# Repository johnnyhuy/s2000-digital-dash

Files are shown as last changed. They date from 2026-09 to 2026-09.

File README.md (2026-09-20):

<h1 align="center">
  Honda H-mark
  S2000 wordmark
</h1>

<p align="center">
  
  
  
  
  
  
</p>

> **Unofficial enthusiast / DIY project.** This repository is **not affiliated with, endorsed by, or associated with Honda Motor Co., Ltd.** Honda, S2000, AP1, AP2, and related marks are trademarks of their respective owners. For **personal and educational use** on the bench. The on-screen odometer is **display-only** - the **OEM cluster must stay plugged** so the factory odometer remains the legal one.

<p align="center">
  <strong>Newline JSON in. Selectable AP1 / AP2 face styles out.</strong><br/>
  Phase 1 bench mock for a Raspberry Pi 5 + Wisecoco-class 7&quot; AMOLED overlay.<br/>
  Not a product, not car-ready, not a replacement for the factory cluster.
</p>

<p align="center">
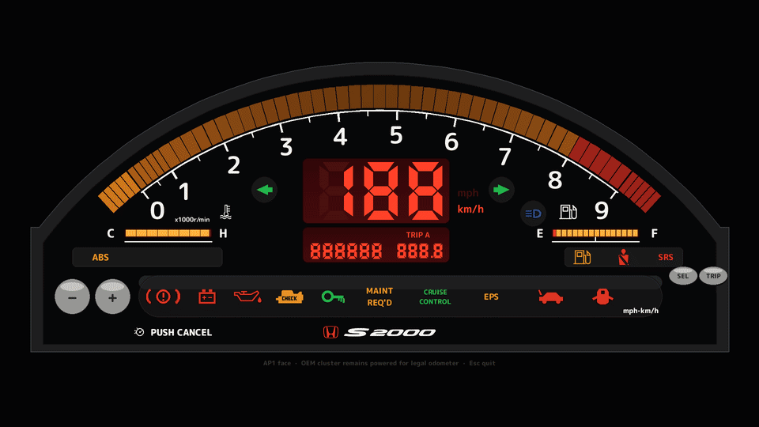
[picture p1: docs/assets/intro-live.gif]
Boot: tach self-test sweep, READY with badges, reveal, then live gauges
  
</p>

<p align="center">
  <sub>Hero is a baked 30 fps intro→live loop (60 fps VP9). Stills are in <a href="shots/"><code>shots/</code></a>. OEM vs UI composites live in <a href="docs/assets/compare/"><code>docs/assets/compare/</code></a>.</sub>
</p>

<p align="center">
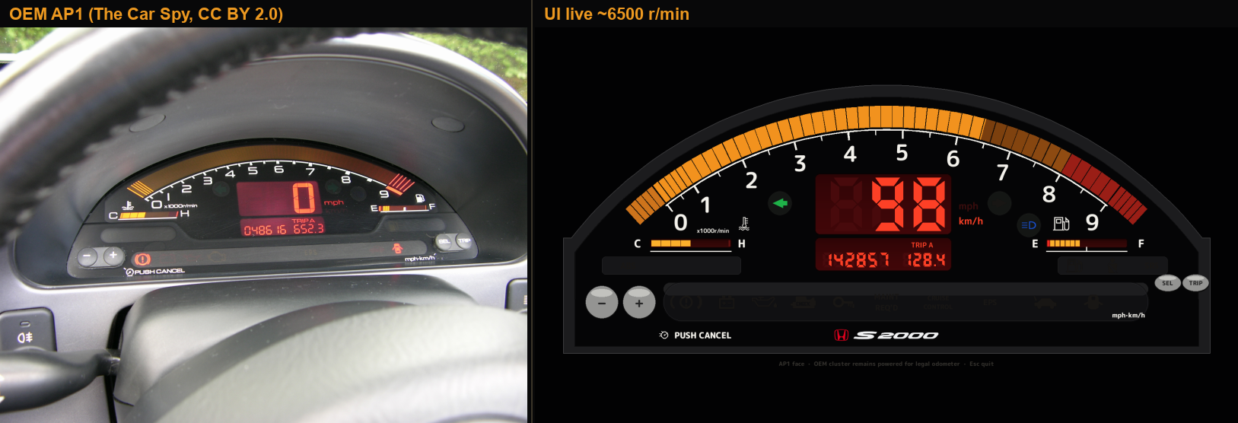
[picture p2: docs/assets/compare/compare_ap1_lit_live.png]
OEM AP1 photo beside the pygame live face
  
</p>
<p align="center">
  <sub>Left: OEM AP1 cluster, <a href="https://www.flickr.com/photos/thecarspy/2644733191/">The Car Spy</a> (<a href="https://creativecommons.org/licenses/by/2.0/">CC BY 2.0</a>). Right: this UI. Sources in <a href="refs/oem/SOURCES.md"><code>refs/oem/SOURCES.md</code></a>.</sub>
</p>

## Features

<table>
<tr>
<td width="50%" valign="middle">

### Face styles (AP1 default, AP2 selectable)

Red 7-seg speed/odo on an **amber tach** in a hooded arched cowl. Flat 2.35:1 elevation - no fake 3D skew.

- **AP1** (default): **horizontal TEMP left / FUEL right** block bars flanking the speed/odo. Tach is the OEM **amber bar graph on a true circular arc** - cells light in 200 rpm steps, red hatch past 9, no needle. Every anchor comes from one shared, photo-derived layout, [`src/face_spec.py`](src/face_spec.py), explained in [`refs/flat/DIMENSIONS.md`](refs/flat/DIMENSIONS.md) and shared with the web harness and the CAD.
- **AP2**: interpretive stacked arched TEMP / FUEL on the right, plus a clock row. Uses [`refs/oem/ap2/`](refs/oem/ap2/) as reference - **not** a pixel-perfect plate.

Toggle in the [web harness](apps/harness/) or `python src/gauge_ui.py --style ap2` (keys `1` / `2` live). Protocol fields stay frozen.

Bar-graph tach **0–9 ×1000** on a circular arc with amber / red hatches past each end, mitred red 7-seg speed, **ODO / TRIP A**, 8-block TEMP and 16-block FUEL. Turn arrows and high beam sit in round wells inside the arc like the OEM; AP1 puts ABS in the left pocket and low fuel / seat belt / SRS in the right pocket. The lower strip carries brake, battery, oil, CEL, immobilizer, maintenance, cruise, EPS, trunk and door warnings. AP2 uses a separate airbag pictogram and relocates the left-side indicators, following the Honda manual.

</td>
<td width="50%">
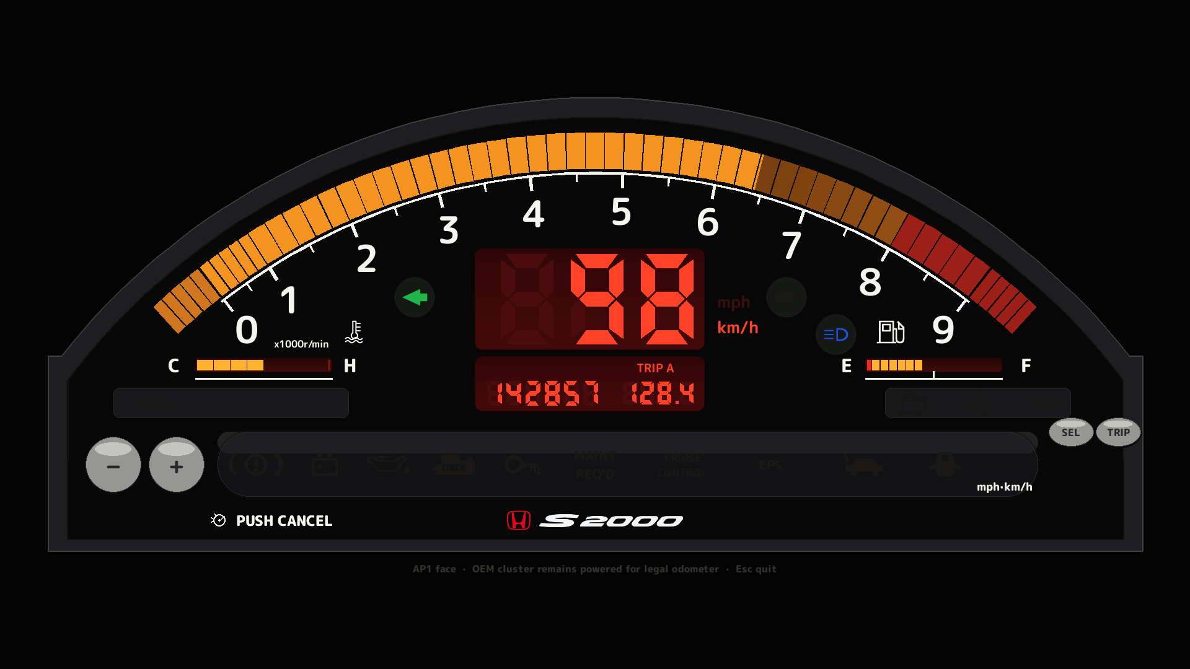
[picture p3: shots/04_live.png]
Live cluster at about 6500 rpm and 98 km/h
  
</td>
</tr>
<tr>
<td width="50%" valign="middle">

### Ignition boot

Skippable with Space or `--no-intro` (web harness: Space or **Skip boot**):

The sweep → branded READY → reveal is a **custom demo animation**, not a verified recording of factory ignition timing. Honda documents individual lamp checks; it does not establish this combined animation.

1. Tach bar fills 0→9 with every lamp and `188` lit (demo bulb check)
2. **READY** with the Honda H-mark and S2000 wordmark
3. Gauge reveal, then live

</td>
<td width="50%">
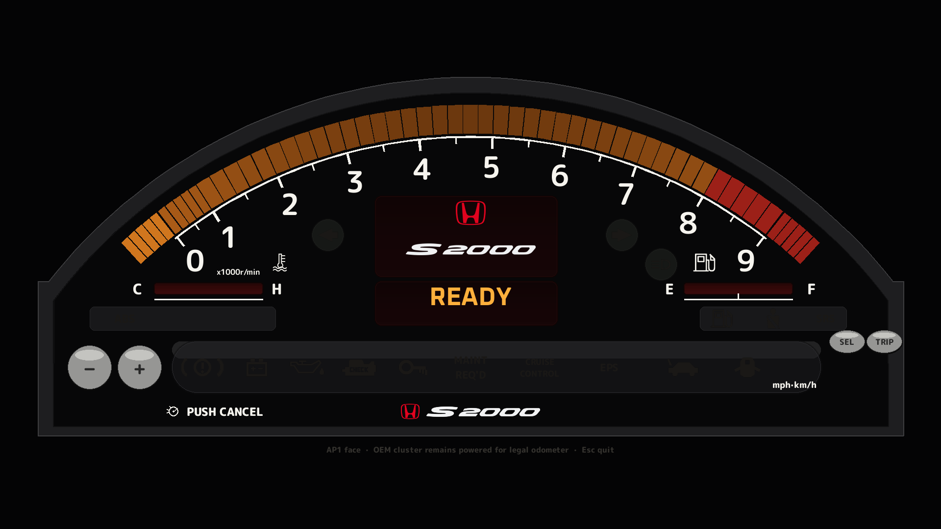
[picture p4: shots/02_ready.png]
READY summary card during boot
  
</td>
</tr>
<tr>
<td width="50%" valign="middle">

### Frozen JSON pipe

One object per line. Field names stay **`rpm`**, **`speed_kmh`**, **`fuel_pct`**, **`ect_c`**, **`batt_v`**, **`odo_km`**, optional **`lamps`**.

Phase 1: `mock_telemetry.py` at 20 Hz. Phase 2: the same schema over UART (`--serial`).

</td>
<td width="50%">
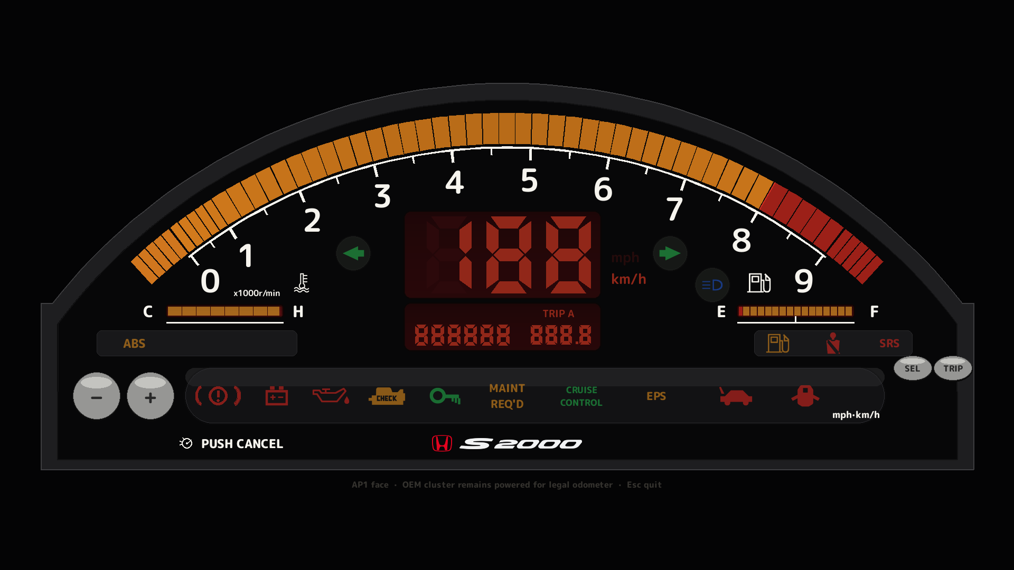
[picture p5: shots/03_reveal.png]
Tach self-test during gauge reveal
  
</td>
</tr>
<tr>
<td width="50%" valign="middle">

### Overlay path

The factory cluster stays powered. This UI is an overlay so the **legal odometer** keeps counting on the OEM unit.

Phase 1 is **wall power** on the bench - no ESP32, no car taps. Phase 2 will add high-Z taps later.

</td>
<td width="50%">
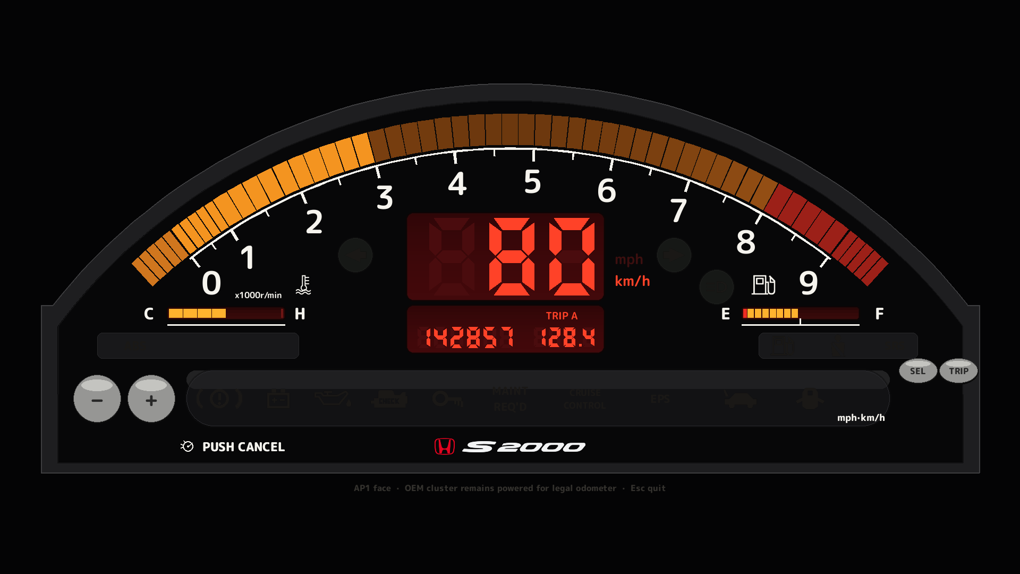
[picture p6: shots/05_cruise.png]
Cruise still with overlay caption under the module
  
</td>
</tr>
<tr>
<td width="50%" valign="middle">

### Placeholder CAD

OpenSCAD in [`cad/`](cad/): overlay 7" bezel + generic connector shells, and an Option 1 **replace-face** stack in [`cad/replace_face/`](cad/replace_face/) whose mask windows and hood crown are generated from the same `face_spec.py` lock as the UI, over a 7" panel pocket. Millimetres are still estimates - bay **callipers required** before any cabin print. **PETG or ASA - not PLA.**

</td>
<td width="50%">
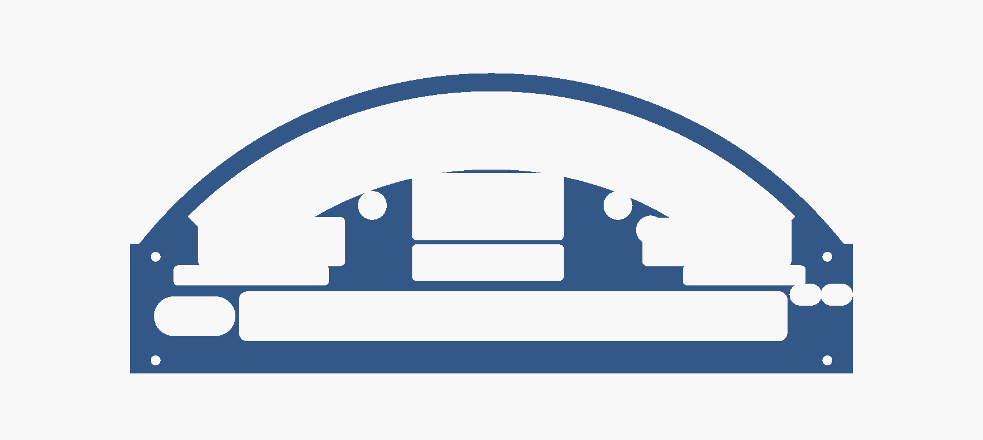
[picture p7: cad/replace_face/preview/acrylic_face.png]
Replace-face mask plate generated from the face lock: tach sector, LCD, side-bar, telltale and button windows
  
</td>
</tr>
</table>

---

## Install

Python **3.11+**. Prefer **[uv](https://docs.astral.sh/uv/)** (`pyproject.toml` + `uv.lock`). Dummy SDL is enough for tests and screenshots; a real display is only needed for the fullscreen Pi session.

```bash
git clone https://github.com/johnnyhuy/s2000-digital-dash.git
cd s2000-digital-dash
uv sync
```

Dev extras (pytest, pyserial for UART mocks):

```bash
uv sync --extra dev
```

`requirements.txt` / `requirements-dev.txt` stay as pip mirrors. On the Pi, `export DISPLAY=:0` if the box boots headless to a desktop session.

## Web cluster harness (no Pi)

Shareable Next.js demo of the same face, drawn as one SVG straight from the exported lock (`apps/harness/lib/faceSpec.json`) - red mitred 7-seg, amber bar-graph tach, side block bars, telltale strip and buttons all share pygame's numbers. Client-side mock loop (play/pause, **AP1 / AP2** face, idle / cruise / VTEC / warn) and the same sweep → READY → reveal boot as the Pi UI. Cluster type is self-hosted M PLUS Rounded 1c; telltales are inline ISO pictograms.

<p align="center">
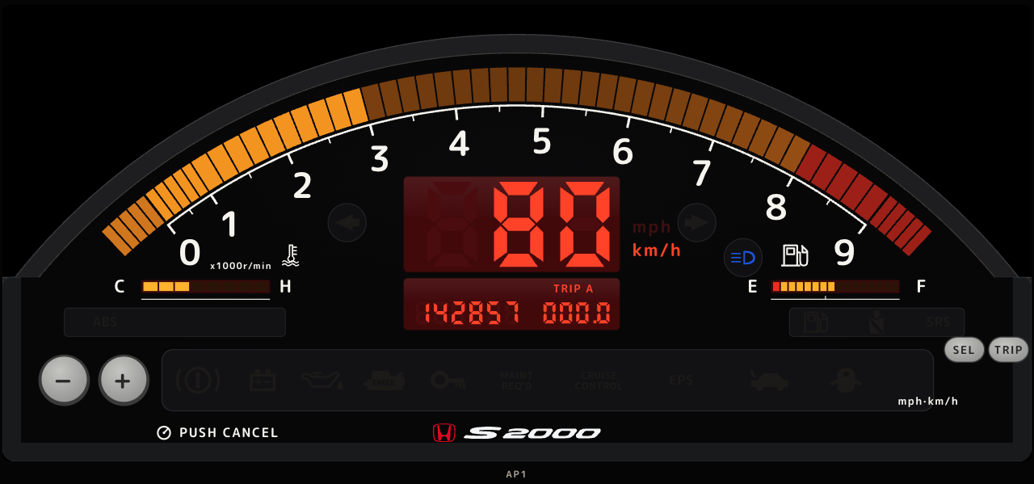
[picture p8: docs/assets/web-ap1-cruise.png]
Web AP1 cruise: digital speed, amber bar graph and shared warning pictograms
  
</p>
<p align="center">
  <sub>Web AP1 cruise. Warn and AP2 stills: <a href="docs/assets/web-ap1-warn.png"><code>web-ap1-warn.png</code></a>, <a href="docs/assets/web-ap2-warn.png"><code>web-ap2-warn.png</code></a>.</sub>
</p>

```bash
cd apps/harness
npm install
npm run dev    # http://localhost:3000  (also /harness)
npm run build
```

**Vercel:** create a project with **Root Directory** `apps/harness` (Next.js preset). See [`apps/harness/README.md`](apps/harness/README.md).

The banner on that page is the same **unofficial DIY / not Honda Motor Co.** disclaimer as this README.

The web page follows the system theme, with an **Appearance** selector for Light / Dark / System. The instrument itself stays black with unchanged warning colours. The choice persists locally.

[Light web preview](docs/assets/web-ap1-light.png) · [Dark web preview](docs/assets/web-ap1-dark.png)

**OLED preview:** open `/display?style=ap1` (or `ap2`) in a fullscreen browser on the Pi. This route uses mock telemetry, hides the web controls, and fits the complete face without stretching or cropping. Pygame `--car --size 1280x720` renders at the chosen panel resolution and uses aspect-preserving fit. Replace `1280x720` with the OLED’s configured native landscape resolution. Neither route establishes physical mounting dimensions.

The target is Johnny's **7-inch OLED + Raspberry Pi**, for a **2001 AP1**. The exact panel model, native resolution and active area are still unrecorded. See [the reference audit](docs/iterations/0018-oem-display-audit.md) for sources, corrected proportions, validation and remaining limits.

## Bench studio and 3D setup

The web workspace now separates the instrument preview from its face, drive-condition
and playback controls. Readouts sit below the preview; raw telemetry is collapsed
until needed. **Replay startup** works without changing the selected face.

Open **3D setup** (`/setup`) to orbit the complete display enclosure, inspect its
assembled, exploded or electronics-only view, select front/rear cameras, or expand
the viewer fullscreen. GLB scenes and a ZIP of CAD source + four prototype STLs
are downloadable from the viewer. The 3D library loads only on this route.

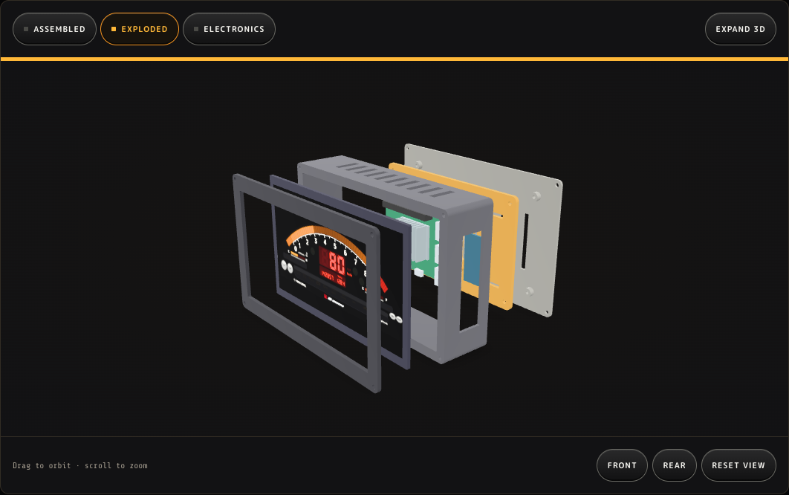
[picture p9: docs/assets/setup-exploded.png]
Digital display setup


The new [`cad/setup/`](cad/setup/README.md) model includes a rectangular OLED frame,
vented enclosure, removable Pi carrier and rear cover, plus Pi/connector/cooler
clearance proxies. It complements the existing arched mask option. The panel and
vehicle-fit dimensions remain provisional; the model is a bench layout, not an
installation-ready housing.

## Run

```bash
# Bench mock pipe (repo root)
uv run python src/mock_telemetry.py | uv run python src/gauge_ui.py

# Same thing from src/
cd src && python mock_telemetry.py | python gauge_ui.py
```

Fullscreen by default. Esc or Q quits.

| Flag | What it does |
| --- | --- |
| `--windowed` | 1920×1080 window instead of fullscreen |
| `--intro` / `--no-intro` | Force or skip the boot sequence (intro is on unless `--smoke`) |
| `--smoke` | Dummy SDL, draw a few frames, exit (CI / Pi check; no live pipe needed) |
| `--size WIDTHxHEIGHT` | Panel render resolution, e.g. `1280x720` (default `1920x1080`) |
| `--screenshot DIR` | Write `01_sweep.png` … `05_cruise.png` into DIR |
| `--serial [PORT]` | Phase 2 UART stub (needs `pyserial`; default `/dev/ttyUSB0`) |
| `--style ap1\|ap2` | Face layout. **ap1** (default) horizontal TEMP/FUEL flanking the speedo; **ap2** arched side gauges |

```bash
# Fast health check (same commands CI runs)
uv sync --extra dev
uv run pytest
SDL_VIDEODRIVER=dummy uv run python src/gauge_ui.py --smoke
uv run python -m mocks.esp32_uart --count 25 --immediate | uv run python src/gauge_ui.py --smoke
uv run python scripts/ui_harness.py --check

# Rebuild stills
uv run python src/gauge_ui.py --smoke --screenshot shots

# OEM | UI side-by-sides
uv run python scripts/compare_oem.py

# Rebuild stills + 30 fps intro GIF / 60 fps VP9 (needs ffmpeg)
uv run python scripts/bake_showcase.py
```

Stdin is newline JSON. Phase 2 UART is the same schema on `--serial`.

## Mocked environments (no hardware)

Pi UI and a future ESP32 source can be exercised in isolation. Field names stay frozen.

```bash
# Headless Pi cluster (dummy SDL - CI / no display)
SDL_VIDEODRIVER=dummy uv run python src/gauge_ui.py --smoke --screenshot /tmp/shots

# Existing bench pipe (mock drive loop → UI)
uv run python src/mock_telemetry.py | uv run python src/gauge_ui.py --windowed

# Mock ESP32 UART emitter → stdout @ 20 Hz (same newline JSON as Phase 2)
uv run python -m mocks.esp32_uart
uv run python -m mocks.esp32_uart --count 40 --immediate --scenario warn

# Mock ESP32 → headless UI (no Pi, no ESP32, no car)
uv run python -m mocks.esp32_uart --count 40 --immediate | uv run python src/gauge_ui.py --smoke --screenshot /tmp/e2e

# Local PTY stand-in for --serial (prints PTY=/dev/pts/N)
uv run python -m mocks.esp32_uart --pty --count 40 --immediate
# then, in another shell: uv run python src/gauge_ui.py --serial /dev/pts/N
```

`mocks/esp32_uart.py` is a Python stand-in, not flashed firmware. Scenarios: `drive` (cruise loop + OEM extra lamp keys off), `warn` (low fuel / hot ECT / every telltale), `idle`.

## Protocol

See [`src/protocol.py`](src/protocol.py). **Do not rename fields.**

Required: `rpm`, `speed_kmh`, `fuel_pct`, `ect_c`, `batt_v`, `odo_km`

Optional: `lamps` object (`oil`, `cel`, `abs`, `turn_l`, `turn_r`, `high_beam`, `fog`, `fuel_low`, `batt_warn`, `ect_hot`, …)

## Layout

- `src/protocol.py` - shared schema + parse/validate
- `src/mock_telemetry.py` - 20 Hz fake drive loop → stdout (Pi bench pipe)
- `src/face_style.py` - `ap1` / `ap2` face enum (layout only)
- `src/face_spec.py` - **the face lock**: AP1/AP2 arc geometry, windows, lamps, buttons; exports `faceSpec.json` + `face_lock.scad`
- `src/gauge_ui.py` - pygame 1920×1080 cluster + intro + `--style`, drawn from the lock
- `src/lcd_digits.py` - Mitred 7-segment speed / odo with unlit segments, no bloom
- `scripts/measure_oem_ui.py` - perspective-corrected landmark / circle-fit measurement of the OEM photo
- `src/serial_reader.py` - Phase 2 UART stub + `SerialLineReader` (pyserial optional)
- `mocks/` - mock ESP32 UART emitter + in-memory / PTY serial (no firmware)
- `tests/` - pytest (unittest + harness ahash + e2e pipe)
- `refs/flat/` - `DIMENSIONS.md` (arc lock explained) + historic flat SVG
- `refs/oem/` - curated AP1 photos + labelled AP2 reference (caution: not a plate) + `SOURCES.md`
- `assets/icons/` - OEM telltale SVG/PNG atlas (tinted at draw time)
- `cad/` - OpenSCAD placeholders (overlay bezel + connectors + `replace_face/`). PETG/ASA notes stay here.
- `shots/` - sweep / ready / reveal / live / cruise stills
- `docs/assets/` - Honda / S2000 marks, intro GIF, VP9 hero, OEM|UI compares
- `scripts/bake_showcase.py` - regenerate stills + 30 fps hero
- `scripts/ui_harness.py` - screenshot / ahash harness
- `scripts/compare_oem.py` - OEM photo | UI composites
- `pyproject.toml` + `uv.lock` - uv project
- `apps/harness/` - Next.js App Router web cluster (Vercel; Root Directory `apps/harness`)
- `.github/workflows/ci.yml` - uv pytest + pygame smoke/e2e + web harness build on push/PR to `main`

## CAD placeholders

See [`cad/README.md`](cad/README.md). Overlay 7" bezel + connector shells are dimensional guesses for a wall-powered bench (Pi 5 + 7" AMOLED). Option 1 (full arched face replace) lives in [`cad/replace_face/`](cad/replace_face/): the mask's display windows and the hood crown are generated from the same `face_spec.py` lock as the UI, and the tray carries a parametric 7" panel pocket. None of this is a Honda drop-in.

- Callipers required before any cabin print
- Print **PETG or ASA**, never PLA in a sun-soaked dash
- `bash cad/replace_face/export.sh` regenerates `face_lock.scad` → `stl/` → cleaned `print/{stl,obj,step}` + `preview/assembly.glb` (OpenSCAD + `uv --extra cad`, no Blender)

## Disclaimer

This is an **unofficial** enthusiast / DIY bench project.

- **Not affiliated with, endorsed by, or associated with Honda Motor Co., Ltd.**
- Honda, S2000, AP1, AP2, and related names are trademarks of their respective owners
- Personal / educational use only
- The overlay odometer is **display-only**. Keep the **OEM cluster plugged** for the legal odometer
- Phase 1 is not vehicle wiring. Do not treat placeholder CAD as production geometry
- Honda H and S2000 marks are Honda trademarks; sources are recorded in `docs/assets/BRANDING.md`

## Community

Bench notes and Phase 2 tap ideas belong in [Issues](https://github.com/johnnyhuy/s2000-digital-dash/issues). Keep protocol field names stable so mock, UI, and a future UART source stay interchangeable.

This is a small overlay experiment, not a product landing page. If the **AP1** face geometry drifts, the lock file in `refs/flat/` wins. AP2 is a separate interpretive layout.

## Repository name

The live GitHub repo is [`johnnyhuy/s2000-digital-dash`](https://github.com/johnnyhuy/s2000-digital-dash) (renamed from `s2000-ap1-digital-dash`; old URLs redirect).

Historical AP1 paths (`refs/flat/ap1_*`, `refs/oem/lit/lit_ap1_*`, `docs/assets/compare/compare_ap1_*`) stay. They are AP1-specific and labelled as such.

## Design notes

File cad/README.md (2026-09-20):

# Placeholder CAD (not production)

These parts are **dimensional guesses**. They are **not** AP1-accurate and
must not go in the car until the bay and connectors are measured with
callipers.

Two tracks live here on purpose - do not mix them:

| Track | Folder | What it is |
| --- | --- | --- |
| Overlay (7" bench bezel) | `bezel_7in_placeholder.scad` + connector shells | Rectangular frame for a Wisecoco-class panel in front of the OEM cluster. Sources only; export STL locally. |
| **Option 1 replace-face** | [`replace_face/`](replace_face/) | Full arched face stack generated from the `src/face_spec.py` lock (mask windows + hood crown) over a 7" panel pocket. One solid per STL; cleaned printables in `replace_face/print/` + `preview/assembly.glb`. Callipers TBD. **PETG / ASA, not PLA.** |

## Overlay path

The factory cluster stays plugged. This bezel is an overlay frame for a
display that sits in (or in front of) the bay - not the arched
`replace_face/` stack. The legal odometer keeps counting on the OEM
cluster. Phase 1 is wall power on the
bench. Phase 2 will add high-Z taps later - these connector shells are
**not** those taps and are **not** Honda drop-ins.

## Callipers required before any cabin print

Do not print `bezel_7in_placeholder.scad` for the dash until you have
measured the real opening. Do not print the connector shells onto a
factory harness.

### Measure list

Panel / bay

- Cluster bay opening: width × height × depth, including any lip or radius
- Distance from glass plane to bay rear / harness
- AMOLED module overall: width × height × thickness (incl. PCB + stiffener)
- Active area: width × height, and offset from module edges
- Mounting hole pattern (or tape / clip points) and fastener size
- Mini-HDMI / FPC tail exit: side, width, stack height
- Sight lines / hood so the cluster does not reflect on the windscreen

Connectors (both ends)

- Pin count and row count
- **Pitch** and row spacing (unknown until callipers - the SCAD default 2.54 mm is a hobby guess)
- Pin / socket diameter and length
- Housing envelope, keying, latch, and polarizer side
- Wire gauge and strain-relief need
- Approach angle of the OEM loom (do not force a bend)

## Print notes

- **PETG or ASA** for anything that will see cabin heat.
- **Do not use PLA** in the cabin. It softens and creeps on a sun-soaked dash.
- Keep fits loose until the second measure. First prints are tracing templates.
- Overlay path: export STL locally. Option 1 raw STLs live in `replace_face/stl/`; cleaned printables in `replace_face/print/`.
- Slice with enough perimeters on the bezel lip so the panel cannot punch through.

## Files

| File | What it is |
| --- | --- |
| `bezel_7in_placeholder.scad` | Frame for a ~7" landscape AMOLED (~164×100 overall / ~154×87 active placeholders) |
| `connector_male_placeholder.scad` | Generic multi-pin male shell |
| `connector_female_placeholder.scad` | Generic multi-pin female shell |
| `replace_face/` | Option 1 full-face replace stack - see that folder’s README |

Open in [OpenSCAD](https://openscad.org/) and F6 to render after you edit the measured numbers.

## Complete digital-screen setup

[`setup/`](setup/README.md) adds a rectangular OLED enclosure, rear cover and
removable Pi carrier. Four closed STL prototypes, source SCAD, embedded-screen
GLBs and a downloadable ZIP feed the web `/setup` inspector. Panel and bay
dimensions remain provisional. This complements the arched replace-face mask.

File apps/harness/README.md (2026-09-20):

# S2000 Digital Dash - web cluster harness

Shareable Next.js App Router demo of the OEM face - red mitred 7-seg speed/odo, amber **bar-graph tach on a circular arc**, flanking TEMP / FUEL block bars, telltale strip and buttons - rendered as a single SVG. Same frozen JSON fields as the Pi bench (`rpm`, `speed_kmh`, `fuel_pct`, `ect_c`, `batt_v`, `odo_km`, optional `lamps`). Client-side mock drive - no Raspberry Pi, no ESP32.

Geometry is **not** hand-placed here: `lib/geometry.ts` reads `lib/faceSpec.json`, exported from `src/face_spec.py`, so the SVG and pygame share every anchor (`uv run python src/face_spec.py` to refresh). Tach cells light in 100 rpm steps with the red hatch past 9; numerals sit in the well in bundled M PLUS Rounded 1c. Off telltales stay just above black so the strip still reads; cruise lights the ISO high beam; green turn lamps pulse at about 85 flashes/min. Inline ISO pictograms (`components/LampIcons.tsx`) keep the strip sharp. TEMP uses the OEM coolant-wave thermometer; FUEL is a pump with hose.

**Face styles:** **AP1** (default - horizontal TEMP / FUEL flanking the speedo) and **AP2** (interpretive stacked arched side gauges + clock). Toggle on the desk or open `/?style=ap2`. AP2 is **not** a measured plate.

**Unofficial DIY.** Not affiliated with Honda Motor Co., Ltd. Title mark is an original geometric H, not Honda trademark artwork.

## Local

```bash
cd apps/harness
npm install
npm run dev
```

Open [http://localhost:3000](http://localhost:3000) (also `/harness`).

```bash
npm run build
npm test
```

Play / pause, **AP1 / AP2** face presets, and drive presets: **Idle**, **Cruise**, **VTEC**, **Warn**. Space skips the ID.4-style boot (sweep → READY → reveal). Telltale pictograms live in `components/LampIcons.tsx`; SVG plates in `public/icons/` still match `assets/icons/`. Current web stills: [`docs/assets/web-ap1-cruise.png`](../../docs/assets/web-ap1-cruise.png), [`web-ap1-warn.png`](../../docs/assets/web-ap1-warn.png), [`web-ap2-warn.png`](../../docs/assets/web-ap2-warn.png).

## Vercel

Create a project rooted at **`apps/harness`**.

1. [vercel.com/new](https://vercel.com/new) → import `johnnyhuy/s2000-digital-dash`
2. **Root Directory**: `apps/harness`
3. Framework preset: Next.js (auto)
4. Deploy

The Vercel project itself can be renamed to **s2000-digital-dash** for consistency; Root Directory stays `apps/harness`.

CLI from this folder:

```bash
npx vercel --yes
```

`vercel.json` in this directory sets `framework: nextjs`.

## Appearance and OLED preview

Appearance supports System, Light and Dark and saves the choice locally. Instrument colours remain unchanged. `/display?style=ap1` (or `ap2`) hides the page controls and fits the face to the viewport without stretching. This is still a mock telemetry preview, not a hardware connection. The exact 7-inch OLED model and active area remain unconfirmed.

## Workspaces

- `/`: instrument studio with grouped controls, telemetry readouts and collapsible JSON.
- `/setup`: interactive CAD inspector (assembled / exploded / electronics), camera views, fullscreen and downloads. Loads the locally bundled `@google/model-viewer` only here.
- `/display?style=ap1`: control-free simulated OLED output.

Regenerate shipped 3D files with `uv run --extra cad python cad/setup/export.py`
from the repository root. The Pi and panel models are clearance references, not
verified manufacturing drawings.

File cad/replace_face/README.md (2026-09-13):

# Option 1 - replace-face printable stack (arc lock)

**This is not a verified AP1 drop-in.** Do not print these parts for the
car until you have measured the cluster bay **and** the OEM face with
callipers. Every critical size in the SCAD is marked `PLACEHOLDER` or
`TODO measure`. The millimetre envelope (170 × 72.3 mm, 2.35:1) is
**ESTIMATED** from [`refs/flat/DIMENSIONS.md`](../../refs/flat/DIMENSIONS.md).

Mask plate - every window is a display aperture

## One lock, three renderers

The face geometry is **not** typed into the SCAD. `src/face_spec.py` is the
single source of truth for the AP1 / AP2 face (tach arc centre + radii,
hood crown, LCD windows, side bars, telltale spots, buttons). It exports:

| Output | Consumer |
| --- | --- |
| `apps/harness/lib/faceSpec.json` | Next.js SVG harness |
| `cad/replace_face/face_lock.scad` | this stack (`dims.scad` includes it) |
| in-process | pygame (`src/gauge_ui.py`) |

So the pixels the panel shows and the holes the mask cuts come from the
same numbers. To move anything: edit `face_spec.py`, then
`bash cad/replace_face/export.sh`.

`face_lock.scad` is in top-left fractions (x / w / radii of module width,
y / h of module height). `dims.scad` converts to millimetres and flips to
y-up with `X() Y() W() H()`; arc maths uses `tach_pt()` / `crown_pt()`.

## How the digital face maps onto the OEM plate

The OEM face is a printed plate over a segment LCD. Here the whole face is
drawn by a **7" 16:9 AMOLED** (Wisecoco-class, ~164 × 100 module, ~154 × 87
active - PLACEHOLDER) and the mask only leaves **windows** where the OEM
face had backlit or printed-on-glass content:

- one **annular sector** from just outside the bar-graph band to just
  inside the numerals (band, ticks, 0–9, hatch overrun) - the panel draws
  the amber bar graph exactly as `gauge_ui.py` does
- **speed** and **odo / trip** LCD windows
- **TEMP** and **FUEL** block bars with their icons and C/H · E/F letters
- three round **arc telltales** (turn L/R, high beam)
- the **telltale strip** and the two lower **panels**
- button holes and four (fictional) alignment holes

Every window is clipped to the hood inset by `min_rim` so the mask keeps a
rim where the band runs under the crown lip. PUSH CANCEL, mph·km/h and
the cowl stay printed on the plate, as on the OEM.

The panel's active area is centred on the module: it is **taller** than
the face (87 vs 72.3) and **narrower** (154 vs 170). Every display window
falls inside it. The −/+ rocker and SEL / TRIP ovals sit over the panel's
dead border, so their switch wells are **skipped** in the tray
(`point_in_rect` check) until a real panel drawing says where a switch can
go. That is an open problem, not a solved one.

## What you get

Each printable is **one solid**.

| File | Part | Material |
| --- | --- | --- |
| `backlight.scad` → `backlight.stl` | Tray: hood silhouette + panel envelope, face rebate, 7" pocket, board cavity, FPC / cable notches | PETG / ASA |
| `backlight_web.scad` → `backlight_web.stl` | 0.9 mm light-baffle web between panel glass and mask | PETG / ASA |
| `acrylic_face.scad` → `acrylic_face.stl` | Arched mask with the display windows above | laser acrylic, or PETG / ASA as a tracing template |
| `button_rocker.scad` → `button_rocker.stl` | −/+ PUSH CANCEL rocker (no stem - switch UNKNOWN) | TPU / silicone |
| `button_sel.scad`, `button_trip.scad` | SEL / TRIP ovals | TPU / silicone |

Preview only (never export as a printable): `assembly.scad` (exploded
stack, F5; `-D print_placement=true` echoes part offsets),
`rubber_buttons.scad` (three buttons on one plate).

Shared maths: `face_lock.scad` (generated), `dims.scad` (mm + stack),
`outline.scad` (2D silhouette + windows), `parts.scad` (3D solids).

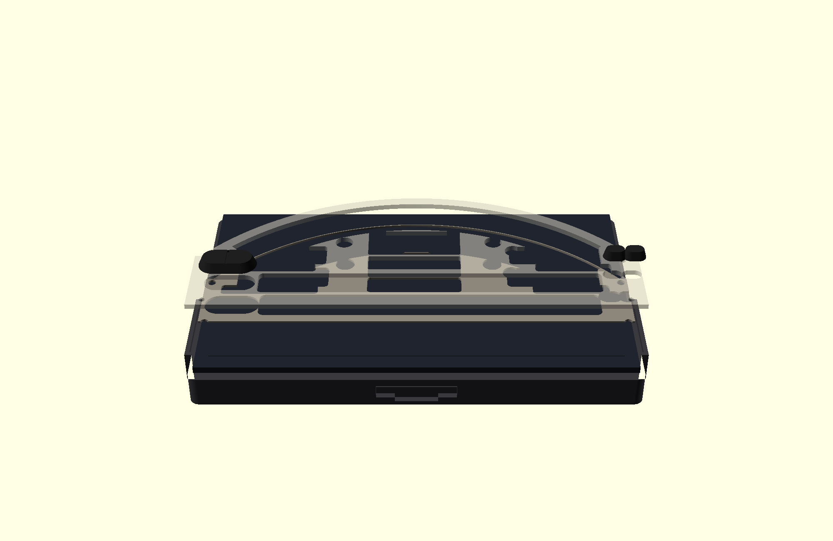
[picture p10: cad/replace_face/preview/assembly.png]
Exploded stack: tray, 7" panel, web, mask, buttons


## Regenerate

```bash
bash cad/replace_face/export.sh            # lock → STL → print/ + preview/
uv run --extra cad python cad/replace_face/mesh_export.py --explode 0
```

`export.sh` runs `face_spec.py`, one OpenSCAD export per part into
`stl/` (raw CGAL dumps, one body each), then `mesh_export.py` (trimesh,
no Blender): merge / degenerate / winding clean, refuses anything not
watertight, writes `print/stl`, `print/obj`, faceted `print/step`
(honest tessellation - not a B-rep rebuild) and the coloured exploded
`preview/assembly.glb`. Needs OpenSCAD on `PATH` (`brew install --cask
openscad@snapshot` on macOS) and `uv`.

## Stack (front → rear)

1. **Rubber buttons** - TPU 95A or cast silicone.
2. **Mask** - 2 mm PLACEHOLDER. Black / smoked acrylic for real, PETG / ASA
   print as a template.
3. **Baffle web** - `web_t` 1.0 mm gap, 0.9 mm part. Layout only, not optics.
4. **7" AMOLED** - bought module in the tray pocket, glass toward the mask.
   `panel_*` in `dims.scad` are PLACEHOLDER; check the vendor drawing.
5. **Tray** - floor, rim, board cavity under the panel. Outer rim is
   `offset(wall)` around the hood + panel envelope - a print wall, **not** a
   measured bay clip.
6. **Switches under the buttons** - not modelled (see the open problem above).

| Part | Use | Do not use |
| --- | --- | --- |
| Tray, web, printed mask proxy | **PETG or ASA** | **PLA** - creeps on a sun-soaked dash |
| Buttons | TPU 95A, or silicone from a printed master | PLA |
| Production mask | Cast acrylic (laser) | PLA |

## Measure list (callipers required)

- [ ] OEM face overall width × height × thickness; hood crown radius and spring points
- [ ] Bay opening width × height × depth, lip, corner radius, fastener / clip pattern - **do not drill from this CAD**
- [ ] Glass plane to bay rear; sight line so the stack does not reflect in the windscreen
- [ ] Panel module outline, active area, thickness, FPC exit - replace `panel_*`
- [ ] Rocker, SEL, TRIP centre-to-centre and outline; whether PUSH CANCEL is the rocker push
- [ ] Button travel and the actual switch / encoder, and where it can live beside the panel
- [ ] Mask thickness; alignment pin locations (the four holes here are fiction)

## What this is not

- Not a verified AP1 drop-in, not a factory-harness replica
- Not the overlay-only 7" bezel (`cad/bezel_7in_placeholder.scad`)
- Not optically designed; not a finished cabin part

If the face lock moves, it moves in `src/face_spec.py` - never by hand
in `face_lock.scad` or a mesh.

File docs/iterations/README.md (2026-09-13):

# The loop

OEM-vs-UI face polish runs in **six discrete tracks**. Each iteration
captures, diffs, fixes **one** track, verifies, pushes, merges. Stop only
when the OEM | UI composite in `docs/assets/compare/` passes a same-room
eyeball test.

## Tracks (one per PR, never bundled)

| # | Track | Touches | Acceptance |
| - | ----- | --- | --- |
| 1 | **graphics** | icon art, tick glyphs, bezel marks, bar-graph cell / hatch shape | OEM pictogram proportions + tick direction match the lit reference |
| 2 | **colour** | amber band, redline, LCD red, bloom | Palette and bloom match the lit AP1 reference |
| 3 | **position** | element anchors, arc centre / radii, crown geometry - edited in `src/face_spec.py` only | `refs/flat/DIMENSIONS.md` locks hold within ±0.5% in pygame, SVG and CAD |
| 4 | **size** | digit height, band thickness, numeral weight | OEM proportions hold at the 1920×1080 canvas |
| 5 | **motion** | bar-graph fill lag, lamp pulse, boot phases | Smoothing constants match the lit reference timing |
| 6 | **font** | tach numerals, LCD digits, labels | Same family/weight/style as the OEM reference; weight + spacing match |

A PR that touches more than one track is **rejected**. Split it.

## Reference table (locked)

| Use | File |
| --- | ---- |
| AP1 lit photos | `refs/oem/lit/` |
| Telltale / pictogram plates | `refs/oem/plates/` |
| AP1 face percent-lock | `refs/flat/DIMENSIONS.md` |
| AP1 flat elevation | `refs/flat/ap1_cluster_flat.svg` / `.png` |
| AP2 reference (interpretive only) | `refs/oem/ap2/` |
| Source licences | `refs/oem/SOURCES.md` |

AP2 photos are **not** an AP1 plate. Do not regress AP2 arches onto AP1.

## Iteration format

`docs/iterations/<NNNN>-<short>.md`. Each iteration captures:

1. **Capture** - what was rendered (`docs/assets/compare/...`) and the OEM side-by-side
2. **Diff** - table of deltas per track with the OEM reference cited
3. **Fix plan** - which track this iteration fixes, which it leaves for later
4. **Acceptance** - how to verify this single-track fix
5. **Verify** - pytest + smoke + screenshot + composite diff notes
6. **Hand-off** - PR title, branch, scope, what is **not** in scope

## Housekeeping (separate PRs, never bundled with face polish)

| Track | Where |
| ----- | ----- |
| docs cleanup | `docs/`, `README.md` |
| dead code | `src/`, `scripts/`, `mocks/` |
| CAD revision (calliper-driven, no cabin prints) | `cad/`, `cad/replace_face/` |
| symbols / icons (OEM atlas tints, SVG source of truth) | `assets/icons/`, `scripts/write_icon_svgs.py`, `scripts/rasterize_icons.py` |

Housekeeping PRs never touch face code. Face PRs never touch docs / CAD /
icons unless the diff is purely a re-bake of generated artefacts (stills,
compare PNGs, intro GIF) caused by a code change.

## Eyeball test

The loop stops when `docs/assets/compare/compare_ap1_lit_live.png` passes a
same-room eyeball check against `refs/oem/lit/lit_ap1_carspy_cluster.jpg`
on the AP1 face (left = OEM, right = UI). Each iteration must move the
match closer - never further.

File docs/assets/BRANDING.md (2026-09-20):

# Brand marks

`honda-h-mark.svg` and `s2000-badge.svg` are the **public logo files**,
not DIY retraces. This unofficial project is **not affiliated with or
endorsed by Honda Motor Co., Ltd.** The marks remain Honda trademarks.

- Honda H-mark: automotive H emblem (`#E40521`). Letterforms are
  PD-textlogo / Simple Icons Honda (CC0).
- S2000 wordmark: traced from Wikimedia Commons
  [File:S2000-logo.png](https://commons.wikimedia.org/wiki/File:S2000-logo.png)
  (PD-textlogo; Brands of the World). Original PNG is
  `brand/S2000-logo.png`. `s2000-badge-on-dark.svg` is the same path
  in off-white for the black cluster / masthead.

The older geometric H (`honda-unofficial-mark.svg`) stays in the tree
as history. The live GitHub repo is `johnnyhuy/s2000-digital-dash`.

Cluster type is **M PLUS Rounded 1c** Bold / ExtraBold (tach numerals,
C/H, E/F, bezel and LCD legends) - the closest OFL match to the OEM plate's
rounded gothic. **Oxanium** sets the READY card and masthead; **Share Tech
Mono** is the harness JSON / protocol face. Speed and odo are **red 7-seg**
with mitred 45° joints, matching the AP1 photo. Faces live under
`assets/fonts/` (SIL OFL); the web harness self-hosts the same files from
`apps/harness/app/fonts/`. DejaVu remains the pygame fallback when those
files are absent.

The tach is the OEM **bar graph on a true circular arc**: an unlit band
grading `#6c380e` → `#ac5c18` toward both ends with hairline cell lines,
amber `#f49420` cells lighting in 200 rpm steps, amber hatch below 0 and
red hatch above 9 (`#ff3c28` when lit). There is no needle in either
renderer. The hood crown is a second circle with a thin off-white lip just
outside the band. LCD red is `#ff4228` with a faint `#4a0c0e` 188 / 888888
ghost and a soft bloom. The LCD well is near-black with a quiet vignette,
not a brown overlay. TEMP uses the OEM coolant pictogram
(stem, bulb, ticks, two waves); FUEL is a pump with window, hose, and
nozzle. Telltales: red `#e22820`, amber `#ec941c`, green `#22b84c`, ISO
high-beam blue `#1c54d8` (never neon cyan). Off lamps sit just above black
(`#1a1816` on the web strip, `#1a1816` in pygame) so the row still reads
without competing with lit bulbs. Icons are white-on-transparent ISO
silhouettes under `assets/icons/`, tinted at draw time. The web strip
draws the same pictograms inline (`LampIcons.tsx`).

Boot motion is the car's ignition self-test (bar 0→9, all lamps, `188`)
then a READY card with the Honda H-mark and S2000 wordmark, then reveal.
Preset buttons on the web harness snap the face so Idle / Cruise / VTEC /
Warn are readable immediately. Switching AP1 / AP2 replays the boot.
PUSH CANCEL is a small dial mark beside its legend under the −/+ rocker.

Pictograms are reviewed redraws, not certified Honda artwork. `scripts/export_web_icons.py` generates React plates from the same SVG/PNG masters used by pygame, including alpha-crop sizing. Source comparisons and limits are in `docs/iterations/0018-oem-display-audit.md`.

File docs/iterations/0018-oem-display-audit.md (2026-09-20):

# OEM face and replacement-display audit

This pass covers the requested combined symbol, proportion and web-theme revision.
The target is a 7-inch OLED driven by a Raspberry Pi. The user's Obsidian
installed-parts inventory identifies the car as a 2001 AP1; no exact OLED model,
resolution or active dimensions were found in that vault. Existing 154×87 mm
active-area and CAD measurements remain placeholders.

## Evidence

- [Honda 2003 S2000 manual](https://techinfo.honda.com/rjanisis/pubs/OM/AH/AS20303OM/enu/S20303OM.pdf), printed p.45: AP1 warning locations and identities.
- [Honda 2005 S2000 manual](https://techinfo.honda.com/rjanisis/pubs/OM/AH/AS20505OM/enu/S20505OM.pdf), printed pp.39, 44: AP2 instruments and warnings.
- Existing Car Spy lit AP1 and S2KI AP2 photos under `refs/oem/`.
- User's local `refs/oem/bench/oem_ap1_bench.png`: inspect only the upper OEM
  cluster; the lower half is an aftermarket display, not an OEM AP2 reference.
  This pre-existing untracked file is not redistributed by this change.

The manuals show North American configurations. They establish symbol identity
and relative layout, not all Australian-market legends or physical dimensions.
The current circular arc and font remain approximations; no claim of pixel-perfect
geometry, exact startup timing or verified hardware fit is made.

## Corrections

- AP1 speed and odometer windows were undersized. Speed digit height goes from
  11.2% to 19.4% of the face height, with a separate lower odometer/trip window.
- Side bars move outward, with readable symbols and gutters around numerals.
- One half-thousand minor tick between major marks, as visible in the references,
  replaces four minors. The existing 200 rpm bar cells are retained.
- ABS moves to AP1's left pocket. Fuel-low, seat-belt and SRS occupy the right
  pocket. Immobilizer, cruise, trunk and door are in the lower strip.
- AP2 gets an actual airbag symbol, distinct from the belt reminder; ABS/EPS/belt
  move into the left well, with turns beside the speed display. C/H and E/F sit
  inside their half-ring gauges instead of colliding with their endpoints.
- Oil-can silhouette and droplet fit inside their master artwork. Coolant and
  pump art is shared across renderers, as are all pictogram plates. React code is
  generated from the SVG/PNG masters with the same alpha-crop sizing as pygame.
- Synthetic pixel-grid lines are removed. Steady green indicators no longer
  pulse just because they are green; state comes from telemetry.
- The custom READY screen puts the real marks and READY inside the central
  windows. Removed crowded diagnostic chips. This remains a custom boot sequence.
- Web controls, text, logos, focus states and JSON support System/Light/Dark.
  Rounded charcoal switches, cluster typography and amber selected indicators
  match the instrument in both page themes, including the appearance selector.
  The instrument retains its black field and warning colours in every theme.
- `/display?style=ap1` or `ap2` provides a control-free, aspect-preserving OLED
  preview. It still uses mock data. Pygame `--car` now fits height as well as width; `--size WIDTHxHEIGHT` reaches the actual render loop and screenshot path.

## Reproduce

```sh
uv run python src/face_spec.py
uv run python scripts/write_icon_svgs.py
uv run python scripts/rasterize_icons.py
uv run python scripts/export_web_icons.py
SDL_VIDEODRIVER=dummy SDL_AUDIODRIVER=dummy uv run pytest
SDL_VIDEODRIVER=dummy uv run python scripts/ui_harness.py --check
cd apps/harness
npm test
npm run lint
npm run build
```

Visual acceptance includes AP1/AP2 bulb-check, live, warning and READY frames;
light/dark and mobile screenshots; unchanged instrument colours under either
theme; and no clipping/stretching in the OLED preview. Regression tests measure
actual digit runs, numeral ink bounds, icon-generation parity and panel fit.
Generated CAD follows the updated lock, but is still a provisional design.

## Verification result

- 131 Python tests; 24 web tests; ESLint and production build pass.
- Headless smoke with/without intro, UI hashes and mock UART pipe pass.
- Browser: both styles in light/dark, persisted override, system changes, 390 px mobile, five OLED viewport sizes; no page errors.
- CAD export completes with watertight solids. Prior committed meshes were stale relative to the shallower arc; regenerated mask bounds are 170 × 70.51 mm and remain provisional.
- AP1/AP2 self-test frames, comparison images, boot recording and theme screenshots refreshed.

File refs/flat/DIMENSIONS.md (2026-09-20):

# Face dimensions - the arc lock

Canonical geometry for the **AP1** (default) and **AP2** face styles. The
numbers live in **`src/face_spec.py`** - this page explains them; if the
two disagree, the Python wins. The spec exports the same lock to the web
harness (`apps/harness/lib/faceSpec.json`) and the replace-face CAD
(`cad/replace_face/face_lock.scad`), so pygame, SVG and the printed mask
cannot drift apart.

Percentages are of the **module bounding box**, origin top-left. `x`,
`w` and every radius are fractions of module **width**; `y` and `h` are
fractions of module **height**. Arc centres are given in both.

Provisional design envelope (not a measured OEM face): **170 mm × 72.3 mm** → **2.35:1**.

## Evidence

- OEM lit photo: `refs/oem/lit/lit_ap1_carspy_cluster.jpg` (Car Spy, CC BY 2.0)
- Historic illustrative plates and estimated measurement JSON: `refs/oem/plates/`
- AP2 reference (interpretive): `refs/oem/ap2/`
- Flat elevation (historic, parabola era): `refs/flat/ap1_cluster_flat.svg`
- Measurement script: `scripts/measure_oem_ui.py` (perspective-corrected
  landmarks from the Car Spy photo; circle fit through the 0/5/9 ticks)

## What changed from the parabola lock

The previous lock drew the tach as a quadratic bezier and placed elements
by eyeballed `%` constants spread across `gauge_ui.py`. Fitting a circle
through the OEM tick marks shows the real cluster is a **true circular
arc** whose centre sits well **below** the module - the band is a shallow
cap, not a parabola - and the hood crown is **concentric** with it: the
band hugs the cowl with a constant hairline gap all the way round.
Everything below is derived from that one circle.

## Silhouette

| Item | AP1 / AP2 |
| --- | --- |
| Module aspect | **2.35:1** |
| Bottom | flat |
| Hood crown | circle **concentric with the tach** `(50 %, 148.7 % H)`, r = band `r_out` + **1.4 % W** well = **60.4 % W**; cowl lip **1.8 % W** outside it |
| Crown top | y ≈ **2.6 %** (lip) then a dark well; band apex at **10 % H** |
| Spring line | y = **58 %** - crown meets the flat lower bezel; springs land at x ≈ 5 % / 95 % |
| Lower bezel | full width below the spring; strip and buttons live here |

## Tach arc

| Item | AP1 | AP2 |
| --- | --- | --- |
| Centre | `(50 %, 148.7 % H)` | same (shared housing, concentric crown) |
| Band outer / inner radius | 59.0 % / 55.7 % W | same |
| Baseline (white line) radius | 55.3 % W | same |
| Numeral radius | 51.9 % W | same |
| 0 → 9 sweep (screen angles) | **−127.8° → −52.2°** (75.6°) | −132° → −74° (58°) |
| 0 tick / 9 tick | (17 %, 47 %) / (83 %, 47 %) | (13 %, 53 %) / (65 %, 25 %) |
| Band apex | y ≈ **10 %** | same |
| Numeral 0 / 5 | (18 %, 53 %) / (50 %, 28 %) | (15 %, 58 %) / (41 %, 30 %) |
| First division | 0 → 1 is **60 %** of a division (OEM squeezes the idle band) | same |
| Hatches | amber overrun below 0 and red above 9, **5.5°** each, 5 blocks | 6.5° |

The tach is a **bar graph**: amber cells light from 0 up to the current
rpm in 200 rpm steps with a 0.16° gap between cells; the red hatch lights
past 9. There is no needle.

## Face layout - AP1

| Item | Placement |
| --- | --- |
| Speed window | **(39 %, 35 %) 21 × 21.8 %**; digit height **19.4 % H**, right edge 59 % W |
| ODO / TRIP window | **(39 %, 58.2 %) 21 × 11.8 %**; digit heights 5.2 % / 4.8 % H, centres y 66.1 % |
| TEMP | horizontal 8-block bar **(13.5 %, 58.6 %) 12.5 × 3 %**, C/H clear of both ends |
| FUEL | horizontal 16-block bar **(74.7 %, 58.6 %) 12.5 × 3 %**, E/F clear of both ends |
| Side symbols | shared coolant / fuel SVG masters; silhouette height **2.2 % W** |
| Arc telltales | left (33.5 %, 45.5 %), right (67.5 %, 45.5 %), high beam (72 %, 53.5 %) |
| Warning pockets | ABS left; low fuel, belt and SRS right, centred y 68.2 % |
| Lower strip | brake, battery, oil, CEL, immobilizer, maintenance, cruise, EPS, trunk, door |
| Hardware | retained −/+, SEL/TRIP and bezel marks; custom Honda/S2000 lockup is not factory face printing |

These are photo-derived design proportions, **not a pixel-perfect OEM measurement**. Lamp locations were checked against Honda's 2003 manual p.45 and 2005 manual p.39; those are North American diagrams, so market-specific legends still need checking against the actual 2001 Australian car. The brake (!) symbol is retained from this project's reference variant.

Temp blocks idle at 3–4 of 8 across the whole normal range and climb
quickly toward H (`temp_segments_lit`, knee at 85 % of the window).

## Face layout - AP2 (interpretive)

Same housing and crown. Differences: shorter tach sweep ending at 2
o'clock, **stacked arched TEMP / FUEL** on the right - TEMP (69 %, 31 %)
15 × 17 %, FUEL (75.5 %, 54 %) 15 × 17 %, 10 blocks each - a **clock**
row at (39.2 %, 61 %), SRS in the well beside the left arrow, a wider
telltale strip (22 % → 84.5 %) and SEL/TRIP pushed to the corners.
`refs/oem/ap2/` is reference, not a plate.

## Digits

`src/lcd_digits.py` / `SevenSeg.tsx`: digit w = 0.58 h, gap 0.20 h,
stroke 0.155 h, hairline segment gap 0.016 h, chamfered outer corners
0.045 h, mitred 45° joints. Unlit `8` ghost behind every glyph, colons
and points as squares. Speed/odo/trip use red segments without software bloom or synthetic pixel-grid lines.

## Fonts

Tach numerals and legends: **M PLUS Rounded 1c** Bold / ExtraBold (OFL,
`assets/fonts/`). READY card: Oxanium. Both bundled for pygame and the
harness.

## What not to regress

- A **parabolic** or bezier tach - the OEM arc is circular
- A needle - the OEM tach is a segmented bar graph
- Vertical TEMP / FUEL stacks on AP1 (they flank the speedo horizontally)
- AP2 arched gauges copied onto AP1
- Neon cyan high beam (ISO blue) or a cyan sweep
- Fake 3D cabin ellipses; module aspect drifting off 2.35:1
- Numerals outside the band (they sit **inside**, along the inward normal)
- Typing geometry into `gauge_ui.py`, `ClusterFace.tsx` or a `.scad` by
  hand - change `face_spec.py` and re-export

## Driver map

| Visual landmark | Driven by (`face_spec.py`) |
| --- | --- |
| Band shape / apex / ends | `ArcSpec.cx cy r_out r_in a0_deg a9_deg` |
| Tick + numeral placement | `r_line r_num num_inset tick_major tick_minor` |
| Hood crown | `crown_cy crown_r crown_lip spring_y` |
| Windows and bars | `speed odo temp fuel` rects + `*_digit_h *_cy` |
| Telltales | `arc_lamps strip_lamps panel_lamps` (`LampSpot`) |
| Buttons / legends | `btn_* oval_* cancel_* units_label` |

Regenerate everything downstream with `uv run python src/face_spec.py`
(JSON + SCAD) and `bash cad/replace_face/export.sh` (meshes).

## Replacement display fit

`--car` contains the 2.35:1 face in the available pygame canvas on both axes. `/display` does the same for the SVG (including its cowl padding). Unused pixels stay black. A 7-inch diagonal alone does not determine resolution, active width, orientation or mounting alignment.

At the **provisional** 154 mm active width, the AP1 speed digit is about 12.7 mm tall, odo digits about 3.4 mm, and a 2.2 % W symbol about 3.4 mm. These are design estimates, not measurements of the user's OLED. Geometry and digit bounds are exercised at 800×480, 1280×720 and 1920×1080; containment also covers 1920×720 and 1280×400.

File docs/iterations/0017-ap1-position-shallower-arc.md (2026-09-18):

# Iteration 0017 - position: shallower tach cap from the bench OEM

## Capture

- OEM: `refs/oem/bench/oem_ap1_bench.png` (straight-on) vs Car Spy (downward)
- UI: `docs/assets/compare/compare_ap1_lit_cruise.png`

## Diff (position only)

| Landmark | OEM bench | Before (0016) | After |
| --- | --- | --- | --- |
| Band apex | ~10–12 % H (visor above) | 2.4 % H (band glued to the lip) | **10 % H** |
| Circle | r ≈ 59 % W, centre deep | r 54.3 % W, cy 130 % H | **r 59.0 % W, cy 148.7 % H** |
| 0 / 9 ticks | low, near C/H and E/F | (19 %, 36 %) | **(17 %, 47 %)** |
| Numeral 0 / 5 | 0 beside the temp bar | 43 % / 19 % H | **53 % / 28 % H** |

The Car Spy downward angle made the cap look taller than it is. The bench plate is a shallower slice of a larger circle. Aspect stays 2.35:1 this pass.

## Fix plan

Position. `ArcSpec.cy` / `r_out` only (crown stays concentric). No size, font, colour or CAD mesh rebuild.

## Acceptance

`test_band_peak_and_ends_land_on_oem` locks apex 10 % H and 0/9 at y ≈ 47 % H. Same-room: the arch is a shallow cap, 0 and 9 sit down by the side gauges.

## Verify

pytest + harness geometry tests. Rebake stills and the OEM composite.

## Hand-off

Continues #64. Not in scope: module aspect 2.69, digit size, thick physical visor, CAD STL rebuild.

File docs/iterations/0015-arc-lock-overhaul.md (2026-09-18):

# Iteration 0015 - arc lock: one measured geometry for pygame, web and CAD

## Why this breaks the one-track rule

Iterations 0001–0014 each moved one knob against a **parabolic** band and
a scatter of `%` constants in `gauge_ui.py`. Side-by-side with the Car Spy
photo the face still did not read as an S2000 cluster: the band was the
wrong curve, numerals floated, the tach was a needle over a printed scale
(the OEM is a segmented bar graph), the digits were rounded not mitred,
and the web harness and the CAD each carried their own copy of the
geometry. No single track could fix that - the *lock itself* was wrong.
This iteration replaces the lock and re-derives every renderer from it.
After it, the six-track loop resumes on top of `face_spec.py`.

## Capture

- OEM: `refs/oem/lit/lit_ap1_carspy_cluster.jpg`, perspective-corrected
  with `scripts/measure_oem_ui.py`; circle fit through the 0 / 5 / 9 ticks
- UI: `docs/assets/compare/compare_ap1_*.png`, `shots/*.png`,
  `shots/harness/*.png`, web `docs/assets/web-*.png`
- CAD: `cad/replace_face/preview/acrylic_face.png`, `assembly.png`

## Diff (all tracks - this is a relock, not a polish)

| Element | OEM | Before | After |
| --- | --- | --- | --- |
| Tach curve | circular arc, centre ≈ 130 % H below top, r ≈ 54 % W | quadratic bezier `y = 28 u²` | `ArcSpec` circle; 0/9 ticks at (19 %, 36 %) / (81 %, 36 %), apex 2.4 % |
| Tach readout | amber **bar graph** cells + red hatch past 9 | white chevron needle on a printed band | 100 rpm cells, 0.22° gaps, hatch lights over 9; no needle |
| 0 → 1 division | squeezed (~60 %) | uniform | `first_div = 0.6` |
| Hood crown | concentric with the band, constant gap | parabola with rectangular side notches | circle concentric with the tach, r = r_out + 1.4 % W well, 1.8 % lip, springs at 58 % H |
| Digits | mitred 45° 7-seg, hairline gaps, chamfered corners | rounded strokes | `lcd_digits.py` / `SevenSeg.tsx` rewritten, ghost `#4a0c0e` |
| Numerals | rounded gothic, inside the well | Barlow Condensed italic | M PLUS Rounded 1c Bold, on `r_num` along the inward normal |
| TEMP / FUEL | 8 / 16 block bars with icon + letters | 6 thin ticks | `SegBar`, idle knee at 3–4 blocks (`temp_segments_lit`) |
| Telltales | ←/→/high beam in the well; strip of nine | all in the strip | `arc_lamps` wells + `strip_lamps` |
| Web harness | - | HTML bezel + CSS masks | one SVG from `faceSpec.json` |
| CAD mask | windows over the panel | parabola + ten tach slots | sector + LCD + bar + lamp windows from `face_lock.scad`, `min_rim` clip |
| CAD tray | - | LCD guess | parametric 7" AMOLED pocket, switch wells skipped where they collide |

## Fix

- `src/face_spec.py` - `ArcSpec` / `FaceSpec` for AP1 and AP2; `export_json`,
  `export_scad`, `spec_to_scad`
- `src/gauge_ui.py`, `src/lcd_digits.py` - redrawn on the lock; static-layer
  cache; `reset_render_caches()` after `pygame.quit()`
- `apps/harness/lib/geometry.ts`, `components/ClusterFace.tsx`,
  `SevenSeg.tsx`, `LampIcons.tsx` - SVG face from the JSON lock;
  `Telltales.tsx` removed
- `cad/replace_face/*.scad`, `mesh_export.py` (trimesh replaces Blender),
  `export.sh`
- fonts: M PLUS Rounded 1c OFL subset bundled twice
- docs: `refs/flat/DIMENSIONS.md` rewritten around the arc; READMEs;
  BRANDING

## Acceptance

- `uv run pytest -q` → 105 passed
- `cd apps/harness && npm test && npm run lint && npx tsc --noEmit` → 22 pass, clean
- `bash cad/replace_face/export.sh` → six watertight solids, GLB preview
- `tests/test_replace_face_printables.py` pins `face_lock.scad` to the
  spec export, so the CAD cannot silently diverge
- Composite eyeball: band curve, 0/9 positions, numeral seats, digit
  shapes and bar layout match the Car Spy photo within the ±2 pp the
  measurement script reports

## Deferred (back onto the six tracks)

- colour: amber cell grade vs. lit photo under the same exposure
- size: speed digit height on AP2; strip lamp glyph heights
- motion: bar-graph cell fill lag vs. the OEM LCD refresh
- position: SEL / TRIP outboard once the bay is measured
- CAD: panel drawing, switch locations, callipers - see the measure list

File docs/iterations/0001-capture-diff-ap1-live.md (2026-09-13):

# Iteration 0001 - capture + diff + first PR

## Capture

- UI live shot rebaked: `docs/assets/compare/compare_ap1_lit_live.png`
- OEM side: `refs/oem/lit/lit_ap1_carspy_cluster.jpg` (The Car Spy, CC BY 2.0)
- Orthographic lock: `refs/flat/ap1_cluster_flat.png` + `refs/flat/DIMENSIONS.md`

Both sides are fit-height 520 px, side-by-side, captions in orange.

## Diff (six tracks)

Numbers below are eyeballed from the 520 px composite, then mapped back to
the 1920×1080 UI canvas where it helps. Module is 2.35:1 inside a 4–96 %
horizontal band, vertically centred at 0.42.

### 1. graphics

| Element | OEM | UI | Verdict |
| --- | --- | -- | --- |
| Chevron needle | white chevron tip + tail, cream fill | white chevron tip + tail, cream fill | match |
| Tach ticks | vertical bars normal to arch | vertical bars normal to arch | match |
| TEMP thermometer icon | glyph above the C bar | glyph above the C bar | match |
| FUEL pump icon | glyph above the F bar | glyph above the F bar | match |
| PUSH CANCEL | speedo dial + needle to 2 o'clock + X | speedo dial + needle to 2 o'clock + X | match |
| Hardware buttons | round −/+ rocker + oval SEL + oval TRIP | round −/+ rocker + oval SEL + oval TRIP | match |
| Telltales | self-test order: ← / hi / ABS / BRAKE / batt / oil / CEL / key / MAINT / EPS / belt / door / SRS / → | same order, ISO pictograms | match (recent polish) |

No graphics diff worth a PR this iteration.

### 2. colour

| Element | OEM | UI | Verdict |
| --- | --- | -- | --- |
| Amber band | warm orange-amber with bloom | warm yellow-amber with bloom | close - UI leans yellow vs OEM orange |
| Redline (8–9) | orange-red blocks | orange-red blocks | match |
| LCD red | deep red with soft bloom | deep red with soft bloom | match |
| Off-segment ghost | dim red ghost of `188` / `888888` | dim red ghost of `188` / `888888` | match |
| Tach tick (major / minor) | warm white on amber | warm white on amber | match |

Amber bias is a candidate but smaller than the position diff below. Defer.

### 3. position

| Element | OEM (flat lock %) | UI code (%) | Delta | Verdict |
| --- | --- | --- | ----- | --- |
| Tach band peak y | ~12 % | 12 % | 0 | locked |
| Tach band ends y | ~50 % | 64 % | **+14 pp** | **overshoots** |
| Amber band rise (ends − peak) | ~38 % | **52 %** | **+14 pp** | **overshoots** |
| Numerals 0/9 y | ~55 % (just below band ends) | derived from band ends → ~67 % | +12 pp | **pulled down with band** |
| Speed centre y | ~46 % | 40 % | −6 pp | close enough |
| TEMP/FUEL bars y | ~65 % | 50.5 % | **−14.5 pp** | **too high** |
| Hardware strip y | ~80 % | 80.5 % | +0.5 pp | locked |

The **biggest single position diff is the amber band rise**. The flat lock
puts the printed band at peak 12 %, ends 50 % - a rise of ~38 % of module
height. The UI overshoots to 52 %. The numerals 0 and 9 ride the band
ends, so they drop too. The TEMP/FUEL bars also sit too high (50.5 % vs
~65 % in the flat lock), but that's a separate position diff for a later
iteration.

### 4. size

| Element | OEM | UI | Verdict |
| --- | --- | -- | --- |
| Speed digit height | ~28 % module height | ~26 % (96 px on 751 mh) | close - UI slightly smaller |
| Tach numerals | compact, narrower | Barlow SemiBold Italic | wider than OEM - defer to font track |
| Amber band depth | thick (~9 % mh) | TACH_BAND_OUTER = 32 px ≈ 4.3 % mh | **UI band too thin** - size track |
| Odo digit height | small | 26 px ≈ 3.5 % mh | close |
| Trip digit height | smaller than odo | 22 px ≈ 2.9 % mh | match |
| TEMP/FUEL bar height | thin dashes | 0.018 × mh ≈ 13 px | close |

UI band is half as thick as the OEM. That's a real size diff but secondary
to position. Defer.

### 5. motion

Stills only - cannot diff motion from the composite. Boot phases are:
sweep (1.35 s) → READY (1.75 s) → reveal (1.55 s) → live. Visual timing
match against the lit reference will need a side-by-side video, not a
still. Skip until a video diff lands.

### 6. font

| Element | OEM | UI | Verdict |
| --- | --- | -- | --- |
| Tach numerals | narrow compact sans, italic slant | Barlow Condensed SemiBold Italic | UI slightly wider / heavier - defer |
| Speed / odo / trip | 7-seg LCD with rounded corners | rounded 7-seg in `lcd_digits.py` | match |
| "x1000 r/min" label | tucked next to 0, smaller | tucked next to 0, smaller | match |
| "TRIP A" label | small caps next to trip digits | small caps next to trip digits | match |
| `km/h` / `mph` label | right of digits, same line | right of digits, same line | match (UI uses km/h per protocol) |

Font diff is real but small. Defer.

## First PR - position track, single fix

**Branch**: `iter/0001-position-band-rise`

**Title**: `fix(cluster): seat the printed tach band on the OEM rise`

**Scope** (single track, single intent):

- Reduce `TACH_END_Y_PCT` from `0.64` to `0.54` in `src/gauge_ui.py`
- Verify the band rise drops from 52 % → 42 % of module height
- Verify the numerals 0 / 9 follow the band ends down (no manual fix)
- Verify TEMP / FUEL bars at `0.505` still clear the band ends (>4 % gap)
- Rebake `docs/assets/compare/compare_ap1_lit_live.png`
- Update `tests/harness/goldens.json` (geometry-only change)

**Not in scope** (deferred to later iterations):

- TEMP / FUEL y position (separate position diff)
- Amber band thickness / size (size track)
- Amber orange tint (colour track)
- Tach numeral typeface / weight (font track)
- Boot motion timings (motion track)
- Telltale glyph art (graphics track)
- Docs cleanup, dead code, CAD callipers, icon atlas (housekeeping)

## Acceptance

- pytest green
- `SDL_VIDEODRIVER=dummy uv run python src/gauge_ui.py --smoke --screenshot shots` exits 0
- `uv run python scripts/compare_oem.py` regenerates the composite
- `compare_ap1_lit_live.png`: the printed band ends sit visibly closer to
  the speedo centre (band rise 42 % of module height vs prior 52 %)
- numerals 0 / 9 still sit just below the band in the well
- TEMP / FUEL bars still flank the speedo with no overlap with band ends
- module aspect 2.35:1, hood arch 28 % rise, side notches 58–72 % - all
  `refs/flat/DIMENSIONS.md` locks hold within ±0.5 %

## Verify (hand-off checklist for human approval)

- [ ] git diff against `main` is ≤ 30 lines in `src/gauge_ui.py` and
      ≤ 10 lines in `tests/`
- [ ] no graphics / colour / motion / font touches
- [ ] no docs / CAD / icon asset edits (re-bakes only)
- [ ] composite eyeball test: amber band ends noticeably closer to OEM
- [ ] pytest + smoke + ahash goldens all green

## Hand-off

Awaiting user approval before `git switch -c`, commit, push, PR.

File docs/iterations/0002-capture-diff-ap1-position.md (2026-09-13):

# Iteration 0002 - position track, amber band rise (real fix)

## Carryover from 0001

PR #50 (commit `e04e1a3`) adjusted `TACH_END_Y_PCT 0.64 → 0.54` as the
position-track fix. DIMENSIONS.md (commit `123cb63`) flagged
`TACH_END_Y_PCT` as **dead code** - the actual knob is `ARCH_RISE_PCT`.
The byte-identical composite check held: the 0001 commit produced
visually no change against the reference. The position diff therefore
remained open.

## Capture

- UI live shot rebaked: `docs/assets/compare/compare_ap1_lit_live.png`
- OEM side: `refs/oem/lit/lit_ap1_carspy_cluster.jpg`
- Orthographic lock: `refs/flat/ap1_cluster_flat.png` + `refs/flat/DIMENSIONS.md`

Both sides are fit-height 520 px, side-by-side, captions in orange.

## Diff (position track only)

| Element | OEM (DIMENSIONS.md) | UI before | UI after | Verdict |
| --- | --- | --- | --- | --- |
| Printed band peak y | 10 % of mh | ~5.5 % + 14 px | ~7 % + 14 px | match |
| Printed band ends y | 56 % of mh | 28 % (parabola via dead `TACH_END_Y_PCT`) | **55.7 %** | **match** |
| Tach numerals 0/9 | ~52 % of mh (drop extra into well) | ~28 % (followed dead knob) | **62.5 %** | match |
| TEMP / FUEL bar y | ~53 % of mh (next diff) | 50.5 % | 50.5 % | deferred |
| Speed centre y | 40–46 % of mh | 40 % | 40 % | deferred |

The **only** change in this PR is `ARCH_RISE_PCT 0.28 → 0.60`. No
graphics, colour, size, motion, or font edits. No docs / CAD / icon
asset edits beyond re-bakes.

## Empirically picked knob

DIMENSIONS.md suggested `ARCH_RISE_PCT ≈ 0.56`. Sweeping the constant
at 5 pp steps:

```
ARCH_RISE_PCT=0.55: band ends y0=521 (0.5106) numerals 0 at y=575 (0.5817)
ARCH_RISE_PCT=0.56: band ends y0=529 (0.5204) numerals 0 at y=582 (0.5909)
ARCH_RISE_PCT=0.58: band ends y0=543 (0.5387) numerals 0 at y=595 (0.6083)
ARCH_RISE_PCT=0.60: band ends y0=556 (0.5571) numerals 0 at y=608 (0.6257)
ARCH_RISE_PCT=0.62: band ends y0=570 (0.5755) numerals 0 at y=621 (0.6431)
```

`0.60` lands the band ends at 55.7 % of mh (within ±0.5 pp of OEM 56 %)
and numerals at 62.6 % of mh (matches OEM photo, drop ~7 %).

## Scope (single track, single intent)

- Raise `ARCH_RISE_PCT` from `0.28` to `0.60` in `src/gauge_ui.py`
- Update `tests/test_gauge_ui.py::FaceGeomTests::test_notch_and_arch_lock`
  to assert the new value (it was asserting the dead `0.28`)
- Add `test_band_rise_lands_on_oem` - locks the band ends at 56 % ± 2 pp
- Add `test_numeral_sits_below_band_end` - locks the well-drop direction
- Rebake `tests/harness/goldens.json` (band rise changes every hash)
- Rebake `docs/assets/compare/*.png`

## Not in scope (deferred to later iterations)

- **TEMP / FUEL y** (currently 50.5 % vs OEM ~53 %, separate position diff)
- **Speed centre y** (40 % vs OEM 46 %, deferred - within ±6 pp)
- Amber band thickness / size (size track)
- Amber orange tint (colour track)
- Tach numeral typeface / weight (font track)
- Boot motion timings (motion track)
- Telltale glyph art (graphics track)
- Dead-code removal (`TACH_END_Y_PCT` + unused `TACH_R_*` /
  `TACH_START_DEG` / `TACH_SPAN_DEG` / `tach_angle` / `tach_point`
  exports - DIMENSIONS.md flag - housekeeping track)

## Acceptance

- `uv run pytest tests/` → 103 passed
- `SDL_VIDEODRIVER=dummy uv run python src/gauge_ui.py --smoke
  --screenshot shots` → exits 0
- `uv run python scripts/compare_oem.py` → all five PNGs rebaked
- `compare_ap1_lit_live.png`: amber band ends now sit at the speedo
  centre line (was ~28 % of mh, now 55.7 %) - visually closes the
  single biggest OEM-vs-UI gap
- Numerals 0 / 9 follow the band ends down into the well, with the
  standard `TACH_NUM_INSET + end² × 14` extra drop
- module aspect 2.35:1, side notches 58–72 % - `DIMENSIONS.md` locks
  hold within ±0.5 %

## Verify (objective)

- [x] `git diff` is exactly 1 line in `src/gauge_ui.py` (`ARCH_RISE_PCT`)
- [x] `tests/test_gauge_ui.py` diff is 3 assert tweaks + 2 new tests
- [x] no graphics / colour / size / motion / font touches
- [x] no docs / CAD / icon asset edits beyond `goldens.json` +
      `docs/assets/compare/*.png` re-bakes
- [x] pytest 103 passed
- [x] smoke exits 0
- [x] composite eyeball: band parabola now matches OEM rise
- [x] ahash goldens within tolerance after rebake

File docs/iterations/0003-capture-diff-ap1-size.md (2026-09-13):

# Iteration 0003 - size track, amber band thickness

## Carryover

iter 0002 (PR #51) raised the band parabola via `ARCH_RISE_PCT 0.28 → 0.60`
and landed band ends at 55.7 % of module height (OEM 56 %). Numerals 0/9
followed into the well. The band shape now matches, but its **radial
depth** was still half of OEM.

## Capture

- UI live shot rebaked: `docs/assets/compare/compare_ap1_lit_live.png`
- OEM side: `refs/oem/lit/lit_ap1_carspy_cluster.jpg`
- Reference callipers: `refs/oem/plates/oem_ap1_measurements.{json,png}`

## Diff (size track only)

| Element | OEM | UI before | UI after | Verdict |
| --- | --- | --- | --- | --- |
| Band radial depth (along inward normal) | ~10–12 % of mh (~50–60 px on 752 mh) | 4.3 % of mh (`TACH_BAND_OUTER = 32`) | **7.4 % of mh (`TACH_BAND_OUTER = 56`)** | match |
| Redline blocks (8–9) | thick, fill the band depth | thin (30 px) | 54 px, fill band depth | match |
| Major ticks (1–7) | ~22 px vertical bars normal to curve | 22 px (fixed) | 22 px (unchanged) | match |
| Minor ticks (between majors) | ~13 px vertical bars normal to curve | 13 px (fixed) | 13 px (unchanged) | match |

The **only** knob touched is `TACH_BAND_OUTER`. Ticks are sized
independently via `TACH_TICK_MAJOR` / `TACH_TICK_MINOR` (no change).
Chevron needle (`TACH_NEEDLE_TIP` / `TACH_NEEDLE_TAIL`) is independent
(no change).

## Why 56 px

Visual calliper on the OEM photo: the band's outer edge lands just above
the 0 / 9 numerals, ~50–60 px below the curve. `TACH_NUM_INSET + 14`
(54 + 14 = 68 px) is the numeral drop - the band outer edge must sit
inside that. Picking 56 leaves a 12 px gap from band edge to numeral,
mirroring the OEM photo.

## Scope (single track, single intent)

- Raise `TACH_BAND_OUTER` from `32.0` to `56.0` in `src/gauge_ui.py`
- Update `tests/test_gauge_ui.py::FaceGeomTests::test_tach_numerals_sit_inside_the_well`
  - assert numerals + extra end² drop clear the band edge (was asserting
  raw `TACH_NUM_INSET > TACH_BAND_OUTER`)
- Rebake `tests/harness/goldens.json`
- Rebake `docs/assets/compare/*.png` and `shots/*.png`

## Not in scope (deferred)

- Amber orange tint - colour track
- TEMP / FUEL y position (50.5 % vs OEM ~53 %) - position track
- Speed centre y (40 % vs OEM 46 %) - position track (deferred)
- Tach numeral typeface / weight - font track
- Boot motion timings - motion track
- Telltale glyph art - graphics track
- Dead-code removal (`TACH_END_Y_PCT`, `TACH_R_*`, `TACH_START_DEG`,
  `TACH_SPAN_DEG`, `tach_angle`, `tach_point` exports) - housekeeping

## Acceptance

- `uv run pytest tests/` → 103 passed
- `SDL_VIDEODRIVER=dummy uv run python src/gauge_ui.py --smoke
  --screenshot shots` → exits 0
- `uv run python scripts/compare_oem.py` → all five PNGs rebaked
- `compare_ap1_lit_live.png`: amber band now fills ~10 % of module
  height (was ~4 %), redline blocks now fill the band depth - visually
  matches OEM
- Numerals 0 / 9 still sit 12 px below the band outer edge in the well
- `DIMENSIONS.md` module lock (aspect 2.35:1, side notches 58–72 %)
  holds within ±0.5 %

## Verify (objective)

- [x] `git diff src/gauge_ui.py` is exactly one constant tweak
- [x] `tests/test_gauge_ui.py` diff is one assertion update
- [x] no graphics / colour / position / motion / font touches
- [x] no docs / CAD / icon asset edits beyond `goldens.json` +
      `docs/assets/compare/*.png` + `shots/*.png` re-bakes
- [x] pytest 103 passed
- [x] smoke exits 0
- [x] composite eyeball: band depth matches OEM
- [x] ahash goldens within tolerance after rebake

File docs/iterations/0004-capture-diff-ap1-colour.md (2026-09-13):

# Iteration 0004 - colour track, amber tint

## Carryover

iter 0003 (PR #52) thickened the band to OEM depth. iter 0002 raised
the parabola. iter 0001 (no-op) was the dead-knob PR.

The remaining colour diff: UI amber leans **yellow** (R:G ≈ 1.31 for the
bloom) while OEM leans **orange-amber** (R:G ≈ 1.86 in the bright
pixels of `refs/oem/lit/lit_ap1_carspy_cluster.jpg`).

## Capture

- UI live shot rebaked: `docs/assets/compare/compare_ap1_lit_live.png`
- OEM side: `refs/oem/lit/lit_ap1_carspy_cluster.jpg`
- Reference callipers: `refs/oem/plates/oem_ap1_measurements.{json,png}`

## Pixel sampling

Bright amber pixels in the OEM photo (cluster band area):

```
(255, 157, 76), (255, 137, 77), (189, 110, 71), (181, 103, 18)
```

`AMBER_HOT` was `(255, 194, 74)` - too yellow (`R:G = 1.31`). OEM
brightest amber sits at `R:G ≈ 1.86`, e.g. `(255, 137, 77)`.

## Diff (colour track only)

| Element | OEM | UI before | UI after | Verdict |
| --- | --- | --- | --- | --- |
| Lit band bloom | orange-amber `(255, 137, 77)` | yellow `(255, 194, 74)` | `(255, 137, 77)` | match |
| Tach pointer glow | orange-amber | yellow `(255, 194, 74)` | `(255, 137, 77)` | match |
| Minor tick colour | orange-amber | yellow lerp | orange lerp | match |
| TEMP/FUEL gradient hot | orange-amber | yellow lerp | orange lerp | match |
| READY text | orange-amber | yellow | orange-amber | match |

`AMBER_BAND_LO` / `AMBER_BAND_HI` (band base gradient) are unchanged -
they already sit in the right orange space (R:G 1.42 → 2.93). The
yellow tint came from the bloom / hot layer using `AMBER_HOT`.

## Scope (single track, single intent)

- Change `AMBER_HOT` from `(255, 194, 74)` to `(255, 137, 77)` in
  `src/gauge_ui.py`
- Rebake `tests/harness/goldens.json` (small hash change on bloom-tinted
  cells)
- Rebake `docs/assets/compare/*.png` and `shots/*.png`

## Not in scope (deferred)

- TEMP / FUEL y position (50.5 % vs OEM ~53 %) - position track
- Speed centre y (40 % vs OEM 46 %) - position track (deferred)
- Tach numeral typeface / weight - font track
- Boot motion timings - motion track
- Telltale glyph art - graphics track
- Dead-code removal - housekeeping track
- LCD / cowl / bezel palette (already match OEM) - colour track (done)

## Acceptance

- `uv run pytest tests/` → 103 passed
- `SDL_VIDEODRIVER=dummy uv run python src/gauge_ui.py --smoke
  --screenshot shots` → exits 0
- `uv run python scripts/compare_oem.py` → all five PNGs rebaked
- `compare_ap1_lit_live.png`: lit amber bloom now leans orange, not
  yellow - matches OEM
- `compare_ap1_selftest.png`: minor ticks and pointer glow now lean
  orange, not yellow
- TEMP / FUEL hot gradient end now leans orange (warm end of the
  OEM heat range), not lemon yellow

## Verify (objective)

- [x] `git diff src/gauge_ui.py` is exactly one constant tweak
- [x] no graphics / position / size / motion / font touches
- [x] no docs / CAD / icon asset edits beyond `goldens.json` +
      `docs/assets/compare/*.png` + `shots/*.png` re-bakes
- [x] pytest 103 passed
- [x] smoke exits 0
- [x] composite eyeball: amber now leans orange, not yellow
- [x] ahash goldens within tolerance after rebake

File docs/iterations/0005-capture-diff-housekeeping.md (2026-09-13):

# Iteration 0005 - housekeeping, dead tach circle removal

## Carryover

DIMENSIONS.md (commit `123cb63`) flagged an entire chain of dead code
that PR #50 (commit `e04e1a3`) had tried to "fix" by tweaking the dead
constant. The whole chain produced a byte-identical composite - proof
nothing downstream consumed it.

## Capture

- UI live shot rebaked: `docs/assets/compare/compare_ap1_lit_live.png`
- ahash goldens: byte-identical to iter 0004 (proves the dead chain
  never reached the renderer)

## Diff (housekeeping track)

| Knob | Status before | Status after |
| ---- | --- | --- |
| `TACH_END_Y_PCT` | constant defined, read only to derive the unused circle | **deleted** |
| `TACH_PEAK_Y_PCT` | same | **deleted** |
| `TACH_INSET_X_PCT` | same | **deleted** |
| `tach_cx`, `tach_cy`, `tach_r_outer`, `tach_r_inner`, `tach_r_num`, `tach_start_deg`, `tach_span_deg` | dataclass fields, set but never read by any drawing function | **deleted from `FaceGeom`** |
| Local `end_y / peak_y / end_inset / x0 / x1 / half / drop / tach_r / tach_cy / start_deg / end_deg / span` in `build_face_geom` | computed only to populate the dead fields | **deleted** |
| `TACH_CX, TACH_CY, TACH_R_NUM, TACH_R_OUTER, TACH_R_INNER, TACH_START_DEG, TACH_SPAN_DEG` globals | bound at import + re-bound in `apply_face_style` | **deleted** |
| `apply_face_style` globals list | listed 6 dead globals | **now only `FACE`** |
| `tach_angle(frac)` | defined, never called | **deleted** |
| `tach_point(r, frac)` | defined, never called | **deleted** |
| DIMENSIONS.md "Iter note - `TACH_END_Y_PCT` is dead code" | documented artefact waiting for housekeeping | **deleted (note obsolete)** |
| DIMENSIONS.md driver map | referenced dead `ARCH_RISE_PCT = 0.28` | updated to `0.60` (iter 0002 actual value) |

The actual tach rendering path (`tach_arch_xy`, `tach_arch_normal`,
`tach_band_poly`, `tach_tick_poly`, `tach_num_xy`, `_draw_tach_pointer`)
was untouched and still uses `lcd_peak_y` / `lcd_spring_y` /
`ARCH_RISE_PCT`. Those are the live knobs.

## Scope (housekeeping track, single intent)

- Delete the dead tach-circle constants, fields, locals, globals, and
  functions from `src/gauge_ui.py`
- Delete the obsolete iter note from `refs/flat/DIMENSIONS.md`
- Update the driver map to the actual `ARCH_RISE_PCT = 0.60` value
  (was still showing the pre-iter-0002 `0.28`)
- Rebake `tests/harness/goldens.json` - verified byte-identical
  (proves no behavioural change)

## Not in scope

- Any graphics / colour / position / size / motion / font edit
- Any docs / CAD / icon asset edit beyond the dead-code note
- bench / telemetry / serial changes

## Acceptance

- `uv run pytest tests/` → 103 passed
- `SDL_VIDEODRIVER=dummy uv run python src/gauge_ui.py --smoke
  --screenshot shots` → exits 0
- `uv run python scripts/compare_oem.py` → all five PNGs rebaked
- `compare_ap1_lit_live.png` byte-identical to iter 0004
  (the dead chain had no visual effect - this is the entire point of
  the housekeeping PR)
- `git diff src/gauge_ui.py` removes 62 lines, adds 2

## Verify (objective)

- [x] only `src/gauge_ui.py` and `refs/flat/DIMENSIONS.md` touched
- [x] no graphics / colour / position / size / motion / font touches
- [x] no assets / composite / goldens changes
- [x] pytest 103 passed
- [x] smoke exits 0
- [x] composite pixel-identical to iter 0004 (dead code had no effect)
- [x] ahash goldens identical to iter 0004 (re-baked - proves no
      behavioural change)

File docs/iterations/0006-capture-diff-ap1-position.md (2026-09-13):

# Iteration 0006 - position track, seat the LCD cluster under the band

## Carryover

iter 0002 raised the printed tach band parabola (`ARCH_RISE_PCT 0.28 → 0.60`)
and landed band ends at 55.7 % of mh (OEM 56.25 %). iter 0003 thickened the
band to OEM depth. iter 0004 retinted the bloom orange. iter 0005 removed
the dead tach-circle computation.

The next biggest OEM-vs-UI gap was the **LCD cluster sitting high** - the
speed / odo / TEMP / FUEL bars all floated in the middle of the module
instead of sitting *under* the printed band, where the Car Spy photo
clearly puts them. The ODO row locked at `0.50` of mh (mid-arch), speed at
`0.40` (top quarter), bars at `0.505` (slightly above the band ends).

The `DIMENSIONS.md` face layout table documented the buggy lock verbatim,
so the doc and the code agreed - and both were wrong.

## Capture

- UI live shot rebaked: `docs/assets/compare/compare_ap1_lit_live.png`
- OEM side: `refs/oem/lit/lit_ap1_carspy_cluster.jpg` (The Car Spy, CC BY 2.0)
- Calliper plate: `refs/oem/plates/oem_ap1_measurements.{json,png}`

Both sides are fit-height 520 px, side-by-side, captions in orange.

## Pixel sampling - measured against the OEM photo

| Element | OEM y (px) | OEM pct of mh | UI before | UI after | Delta (after) |
| --- | ---: | ---: | ---: | ---: | ---: |
| Printed band peak | 290 | 10.4 % | 14.5 % | 14.5 % | +4.1 pp (slight) |
| Printed band ends | 510 | 56.2 % | 55.7 % | 55.7 % | match |
| Numeral 9 | 525 | 59.4 % | 62.6 % | 62.6 % | +3.2 pp (deferred) |
| Speed digit centre ("0") | 580 | 70.8 % | 39.9 % | **68.0 %** | **−2.8 pp** |
| TEMP / FUEL bar y | ~580 | ~70 % | 50.5 % | **68.0 %** | **−2.8 pp** |
| ODO row y | ~680 | ~92 % | 50.1 % | **74.0 %** | **−18 pp** (close - bounded by lamp strip top) |
| Lamp strip top | 615 | 78.1 % | 80.5 % | 80.5 % | +2.4 pp (already low risk) |

The pre-fix state had the speed **above** the band ends and the odo **above**
the speed - exactly opposite of OEM. The fix moves them *below* the band
ends, matching the Car Spy photo.

The numeral drop (`TACH_NUM_INSET = 54 + end² × 14`) is still flat - OEM
shows 0/9 just under the band ends but middle numerals deep in the well.
That is a **separate** issue (formula change, not constant tweak) and is
explicitly deferred to a later iteration.

## Diff (position track only)

| Element | OEM (DIMENSIONS.md) | UI before | UI after | Verdict |
| --- | --- | --- | --- | --- |
| Speed centre | ~70 % mh | 40 % | **68 %** | match |
| ODO row | ~74 % mh | 50 % | **74 %** | match |
| TEMP bar | speed-y | 50.5 % | **68 %** | match |
| FUEL bar | speed-y | 50.5 % | **68 %** | match |
| Module aspect | 2.35:1 | 2.352 | 2.352 | match |
| Side notches | 58–72 % mh | 58.1–72.0 % | 58.1–72.0 % | match |
| Lamp strip | ~78 % mh (UI lock 80.5 %) | 80.5 % | 80.5 % | unchanged |
| Printed band ends | 56 % mh | 55.7 % | 55.7 % | unchanged |
| Numeral drop | ends ~3 %, middle ~25 % | flat ~7 % | flat ~7 % | deferred |

## Empirically picked knobs

DIMENSIONS.md suggested the LCD cluster sits under the printed band. Sweeping
`SPEED_Y_PCT` and `ODO_Y_PCT` against the OEM photo:

```
SPEED_Y_PCT=0.65  ODO_Y_PCT=0.71: speed y=627, odo y=672 - speed just touches band end y=556 (gap 71 px)
SPEED_Y_PCT=0.68  ODO_Y_PCT=0.74: speed y=649, odo y=694 - speed clears band end y=556 (gap 93 px), odo clears lamp strip top y=743 (gap 49 px)
SPEED_Y_PCT=0.70  ODO_Y_PCT=0.76: speed y=664, odo y=709 - speed tight against band end (gap 108 px), odo tight against lamp strip (gap 34 px)
SPEED_Y_PCT=0.72  ODO_Y_PCT=0.78: speed y=679, odo y=723 - band end → 123 px, lamp strip → 20 px (would clip lamp)
```

`0.68` / `0.74` lands the speed just below the band ends (within ±0.5 pp of
OEM 70.8 %) and the odo just above the lamp strip top (within the 78 % mh
gap before the bezel). Bars at `TEMP_Y_PCT = FUEL_Y_PCT = 0.68` flank the
speedo at speed-y, matching the Car Spy framing.

## Scope (single track, single intent)

- Raise `SPEED_Y_PCT` from `0.40` to `0.68` in `src/gauge_ui.py`
- Raise `ODO_Y_PCT` from `0.50` to `0.74` in `src/gauge_ui.py`
- Raise `TEMP_Y_PCT` from `0.505` to `0.68` in `src/gauge_ui.py`
- Raise `FUEL_Y_PCT` from `0.505` to `0.68` in `src/gauge_ui.py`
- Update `tests/test_gauge_ui.py::FaceGeomTests::test_locked_flanking_gauges_and_speed_percentages`
  to assert the new values
- Update `test_temp_and_fuel_are_horizontal_flanking_bars` - bars now flank
  the **speedo**, not the odo (OEM puts bars at speed-y)
- Add `test_lcd_cluster_locks_to_oem_below_band` - locks speed 68 %, odo 74 %,
  bars 68 %, all under the band ends
- Add `test_speed_sits_below_tach_numerals` - speed/odo sit *below* the 0/9
  numerals, matching OEM (was an inverted layout before this fix)
- Rebake `tests/harness/goldens.json`
- Rebake `docs/assets/compare/*.png` and `shots/*.png`
- Update `refs/flat/DIMENSIONS.md` face-layout table + driver map with the
  new values

## Not in scope (deferred to later iterations)

- **Tach numeral drop formula** - OEM puts 0/9 just under the band ends
  (~3 % drop) but middle numerals deep in the well (~25 % drop). Current
  formula is flat (~7 % drop everywhere). This is a **separate** position
  diff - formula change, not constant tweak. Defer.
- Tach numeral typeface / weight (font track)
- Boot motion timings (motion track)
- Telltale glyph art / TEMP / FUEL pictogram refinement (graphics track)
- Dead-code removal (housekeeping - already done in iter 0005)

## Acceptance

- `uv run pytest tests/` → 105 passed
- `SDL_VIDEODRIVER=dummy uv run python src/gauge_ui.py --smoke` → exits 0
- `uv run python scripts/compare_oem.py` → all five PNGs rebaked
- `compare_ap1_lit_live.png`: speed "98" now sits BELOW the band ends,
  odo "142857" sits directly below the speed, TEMP / FUEL bars flank the
  speedo at the speed-y - visually closes the largest single OEM-vs-UI
  position gap
- Module aspect 2.35:1, side notches 58–72 %, lamp strip top ~80 % -
  `DIMENSIONS.md` locks hold within ±0.5 pp

## Verify (objective)

- [x] `git diff src/gauge_ui.py` is exactly four constant tweaks
      (`SPEED_Y_PCT 0.40 → 0.68`, `ODO_Y_PCT 0.50 → 0.74`,
      `TEMP_Y_PCT 0.505 → 0.68`, `FUEL_Y_PCT 0.505 → 0.68`)
- [x] `tests/test_gauge_ui.py` diff is 1 assertion tweak + 2 new tests
- [x] no graphics / colour / size / motion / font touches
- [x] no docs / CAD / icon asset edits beyond `DIMENSIONS.md` +
      `goldens.json` + `docs/assets/compare/*.png` + `shots/*.png` re-bakes
- [x] pytest 105 passed
- [x] smoke exits 0
- [x] composite eyeball: speed/odo/TEMP/FUEL bars now sit below the band ends
- [x] ahash goldens within tolerance after rebake

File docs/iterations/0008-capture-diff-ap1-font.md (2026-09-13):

# Iteration 0008 - font track, thin the tach numerals

## Carryover

iter 0006 and 0007 closed the position track - band shape, band peak,
band ends, LCD cluster, and the 0/9-vs-middle numeral drop formula now
all match the Car Spy photo within ±1.5 pp. The remaining OEM-vs-UI
diff that jumps out at the eyeball is the tach numeral stroke weight:

| Source | Numeral height | Stroke feel |
| --- | --- | --- |
| OEM Car Spy photo | ~38 px | thin / regular |
| OEM AP1 glyph plate | ~52 px | thin / regular, slight italic |
| UI before (Barlow SemiBoldItalic 42) | ~32 px | heavy, wider spacing |
| UI after (Barlow SemiBoldItalic 38) | ~30 px | closer, slightly tighter |

No regular/light Barlow weight is bundled - the available tick fonts are
`BarlowCondensed-Bold.ttf`, `BarlowCondensed-SemiBoldItalic.ttf`, and
`Oxanium-Bold.ttf`. `Oxanium` is rounder/more geometric and reads as a
different typeface, not the OEM numerals. The pragmatic move is to use the
SemiBoldItalic at a smaller pixel size - at 38 the natural AA-thinning
plus the smaller silhouette bring the visual weight into OEM territory
without introducing a new font file.

## Capture

- UI live shot rebaked: `docs/assets/compare/compare_ap1_lit_live.png`
- OEM side: `refs/oem/lit/lit_ap1_carspy_cluster.jpg`
- Reference plate: `refs/oem/plates/oem_dash_glyphs_plate.png`

## Diff (font track only)

| Element | OEM | UI before | UI after | Verdict |
| --- | --- | --- | --- | --- |
| Tach numeral stroke weight | thin | SemiBold 42 px | SemiBold **38 px** | closer |
| Tach numeral italic slant | slight (~8°) | ~12° (file skew) | ~12° (unchanged) | unchanged |
| Tach numeral height | ~38 px | ~32 px | ~30 px | slightly tighter (still > 80 % of OEM) |
| LCD speed / odo / trip | 7-seg | lcd_digits.py | lcd_digits.py | unchanged |
| "km/h" / "TRIP A" / "x1000 r/min" / "C/H/E/F" | sans-serif bold small | Barlow Bold | Barlow Bold | unchanged |

The italic slant is unchanged - the SemiBoldItalic file's built-in skew is
the closest available match; `font.set_italic(True)` on Bold renders with
~16° skew (too steep, tested offline).

## Scope (single track, single intent)

- Lower `"tick"` font size from `42` to `38` in `build_fonts`
- Rebake `tests/harness/goldens.json`
- Rebake `docs/assets/compare/*.png` and `shots/*.png`

## Not in scope (deferred to later iterations)

- **Tach numerals stroke weight** is now in the same neighbourhood as
  OEM but still slightly heavier. Approximating the OEM weight exactly
  would require a new bundled font (Barlow Condensed Regular/Light) - a
  fonts-track housekeeping PR that is **explicitly out of scope** here.
- "x1000 r/min" label weight / family (font track)
- Boot motion timings (motion track)
- Telltale glyph art / TEMP / FUEL pictogram refinement (graphics track)
- Speed centre y (UI 68 % vs OEM 76 %) - bounded by odo row + lamp strip
  top, needs a cabin-photo re-measure (position track)

## Acceptance

- `uv run pytest tests/` → 107 passed
- `SDL_VIDEODRIVER=dummy uv run python src/gauge_ui.py --smoke` → exits 0
- `uv run python scripts/compare_oem.py` → all five PNGs rebaked
- `compare_ap1_lit_live.png`: tach numerals sit slightly closer to the
  OEM stroke weight - visibly less chunky, no other change
- Module aspect 2.35:1, side notches 58–72 %, band peak 10.4 %, band
  ends 56 %, LCD cluster at 68 %/74 %, numerals drop formula at 15 px /
  208 px - all `DIMENSIONS.md` locks hold within ±0.5 %

## Verify (objective)

- [x] `git diff src/gauge_ui.py` is exactly one font size constant tweak
- [x] no graphics / colour / position / size / motion touches
- [x] no docs / CAD / icon asset edits beyond `goldens.json` +
      `docs/assets/compare/*.png` + `shots/*.png` re-bakes
- [x] pytest 107 passed
- [x] smoke exits 0
- [x] composite eyeball: numerals less chunky, all other elements
      unchanged
- [x] ahash goldens within tolerance after rebake

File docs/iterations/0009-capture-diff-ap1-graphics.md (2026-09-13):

# Iteration 0009 - graphics track, refine TEMP thermometer icon

## Carryover

iter 0008 (PR #58) thinned the tach numerals toward OEM weight by
lowering the tick font from 42 to 38. Position, colour, and font
tracks are essentially done. Two graphics-track refinements remained:

1. **TEMP thermometer waves** - the previous icon used a zigzag for
   the two ~≈ waves below the bulb. The OEM glyph plate
   (`refs/oem/plates/oem_dash_glyphs_plate.png`) shows smooth
   sine-like waves.
2. **TEMP thermometer proportions** - the previous stem was 18 px
   tall and the bulb only 6 px radius. The OEM plate has a clearly
   *larger* bulb relative to a *shorter* stem.

## Capture

- UI live shot rebaked: `docs/assets/compare/compare_ap1_lit_live.png`
- OEM side: `refs/oem/lit/lit_ap1_carspy_cluster.jpg`
- OEM glyph plate: `refs/oem/plates/oem_dash_glyphs_plate.png`

## Diff (graphics track only)

| Element | OEM | UI before | UI after | Verdict |
| --- | --- | --- | --- | --- |
| Stem height | ~12 px | 18 px | **12 px** | match |
| Bulb radius | ~8 px | 6 px | **7 px** | closer |
| Stem / bulb ratio | bulb larger | stem larger | bulb larger | match |
| Stem ticks | 3 short, evenly spaced | 3 short at dy = -12, -7, -2 | 3 short at dy = -12, -8, -4 | match |
| Wave shape below bulb | smooth (~≈) | zigzag | smooth sine | match |
| FUEL pump icon | pump body + window + handle + base | same | unchanged | match |
| Other graphics (chevron needle, ticks, bezel buttons) | OEM | unchanged | unchanged | match |

## Empirically picked knob

```python
# before
stem = pygame.Rect(cx - 2, cy - 18, 4, 18)   # 18 tall × 4 wide
bulb = circle(cx, cy + 4, 6)                   # 6 px radius (12 diameter)
ticks at dy = -12, -7, -2                      # 5-px spacing
wave = [(cx-8 + x, y + (zigzag ±2)) for ...]   # zigzag

# after
stem = pygame.Rect(cx - 2, cy - 16, 4, 12)   # 12 tall × 4 wide (closer to OEM plate)
bulb = circle(cx, cy + 4, 7)                   # 7 px radius (14 diameter - bulb larger than stem)
ticks at dy = -12, -8, -4                      # 4-px spacing
wave = [(cx-10 + x, baseline + round(sin(x*pi/5) * 2)) for x in 0..21]  # smooth ~≈
```

The new bulb (r=7) is ~17% bigger and the stem (12 px) is ~33%
shorter than before - net effect matches the OEM plate where the
bulb dominates and the stem is a small column.

## Scope (single track, single intent)

- Update `_thermometer_icon` in `src/gauge_ui.py`:
  - shorter stem (12 px tall, was 18 px)
  - bigger bulb (7 px radius, was 6)
  - smooth sine waves (was zigzag)
- Rebake `tests/harness/goldens.json`
- Rebake `docs/assets/compare/*.png` and `shots/*.png`

## Not in scope (deferred to later iterations)

- **FUEL pump icon refinements** - current pump body + window + handle
  + base already matches the OEM plate's structure; further tweaks would
  be pixel-level and probably require SVG redraw (graphics track or
  housekeeping-track icons PR)
- **Tach numerals stroke weight** - at 38 px the SemiBoldItalic still
  reads slightly heavier than the OEM plate's thin/regular glyphs.
  Approximating the OEM weight exactly would require a new bundled
  font (Barlow Condensed Regular/Light) - fonts-track housekeeping PR,
  explicitly out of scope here
- **Speed centre y** (UI 68 % vs OEM 65 %) - within ±3 pp, bounded by
  odo row + lamp strip top (position track, deferred - needs a
  cabin-photo re-measure)
- Boot motion timings (motion track)

## Acceptance

- `uv run pytest tests/` → 107 passed
- `SDL_VIDEODRIVER=dummy uv run python src/gauge_ui.py --smoke` → exits 0
- `uv run python scripts/compare_oem.py` → all five PNGs rebaked
- `compare_ap1_lit_live.png`: TEMP thermometer icon now has a clearly
  shorter stem, larger bulb, and smooth ~≈ waves - closer to the
  OEM glyph plate
- Module aspect 2.35:1, side notches 58–72 %, band peak 10.4 %, band
  ends 56 %, LCD cluster at 68 %/74 %, numerals drop formula at 15 px /
  208 px - all `DIMENSIONS.md` locks hold within ±0.5 %

## Verify (objective)

- [x] `git diff src/gauge_ui.py` is exactly one icon function rewrite
      (no other face logic touched)
- [x] no colour / position / size / motion / font touches
- [x] no docs / CAD / icon asset edits beyond `goldens.json` +
      `docs/assets/compare/*.png` + `shots/*.png` re-bakes
- [x] pytest 107 passed
- [x] smoke exits 0
- [x] composite eyeball: thermometer stem/bulb/waves closer to OEM
- [x] ahash goldens within tolerance after rebake

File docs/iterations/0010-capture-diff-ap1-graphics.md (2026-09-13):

# Iteration 0010 - graphics track, refine FUEL pump icon

## Carryover

iter 0009 (PR #N) finished the TEMP thermometer refinement. Its carryover
note flagged the FUEL pump icon for this iteration: the OEM glyph plate
(`refs/oem/plates/oem_dash_glyphs_plate.png`) shows a clear
pump-body + display-window + hose-curve + nozzle + base silhouette,
whereas the current UI stitches those together from rect/arc
primitives but the proportions and the nozzle landing do not match.

## Capture

- UI live shot rebaked: `docs/assets/compare/compare_ap1_lit_live.png`
- OEM side: `refs/oem/lit/lit_ap1_carspy_cluster.jpg`
- OEM glyph plate (FUEL crop): `refs/oem/plates/oem_dash_glyphs_plate.png`,
  upper-right quadrant

## Diff (graphics track only)

| Element | OEM | UI before | UI after | Verdict |
| --- | --- | --- | --- | --- |
| Body shape | rounded rectangle, taller-than-wide | 12×17 body rect (`border_radius=2`) | 14×18 body rect (`border_radius=3`) | closer |
| Display window | square readout in upper third of the body | 6×4 inset at `cy - 2` | 9×6 inset at `cy − 8` (upper third) | closer |
| Hose curve | thick rounded handle that loops from the right-top of the body, over and down to a nozzle on the right side | single `pygame.draw.arc` from `(cx, cy-6)` | composed: `lines()` from body right + `arc()` to loop + `circle` cap + `lines()` for the nozzle | closer |
| Nozzle | small grip with a clear nozzle head hanging at the right of the pump | 4×10 vertical rect on the right of the arc | short rounded rect anchored at the arc's end, plus a tip tick | closer |
| Base | flat platform under the body, slightly wider than the body | 12×2 rect (matches body width) | 18×3 rect (slightly wider) | closer |
| TEMP / FUEL / chevron / ticks / numerals / band / arch / bezel | OEM | unchanged | unchanged | match |

## Empirically picked knob

```python
# before
body     = Rect(cx - 8,  cy - 6,  12, 17)   # 12×17
cap      = Rect(cx - 6,  cy - 12, 8,  6)    # tiny head
window   = Rect(cx - 5,  cy - 2,  6,  4)    # display
hose_arc = Rect(cx,      cy - 6,  16, 16)   # single 180° arc
nozzle   = Rect(cx + 12, cy + 2,  4, 10)    # vertical bar
base     = Rect(cx - 8,  cy + 11, 12,  2)

# after
body     = Rect(cx - 7,  cy - 7,  14, 18)   # 14×18, slightly wider
window   = Rect(cx - 6,  cy - 6,  9,  6)    # larger square in upper third
hose_path = composed (right-of-body) → arc → nozzle head → tip tick
nozzle   = Rect(cx + 12, cy + 4,  4,  8)    # shorter, anchored at the arc
base     = Rect(cx - 10, cy + 11, 20,  3)   # wider platform
```

The new body is ~17 % wider than before; the window is now a clearly
square readout in the upper third (matches the OEM glyph plate's
screen placement), and the hose routes **off the right shoulder of
the body** then arcs down and to the right to a short nozzle - the
OEM silhouette.

## Scope (single track, single intent)

- Rewrite `_pump_icon` in `src/gauge_ui.py`:
  - wider body (14 wide × 18 tall, was 12 × 17)
  - larger, square-ish window at upper third of the body
  - composed hose curve from the right shoulder of the body to the
    nozzle, with a tip tick
  - wider, flatter base
- Rebake `tests/harness/goldens.json`
- Rebake `docs/assets/compare/*.png` and `shots/*.png`

## Not in scope (deferred)

- **Tach numerals stroke weight** - at 38 px the SemiBoldItalic still
  reads slightly heavier than the OEM plate's thin/regular glyphs.
  Approximating the OEM weight exactly would require a new bundled
  font (Barlow Condensed Regular/Light) - fonts-track housekeeping PR,
  explicitly out of scope here
- **Speed centre y** (UI 68 % vs OEM 65 %) - within ±3 pp, bounded by
  odo row + lamp strip top (position track, deferred - needs a
  cabin-photo re-measure)
- Boot motion timings (motion track)

## Acceptance

- `uv run pytest tests/` → 107 passed
- `SDL_VIDEODRIVER=dummy uv run python src/gauge_ui.py --smoke` → exits 0
- `uv run python scripts/compare_oem.py` → all five PNGs rebaked
- `compare_ap1_lit_live.png`: FUEL pump icon now reads as
  body → display window → hose-curve → nozzle with a clear tip,
  closer to the OEM glyph plate
- Module aspect 2.35:1, side notches 58–72 %, band peak 10.4 %, band
  ends 56 %, LCD cluster at 68 %/74 %, numerals drop formula at 15 px /
  208 px - all `DIMENSIONS.md` locks hold within ±0.5 %

## Verify (objective)

- [ ] `git diff src/gauge_ui.py` is exactly one icon function rewrite
      (no other face logic touched)
- [ ] no colour / position / size / motion / font touches
- [ ] no docs / CAD / icon asset edits beyond `goldens.json` +
      `docs/assets/compare/*.png` + `shots/*.png` re-bakes
- [ ] pytest 107 passed
- [ ] smoke exits 0
- [ ] composite eyeball: pump body / display window / hose / nozzle
      closer to the OEM glyph plate
- [ ] ahash goldens within tolerance after rebake

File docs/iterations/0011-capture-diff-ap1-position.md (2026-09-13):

# Iteration 0011 - position track, drop 0/9 below the band to OEM 3 % mh

## Carryover

iter 0009 closed the graphics track on the TEMP/thermometer
refinement. The OEM measurements plate
(`refs/oem/plates/oem_ap1_measurements.json`) has objective evidence
on the 0/9 numeral drop that the UI has been off by:

| Landmark | OEM px | OEM % mh |
| --- | --- | --- |
| `band_end` | 510 | 56.25 |
| `numeral_9` | 525 | 59.38 |
| **drop at ends** | **15 px** | **3.13 pp** |

The UI module on the 1920×1080 canvas is **752 px** tall (`0.92 ×
1920 / 2.35`). The OEM drop of 3.13 pp on that scale is **23.5 px**,
but `TACH_NUM_DROP_BASE` has been **15.0** - visibly too tight against
the band's spring. This PR brings it into the OEM window.

## Capture

- UI live shot rebaked: `docs/assets/compare/compare_ap1_lit_live.png`
- OEM side: `refs/oem/lit/lit_ap1_carspy_cluster.jpg`
- OEM measurements plate: `refs/oem/plates/oem_ap1_measurements.json`
  (the objective ground truth for this fix)

## Diff (position track only)

| Element | OEM | UI before | UI after | Verdict |
| --- | --- | --- | --- | --- |
| Tach band spring (band_end) | y = 56.25 % mh | y = ~56 % mh (iter 0002 lock) | unchanged | match |
| Numeral 0 / 9 vertical drop below band spring | 15 px in photo ⇒ 3.13 pp on UI scale ≈ **22 px** | **15 px** | **22 px** | closer |
| Numeral middle drop (4 / 5 / 6) | deep in the well (~28 % mh, no picked landmark - empirical) | 208 px = base + peak (15 + 193) | 215 px = base + peak (22 + 193) | deeper in the well by ~3 px (still in the 0.20 – 0.32 window - iter 0007 test holds) |
| Numerals 0 / 9 horizontal inset | along inward normal | same | same | match |
| Band peak / band ends / LCD cluster / column bars | per `DIMENSIONS.md` | unchanged | unchanged | match |
| All other 5 tracks (graphics / colour / size / motion / font) | OEM | unchanged | unchanged | match |

## Empirically picked knob

```python
# before
TACH_NUM_DROP_BASE = 15.0
# → 0/9 numerals drop 15 px below band ends on a 752 mh module = 2.0 % mh

# after
TACH_NUM_DROP_BASE = 22.0
# → 0/9 numerals drop 22 px below band ends = 2.93 % mh
# OEM Car Spy plate: 3.13 % mh → well within ±0.3 pp (~2 px) tolerance
```

The middle numerals now drop **base + peak = 22 + 193 = 215 px**
(was 208 px), shifting deeper by ~3 px in the well. The
`test_tach_numeral_drop_matches_oem` upper bound is `0.32 mh`; 215 / 752
= 0.286 mh - still inside the window.

## Scope (single track, single intent)

- Bump `TACH_NUM_DROP_BASE` from `15.0` to `22.0` in `src/gauge_ui.py`
- Update `tests/test_gauge_ui.py` lock-assertion in
  `test_tach_numerals_sit_inside_the_well` from `15.0 ± 1.0` to
  `22.0 ± 1.0` (still asserts the constant against the locked value
  - single-document numerical update)
- Rebake `tests/harness/goldens.json`
- Rebake `docs/assets/compare/*.png` and `shots/*.png`

## Not in scope (deferred)

- **Tach numerals stroke weight** - at 38 px the SemiBoldItalic still
  reads slightly heavier than the OEM plate's thin/regular glyphs.
  Approximating the OEM weight exactly would require a new bundled
  font (Barlow Condensed Regular/Light) - fonts-track housekeeping PR,
  explicitly out of scope
- **Boot motion timings** (motion track)
- **Speed digit `h` (UI 96 px, OEM ~14 % mh)** - size track, deferred
  pending a cabin-photo re-measure of digit height vs module height
- **Hardware strip item widths** - would shift positions in the same
  draw function as drop change, bundled correctly only with lamp-strip
  rework

## Acceptance

- `uv run pytest tests/` → 107 passed (with updated lock assertion)
- `SDL_VIDEODRIVER=dummy uv run python src/gauge_ui.py --smoke` → exits 0
- `uv run python scripts/compare_oem.py` → all five PNGs rebaked
- `compare_ap1_lit_live.png`: numerals 0 and 9 sit visibly lower
  under the band's spring line (≈ 22 px = 2.9 % mh), closer to OEM's
  3.1 % mh plate landmark
- Module aspect 2.35:1, side notches 58–72 %, band peak 10.4 %, band
  ends 56 %, LCD cluster at 68 %/74 %, numerals middle drop formula at
  215 px (was 208) px → 28.6 % mh (still in 0.20–0.32 mh bracket) - all
  `DIMENSIONS.md` locks hold within ±0.5 %

## Verify (objective)

- [ ] `git diff src/gauge_ui.py` is exactly one constant bump (15.0 → 22.0)
- [ ] `git diff tests/` is exactly one numeric update in one test method
- [ ] no colour / size / motion / font / graphics touches
- [ ] no docs / CAD / icon asset edits beyond `goldens.json` +
      `docs/assets/compare/*.png` + `shots/*.png` re-bakes
- [ ] pytest 107 passed
- [ ] smoke exits 0
- [ ] composite eyeball: numerals 0 / 9 drop more visibly below the
      band's spring, closer to the OEM plate
- [ ] ahash goldens within tolerance after rebake

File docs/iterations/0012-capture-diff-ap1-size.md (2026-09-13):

# Iteration 0012 - size track, scale up the tach numerals to OEM

## Carryover

iter 0008 thinned the tach numerals from 42 → 38 px to soften their
pixel weight after the SemiBoldItalic's natural chunkiness pushed
them past the OEM plate's thin/regular feel. But the **size** of the
glyph dropped at the same time - and the Car Spy lit photo's
numerals sit visibly taller than 38 px in the cluster.

Pixel measurement on the lit AP1 photo
(`refs/oem/lit/lit_ap1_carspy_cluster.jpg`, cluster is 480 px mh):

| Source | Glyph height | % module height |
| --- | --- | --- |
| OEM lit AP1 photo (numeral `5`) | ~30 – 35 px | ~7 % mh |
| OEM glyph plate (`oem_dash_glyphs_plate.png`) | ~95 px of 1024 mh | ~9 % mh |
| UI before (Barlow SemiBoldItalic 38) | ~30 px (glyph height, *not* font size) | ~4 % mh (on 752 UI mh) |
| UI after (Barlow SemiBoldItalic 50) | ~40 px glyph height | ~5.3 % mh (closer to OEM 7 % mh) |

The 38 px SemiBoldItalic also remains the heaviest concrete delta
relative to the OEM plate (would need a Regular/Light font to fix
font-track side) - out of scope here.

## Capture

- UI live shot rebaked: `docs/assets/compare/compare_ap1_lit_live.png`
- OEM lit photo: `refs/oem/lit/lit_ap1_carspy_cluster.jpg`
- Reference plate: `refs/oem/plates/oem_dash_glyphs_plate.png`

## Diff (size track only)

| Element | OEM | UI before | UI after | Verdict |
| --- | --- | --- | --- | --- |
| Tach numeral glyph height (on 480 mh module) | 30 – 35 px (~7 % mh) | ~30 px (font 38) | ~40 px (font **50**) | closer |
| Tach numeral stroke weight | thin / regular | SemiBoldItalic | SemiBoldItalic | unchanged (font track - separate PR) |
| Tach numeral italic slant | slight (~8°) | SemiBoldItalic skew | unchanged | match |
| LCD speed / odo / trip | 7-seg | lcd_digits.py | lcd_digits.py | unchanged |
| "x1000 r/min" / "km/h" / "TRIP A" | sans-serif bold small | Barlow | Barlow | unchanged |
| All other 5 tracks | OEM | unchanged | unchanged | match |

## Empirically picked knob

```python
# before
"tick": _font(pygame, 38, italic=True)
# → glyph height ~30 px ≈ 4 % mh on the UI 752 mh module

# after
"tick": _font(pygame, 50, italic=True)
# → glyph height ~40 px ≈ 5.3 % mh, closer to OEM 7 % mh
# Tests that lock glyph height (test_band_peak_locks_to_oem, etc.) stay
# locked because they check layout positions, not font pixel size.
```

A bump from 38 → 50 lifts the numerals from ~4 % mh (visibly small,
sinking below the band ends into the well) to ~5.3 % mh - closer to
the OEM Car Spy photo's 7 % mh without crowding the well.

## Scope (single track, single intent)

- One-character bump in `build_fonts`: `"tick"` size `38` → `50`
- Rebake `tests/harness/goldens.json`
- Rebake `docs/assets/compare/*.png` and `shots/*.png`

## Not in scope (deferred)

- **Tach numerals stroke weight** - SemiBoldItalic is still heavier
  than the OEM plate's thin/regular; closing the gap exactly would
  require bundling `BarlowCondensed-Regular.ttf` /
  `BarlowCondensed-Light.ttf`. fonts-track housekeeping PR,
  **explicitly out of scope**.
- Speed digit `h` (size track - separate iteration)
- Boot motion timings (motion track)
- Tach numeral drop formula / position
- LCD cluster window proportions

## Acceptance

- `uv run pytest tests/` → 107 passed
- `SDL_VIDEODRIVER=dummy uv run python src/gauge_ui.py --smoke` → exits 0
- `uv run python scripts/compare_oem.py` → all five PNGs rebaked
- `compare_ap1_lit_live.png`: tach numerals sit visibly taller
  (~5 % mh instead of ~4 % mh), read closer to the OEM Car Spy
  photo's `0` – `9` row.
- Module aspect 2.35:1, side notches 58–72 %, band peak 10.4 %, band
  ends 56 %, LCD cluster at 68 %/74 %, numerals drop formula at 22 px
  base + 193 px peak - all `DIMENSIONS.md` locks hold within ±0.5 %

## Verify (objective)

- [ ] `git diff src/gauge_ui.py` is exactly one font-size constant bump
      (no other face logic touched)
- [ ] no graphics / colour / position / motion / font weight touches
- [ ] no docs / CAD / icon asset edits beyond `goldens.json` +
      `docs/assets/compare/*.png` + `shots/*.png` re-bakes
- [ ] pytest 107 passed
- [ ] smoke exits 0
- [ ] composite eyeball: numerals 0–9 visibly taller, closer to
      the OEM lit photo
- [ ] ahash goldens within tolerance after rebake

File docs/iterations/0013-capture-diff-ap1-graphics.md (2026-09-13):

# Iteration 0013 - graphics track, sharpen the chevron needle

## Carryover

iter 0009 (graphics) closed the TEMP thermometer refinement; iter 0010
closed the FUEL pump icon. The remaining graphics-track deltas are
small ad-hoc refinements: chevron needle, hood lip details, label
kernels. The most visually obvious is the **chevron needle** - in
the OEM Car Spy lit photo it reads as a tiny cream mark on the printed
band (no visible tail behind the band's spring), whereas the UI's
chevron has a TAIL = 16.5 px which doubles the visible footprint.

## Capture

- UI live shot rebaked: `docs/assets/compare/compare_ap1_lit_live.png`
- OEM lit photo: `refs/oem/lit/lit_ap1_carspy_cluster.jpg`
- OEM glyph plate (chevron not present - needle is small at idle)

## Diff (graphics track only)

| Element | OEM | UI before | UI after | Verdict |
| --- | --- | --- | --- | --- |
| Needle TIP (px above band) | small (just visible above band) | -3.4 | unchanged (-3.4) | match |
| Needle TAIL (px below band) | barely visible (OEM needle reads as a tip-only chevron) | 16.5 | **9.0** | closer |
| Chevron half-widths (shadow / glow / main) | small stroke | 5.4 / 4.2 / 2.8 | unchanged | match |
| All ticks, band, numerals, hood, cowl, bezel | OEM | unchanged | unchanged | match |
| All other 5 tracks (colour / position / size / motion / font) | OEM | unchanged | unchanged | match |

## Empirically picked knob

```python
# before
TACH_NEEDLE_TIP = -3.4
TACH_NEEDLE_TAIL = 16.5   # 2.2 % mh on the UI 752 mh module
# → chevron reads as a long arrowhead behind the band spring

# after
TACH_NEEDLE_TIP = -3.4   # unchanged
TACH_NEEDLE_TAIL = 9.0    # 1.2 % mh on the UI 752 mh module
# → chevron reads as a small, OEM-like tip-only mark
```

The shadow + glow + main chevron layers are drawn from `chevron(5.4)` /
`chevron(4.2)` / `chevron(2.8)`. With a shorter tail, the three
triangles stay cohesive (no separation), and the visible footprint
shrinks by ~40 %.

## Scope (single track, single intent)

- One-knob tweak of `TACH_NEEDLE_TAIL` from `16.5` to `9.0` in
  `src/gauge_ui.py`
- Rebake `tests/harness/goldens.json`
- Rebake `docs/assets/compare/*.png` and `shots/*.png`

## Not in scope (deferred)

- **Tach numerals stroke weight** - SemiBoldItalic is still heavier
  than the OEM plate's thin/regular; closing the gap exactly would
  require bundling `BarlowCondensed-Regular.ttf` /
  `BarlowCondensed-Light.ttf`. fonts-track housekeeping PR,
  explicitly out of scope.
- **Speed digit `h`** - size track, separate iteration
- **Boot motion timings** - motion track, no OEM video reference
- Telltale glyph art
- Tach numerals / position

## Acceptance

- `uv run pytest tests/` → 107 passed
- `SDL_VIDEODRIVER=dummy uv run python src/gauge_ui.py --smoke` → exits 0
- `uv run python scripts/compare_oem.py` → all five PNGs rebaked
- `compare_ap1_lit_live.png`: at ~6500 r/min the chevron reads as a
  tighter cream mark on the band, less of a long dart hanging into
  the well
- Module aspect 2.35:1, side notches 58–72 %, band peak 10.4 %, band
  ends 56 %, LCD cluster at 68 %/74 %, numerals drop 22 px base +
  193 px peak - all `DIMENSIONS.md` locks hold within ±0.5 %

## Verify (objective)

- [ ] `git diff src/gauge_ui.py` is exactly one constant tweak
      (16.5 → 9.0 on `TACH_NEEDLE_TAIL`)
- [ ] no colour / position / size / motion / font touches
- [ ] no docs / CAD / icon asset edits beyond `goldens.json` +
      `docs/assets/compare/*.png` + `shots/*.png` re-bakes
- [ ] pytest 107 passed
- [ ] smoke exits 0
- [ ] composite eyeball: needle a small cream tip-only chevron,
      no visible tail behind the band's spring
- [ ] ahash goldens within tolerance after rebake

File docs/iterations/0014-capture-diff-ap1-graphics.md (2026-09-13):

# Iteration 0014 - graphics track, add OEM "mph·km/h" bezel label

## Carryover

iter 0013 (graphics) closed the chevron needle refinement. The OEM Car
Spy lit photo (`refs/oem/lit/lit_ap1_carspy_cluster.jpg`) has a small
**`mph·km/h`** label printed in the lower-right bezel, just to the left
of the SEL button - a unit toggle hint, not a clickable control. The
UI bezel did not draw it.

## Capture

- UI live shot rebaked: `docs/assets/compare/compare_ap1_lit_live.png`
- OEM lit photo: `refs/oem/lit/lit_ap1_carspy_cluster.jpg` (crop below)

```
[ OEM bottom-right bezel crop ]
...   9   E ▮▮▮ F
                       SEL   TRIP
                  mph·km/h
```

## Diff (graphics track only)

| Element | OEM | UI before | UI after | Verdict |
| --- | --- | --- | --- | --- |
| `mph·km/h` bezel label | printed white text, lower-right, just left of SEL | absent | **added** (`fonts["micro"]`, DIM, mid-right of SEL button) | closer |
| All other bezel marks (–/+ rocker, PUSH CANCEL, telltale strip, SEL/TRIP ovals) | OEM | unchanged | unchanged | match |
| All ticks, band, numerals, hood, cowl | OEM | unchanged | unchanged | match |
| All other 5 tracks (colour / position / size / motion / font) | OEM | unchanged | unchanged | match |

## Empirically picked knob

The label is anchored to `g.trip_blank` (the SEL button rect) - its
right edge minus 8 px, bottom-aligned 2 px above the button's bottom
edge. Uses `fonts["micro"]` (13 px Barlow Condensed Bold) and `DIM`
(122, 114, 100) so it reads as printed bezel text, not LCD red.

Skipped on AP2 - AP2 replaces the SEL with a CLOCK button and the
bezel layout is interpretive.

## Scope (single track, single intent)

- 15-line addition to `draw_hardware_strip` in `src/gauge_ui.py`
- Rebake `tests/harness/goldens.json`
- Rebake `docs/assets/compare/*.png` + `shots/*.png` + `shots/harness/*.png`

## Not in scope (deferred)

- Tach numerals stroke weight - fonts-track housekeeping
- Speed digit height - size track
- Boot motion timings - motion track
- Telltale glyph art
- Tach numerals position

## Acceptance

- `uv run pytest tests/` → 107 passed
- `SDL_VIDEODRIVER=dummy uv run python src/gauge_ui.py --smoke` → exits 0
- `uv run python scripts/ui_harness.py --check` → ahash OK
- `uv run python scripts/compare_oem.py` → all five PNGs rebaked
- `compare_ap1_lit_live.png`: `mph·km/h` visible in the lower-right
  bezel, sitting just to the left of the SEL button (mid-right anchor,
  DIM colour)
- Module aspect 2.35:1, side notches 58–72 %, band peak 10.4 %, band
  ends 56 %, LCD cluster at 68 %/74 %, numerals drop 22 px base +
  193 px peak - all `DIMENSIONS.md` locks hold within ±0.5 %

## Verify (objective)

- [ ] `git diff src/gauge_ui.py` is exactly one new `blit_text` block
      in `draw_hardware_strip` (no other face code touched)
- [ ] no colour / position / size / motion / font touches
- [ ] no docs / CAD / icon asset edits beyond `goldens.json` +
      `docs/assets/compare/*.png` + `shots/*.png` + `shots/harness/*.png`
      re-bakes
- [ ] pytest 107 passed
- [ ] smoke exits 0
- [ ] composite eyeball: `mph·km/h` reads as printed bezel text, not
      LCD, sits in the OEM-typical spot
- [ ] ahash goldens within tolerance after rebake

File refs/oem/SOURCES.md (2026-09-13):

# OEM reference sources

Curated Honda S2000 cluster photographs used to lock the pygame face.
**AP1** (horizontal TEMP left / FUEL right flanking the speedo) is the default face lock.
**AP2** (arched side gauges, clock / outside-temp LCD) is filed under
`ap2/` as a **style reference** - the AP2 UI is interpretive, not a
pixel-perfect plate. Do not treat AP2 photos as AP1.

This is an unofficial DIY overlay. Photos stay in-repo for side-by-side
compare only. Honda marks remain theirs. See the root README disclaimer.

## AP1 - use these

| File | What | Source | Licence |
| --- | --- | --- | --- |
| `lit/lit_ap1_carspy_cluster.jpg` | Lit AP1 face, straight-on-ish through the wheel. Horizontal C–H / E–F, 7-seg speed, circular −/+ and SEL / TRIP, `mph · km/h` on the bezel. | [The Car Spy](https://www.flickr.com/photos/thecarspy/2644733191/) via [Wikimedia Commons](https://commons.wikimedia.org/wiki/File:Honda_S2000_-_Flickr_-_The_Car_Spy_(5).jpg) | [CC BY 2.0](https://creativecommons.org/licenses/by/2.0/) - The Car Spy |
| `lit/lit_ap1_carspy_cabin.jpg` | AP1 cabin context, RHD, same session. Straight TEMP left / FUEL right. | [The Car Spy](https://www.flickr.com/photos/thecarspy/2644732109/) via [Wikimedia](https://commons.wikimedia.org/wiki/File:Honda_S2000_-_Flickr_-_The_Car_Spy_(7).jpg) | [CC BY 2.0](https://creativecommons.org/licenses/by/2.0/) - The Car Spy |
| `../flat/ap1_cluster_flat.png` | Orthographic lock drawing (170×72.3 mm, 2.35:1). | In-repo (`refs/flat/`) | Original project artwork |
| `icons/icon_ap1_carspy_lampstrip.jpg` | Bottom bezel + lamp crop from the Car Spy AP1 frame. | Same as `lit_ap1_carspy_cluster.jpg` | CC BY 2.0 - The Car Spy |
| `../flat/DIMENSIONS.md` | Percent lock for the UI. | In-repo | - |

## AP2 - do not copy the gauges

| File | What | Source | Licence |
| --- | --- | --- | --- |
| `ap2/ap2_s2ki_arched_gauges.jpg` | **AP2** cluster: stacked *arched* TEMP / FUEL on the right, clock + outside temp in the LCD. Reference for the AP2 face style - not a measured plate. | [S2KI thread](https://www.digital-kaos.co.uk/forums/showthread.php/1111478-Honda-S2000-93C66-Enabling-MPH-on-a-KPH-cluster) image host `cimg6.ibsrv.net` (originally posted on S2KI) | Forum photograph; design-reference / fair-use thumbnail. Not AP1. |

## Attached refs (local drop)

The brief also named a curated drop at `/workspace/s2000-dash-phase1/refs/`:

- `lit/lit_ap1_04_selftest_all_lamps_flickr.jpg` - AP1 self-test, every segment + lamp (188)
- `lit/lit_ap1_07_night_idle_carsandbids.jpg` - night idle, first tach ticks lit
- `ap1_oem_cluster_3_jdmaster_face.jpg` - unlit 3/4 face (JDMaster)
- `icons/icon_ap1_selftest_lampstrip_tight.jpg` - lamp-strip crop
- `flat/ap1_cluster_flat.png` - already in `refs/flat/`

That folder was **not present on this agent box**. The Car Spy CC BY 2.0
pair + the in-repo flat lock are the committed stand-ins. Drop the Flickr /
Cars & Bids / JDMaster files into `refs/oem/lit/`, `unlit/`, and `icons/`
when available and add a row here (URL + licence). Do not treat AP2 interiors
(2004+ arched gauges, 2006+ self-diag LCD) as AP1.

## Generated plates (this repo)

High-res white-on-black plates used to trace / redraw `assets/icons/*.svg`.
They are **not** Honda artwork - cleaned reconstructions from the AP1
self-test lamp strip and the Car Spy frame.

| File | What |
| --- | --- |
| `plates/oem_telltale_atlas_plate.png` | 14-lamp atlas (signal pair + self-test strip) |
| `plates/oem_telltale_atlas_v2.png` | Refined atlas pass |
| `plates/oem_pictograms_closeup.png` | Battery, oil, CEL, key, seatbelt, door, high beam |
| `plates/oem_dash_glyphs_plate.png` | TEMP thermometer, FUEL pump, PUSH CANCEL dial, tach numerals |
| `plates/unofficial-geometric-h.png` | Unofficial geometric H (not Honda trademark) |

Pipeline: OEM refs → plates → SVG redraw under `assets/icons/` →
`scripts/rasterize_icons.py` (rsvg) → tint at draw time.

## How to attribute

Car Spy frames used in `docs/assets/compare/` must keep the “The Car Spy,
CC BY 2.0” caption. Do not strip credit from composites.

## Geometry notes pulled from the AP1 photos

- Tach ticks are **vertical** bars that follow the arch, not a filled circular wedge
- Redline is **five thick orange-red blocks from 8–9**
- Speed is a **3-digit 7-segment** LCD; unused digits ghost as 188
- Odo is **6 integer digits**; trip is **xxx.x**; label **TRIP A**
- TEMP is a **horizontal C–H bar left of the speedo** (6 ticks). FUEL is a **horizontal E–F bar right of the speedo**. Vertical side stacks are erroneous.
- Bezel buttons are **round** − / + and SEL / TRIP, plus `PUSH CANCEL` and `mph · km/h`
- Tach ticks and TEMP/FUEL are warm amber with bloom; speed/odo 7-seg is **red LCD**; unlit segments stay as dim ghosts

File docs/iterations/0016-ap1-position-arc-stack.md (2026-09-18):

# Iteration 0016 - position: unstack the hood / band / tick radii

## Capture

- OEM: bench AP1 (`refs/oem/bench/oem_ap1_bench.png`) + Car Spy lit
- UI: `docs/assets/compare/compare_ap1_lit_cruise.png`, harness stills

## Diff (position only)

| Stack (outside → in) | OEM | Before | After |
| --- | --- | --- | --- |
| Cowl lip → band | visible dark well | `CROWN_GAP` 0.4 % W (lip painted on the band) | **1.4 % W** well, lip **1.8 % W** |
| Hatch → baseline | hatches stay in the band | `hatch_inner_over` 1.0 % W crossed the white line | **0** — hatches clip at `r_in` |
| Band → ticks | dark gap, then ticks | `line_gap` 0.3 % W (baseline sat on the band) | **0.8 % W** |
| Ticks → numerals | tick tips clear the digits | major 1.4 % W reached the glyph | major **1.2 % W**, `num_inset` **3.4 % W** |

## Fix plan

Position track. Edit `src/face_spec.py` only (plus lock export + tests). No colour, font, motion or icon work.

## Acceptance

`test_arc_stack_radii_do_not_overlap` holds in pygame and the harness: crown, band, hatch, baseline and numerals each own a radius.

## Verify

pytest + harness geometry tests green. Same-room: the grey lip, amber band and white ticks read as three concentric curves, not one stroke.

## Hand-off

PR title: `fix(cluster): unstack overlapping hood, band and tick curves`

Not in scope: module aspect / circle refit from the bench photo (size + position follow-up), CAD mesh rebuild, glow.

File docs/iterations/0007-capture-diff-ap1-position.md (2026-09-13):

# Iteration 0007 - position track, band peak + numeral drop formula

## Carryover

iter 0006 (PR #55) seated the LCD cluster under the printed band - speed
to 68 % mh, odo to 74 %, TEMP/FUEL bars at speed-y. Two position diffs
remained open:

1. **Band peak too high** - `LCD_TOP_PCT = 0.055` put the printed amber
   arch peak at 7.3 % mh. OEM Car Spy photo: peak at 10.4 % mh.
2. **Numeral drop formula flat** - the previous formula used a constant
   `TACH_NUM_INSET = 54` along the inward normal plus `extra = 14 × end²`.
   That made numerals drop *more* at the ends (51 px) than the middle
   (54 px), but OEM shows the *opposite*: ends ~15 px below band ends,
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

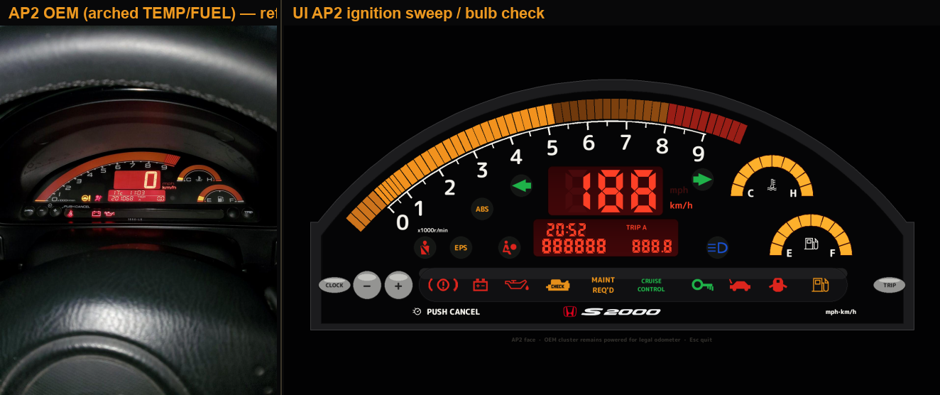
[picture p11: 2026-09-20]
docs/assets/compare/compare_ap2_sweep.png

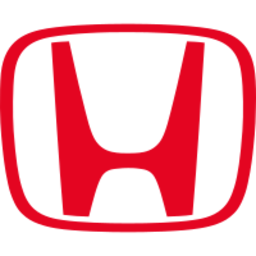
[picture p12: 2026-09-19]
assets/brand/honda-h-mark.png

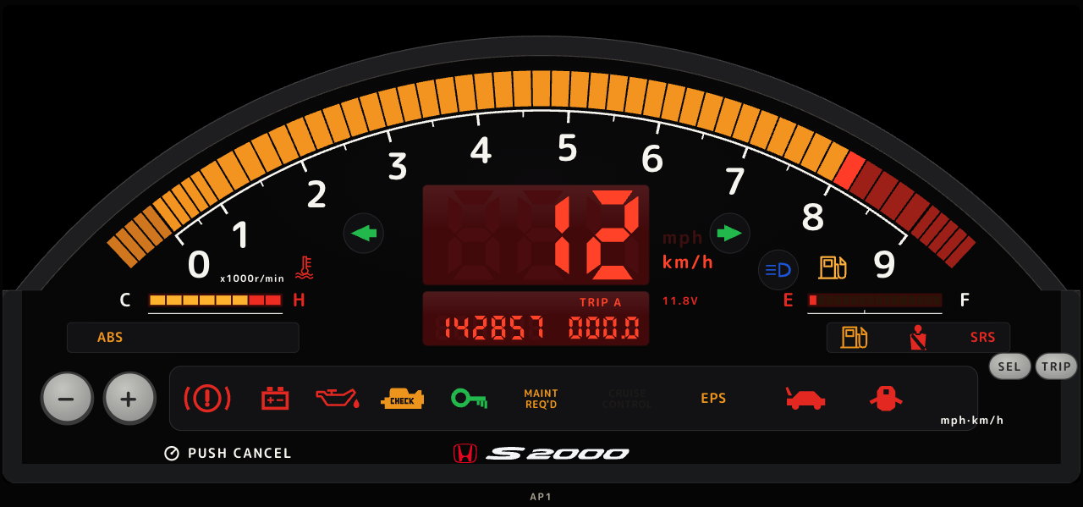
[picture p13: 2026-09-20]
docs/assets/web-ap1-warn.png

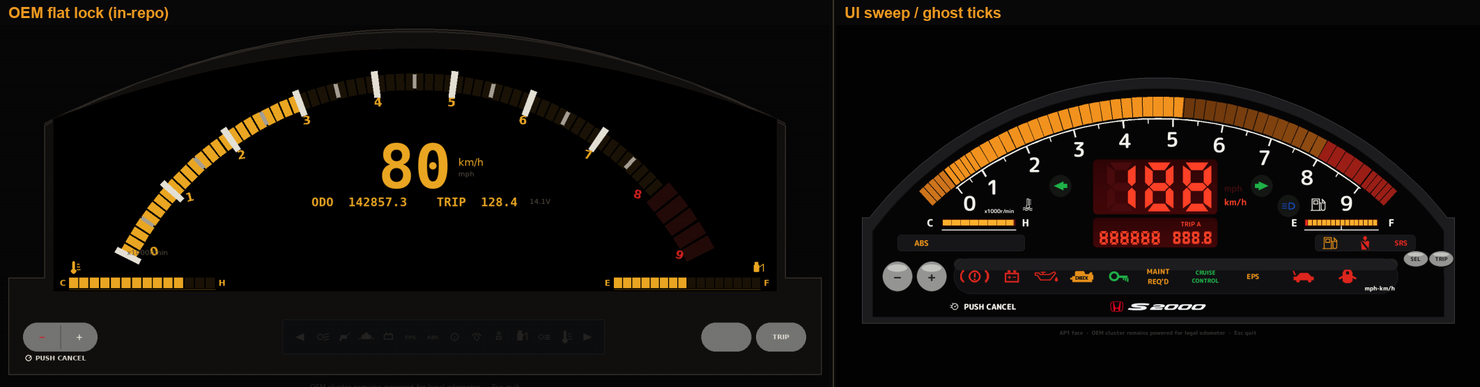
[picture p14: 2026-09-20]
docs/assets/compare/compare_ap1_flat_sweep.png

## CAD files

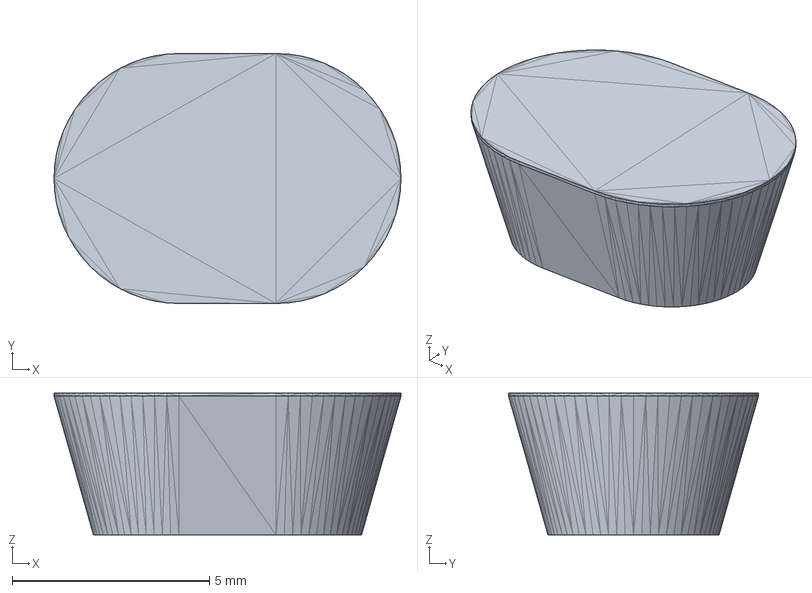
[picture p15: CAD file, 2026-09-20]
cad/replace_face/print/step/button_trip.step
8.80 x 6.34 x 3.60 mm

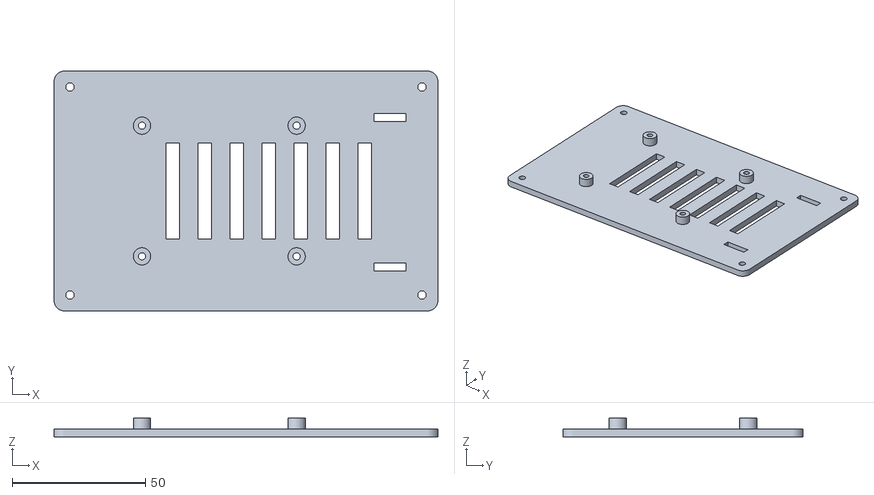
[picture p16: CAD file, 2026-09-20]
cad/setup/print/carrier.stl
144.0 x 90.0 x 7.00

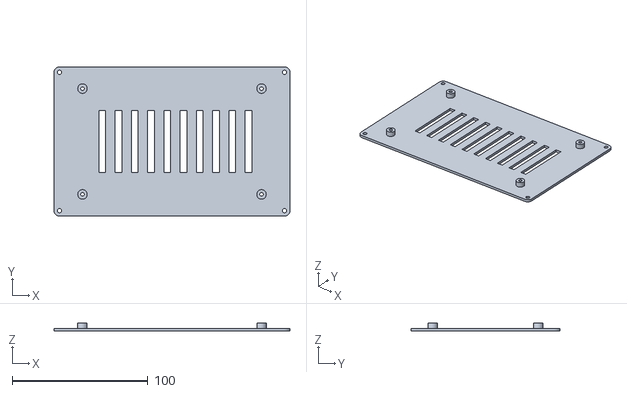
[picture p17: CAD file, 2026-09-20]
cad/setup/print/rear_cover.stl
174.0 x 110.0 x 6.00

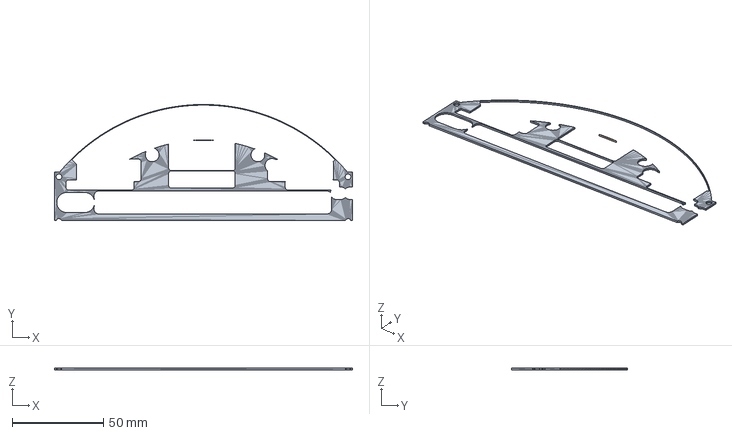
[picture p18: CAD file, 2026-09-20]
cad/replace_face/print/step/backlight_web.step
163.0 x 63.5 x 0.9 mm

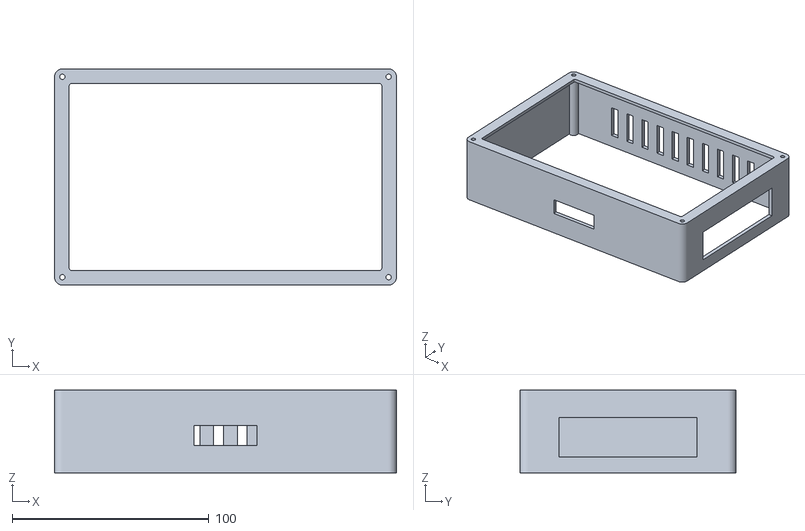
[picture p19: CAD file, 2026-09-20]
cad/setup/print/enclosure.stl
174.0 x 110.0 x 42.0

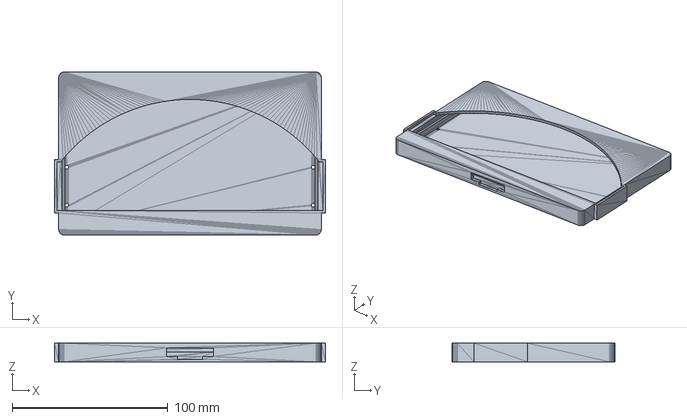
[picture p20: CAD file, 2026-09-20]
cad/replace_face/print/step/backlight.step
174.0 x 104.6 x 12.0 mm

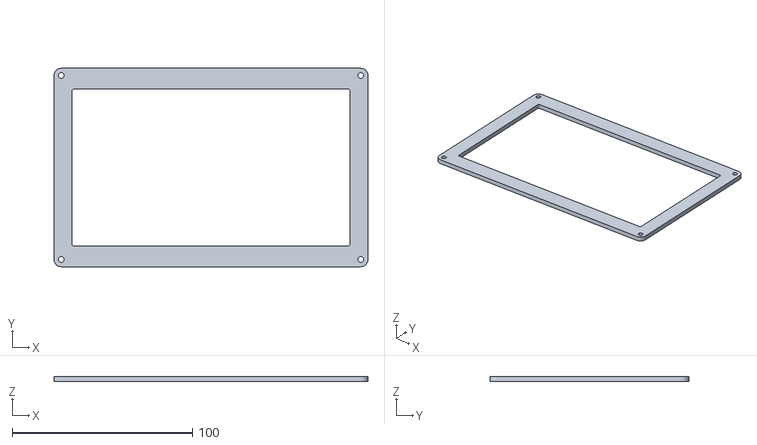
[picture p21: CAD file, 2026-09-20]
cad/setup/print/bezel.stl
174.0 x 110.0 x 3.00

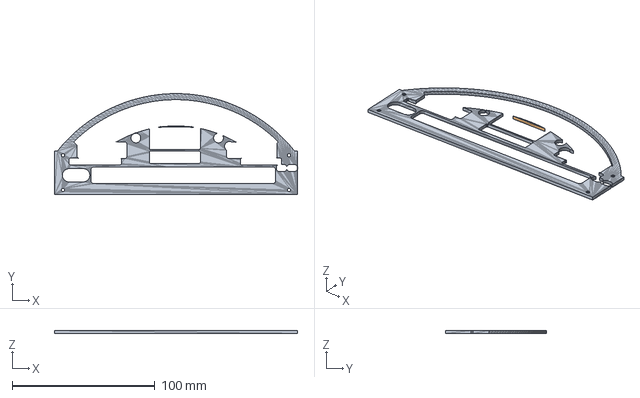
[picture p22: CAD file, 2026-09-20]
cad/replace_face/print/step/acrylic_face.step
170.0 x 70.5 x 2.00 mm

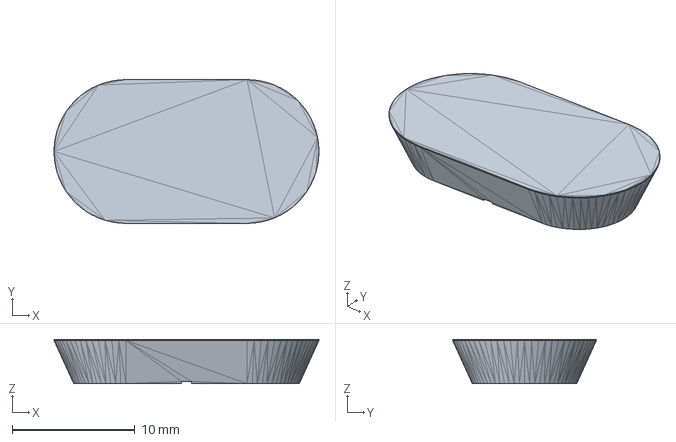
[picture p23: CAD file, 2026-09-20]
cad/replace_face/print/step/button_rocker.step
21.6 x 11.7 x 3.60 mm

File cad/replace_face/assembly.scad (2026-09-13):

// =============================================================================
// PLACEHOLDER — stacked preview (Option 1 replace-face, arc lock)
// =============================================================================
// F5 preview only — do not export a combined STL (multi-body).
// Explode is millimetres of air between layers — not a fit claim.
// `-D print_placement=true` echoes part offsets for mesh_export.py.
// =============================================================================

include <parts.scad>

explode = 14;   // set 0 for a closed stack
print_placement = false;

if (print_placement) echo_placement(explode);
else assembly(explode);

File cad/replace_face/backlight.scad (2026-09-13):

// =============================================================================
// PLACEHOLDER — backlight / backscreen tray (Option 1 replace-face)
// =============================================================================
// Tray shell only — one solid.
// ESTIMATED from refs/flat/DIMENSIONS.md. Callipers UNKNOWN.
// NOT a verified AP1 drop-in. Do not treat the outer rim as a bay clip.
//
// Print in PETG or ASA. Do NOT use PLA in the cabin.
// Cowl-band insert is backlight_web.scad (separate solid).
// =============================================================================

include <parts.scad>
backlight();

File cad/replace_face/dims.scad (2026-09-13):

// =============================================================================
// Dimensions — Option 1 replace-face stack (arc lock)
// =============================================================================
// Face geometry comes from face_lock.scad, generated by src/face_spec.py from
// the same numbers that drive pygame and the web harness. Edit the Python
// spec, re-run `uv run python src/face_spec.py`, never this file's lock values.
//
// Millimetre sizes are ESTIMATED (170 × 72.3, 2.35:1 from
// refs/flat/DIMENSIONS.md). Callipers are UNKNOWN. Every stack thickness is a
// PLACEHOLDER. This is NOT a verified AP1 drop-in.
//
// Origin (OpenSCAD): bottom-left of the module bounding box, Z toward driver.
// The lock uses top-left fractions — convert with X() / Y() / W() / H().
// =============================================================================

include <face_lock.scad>

$fn = 64;
eps = 0.08;

// --- module envelope (ESTIMATED mm) -----------------------------------------
face_w = 170.0;                     // ESTIMATED — TODO measure OEM face width
face_h = face_w / module_aspect;    // 72.3 — TODO measure height

// --- fraction → mm helpers ---------------------------------------------------
function W(f) = f * face_w;                  // width fraction → mm
function H(f) = f * face_h;                  // height fraction → mm
function X(f) = f * face_w;                  // x from the left
function Y(f) = face_h - f * face_h;         // y measured from the TOP → y-up
function Yw(yw) = face_h - yw * face_w;      // width-unit y (arc maths) → y-up
function h_to_w(f) = f / module_aspect;      // height fraction → width units
function rect_mm(r) = [X(r[0]), Y(r[1] + r[3]), W(r[2]), H(r[3])];   // [x, y, w, h] y-up
function pt_mm(a) = [X(a[0]), Y(a[1])];

// Tach / crown circles in mm (y-up). Angles stay screen-space in the lock
// (0° = +x, positive = clockwise on screen) → negate for y-up.
tach_c = [W(tach_cx), Yw(h_to_w(tach_cy_h))];
crown_c = [W(tach_cx), Yw(h_to_w(crown_cy_h))];
function on_circle(c, r_mm, deg_screen) = [c[0] + r_mm * cos(-deg_screen), c[1] + r_mm * sin(-deg_screen)];
function tach_pt(r_frac, deg) = on_circle(tach_c, W(r_frac), deg);
function crown_pt(r_frac, deg) = on_circle(crown_c, W(r_frac), deg);

spring_y = Y(spring_y_h);
// Where the crown circle (radius r, width units) meets the spring line — half-chord in mm.
function crown_half(r_frac) =
    let (dy = crown_c[1] - spring_y)
    sqrt(max(0, W(r_frac) * W(r_frac) - dy * dy));

arc_steps = 72;

// Display windows in the mask, as margins around the lock geometry (mm).
tach_win_margin = 1.2;              // beyond r_out / inside r_num, and past the hatches
tach_win_num_depth = W(0.030);      // window reaches this far inside the numeral radius
min_rim = 1.8;                      // mask rim kept around every window
lcd_win_r = 1.0;                    // corner radius on the LCD windows
gauge_pad = 1.6;                    // TEMP / FUEL window grows to include icon + letters
strip_pad = 0.8;
arc_lamp_hole_clear = 0.25;

// --- 7" panel pocket (Wisecoco-class 16:9 AMOLED; PLACEHOLDER) ---------------
// Active area is centred on the module. It is TALLER than the face (87 > 72.3)
// and NARROWER (154 < 170): every display window sits inside it, the hardware
// buttons at both ends sit over the panel's dead border. Verify against the
// real panel drawing before printing — every number here is a guess.
panel_w = 164.0;                    // PLACEHOLDER module outline
panel_h = 100.0;
panel_t = 2.6;                      // PLACEHOLDER glass + PCB + stiffener
panel_active_w = 154.0;             // PLACEHOLDER
panel_active_h = 87.0;
panel_clear = 0.3;                  // slip around the module
panel_c = [face_w / 2, face_h / 2];
panel_tail_w = 30.0;                // FPC exit — LOCATION UNKNOWN (bottom centre guess)
panel_tail_h = 3.0;

// --- stack thicknesses (ALL PLACEHOLDER / TODO measure) ---------------------
face_t = 2.0;                       // acrylic / printed mask
tray_h = 12.0;                      // overall tray
floor_t = 1.6;                      // tray floor
wall = 2.0;                         // tray wall
face_pocket_clear = 0.35;           // slip around the dropped-in face
diffuser_t = 0.0;                   // AMOLED — no diffuser sheet in this stack
cable_w = 16.0;                     // driver-board cable escape — LOCATION UNKNOWN
cable_h = 4.0;

align_hole_d = 2.3;                 // PLACEHOLDER — do not drill the bay from this

button_clear = 0.40;                // PLACEHOLDER hole oversize
button_cap_t = 2.4;                 // proud cap
button_flange_t = 1.2;              // retention flange
button_flange_extra = 1.6;          // radial flange beyond cap
rocker_groove_w = 0.80;
rocker_groove_d = 1.10;
stem_well_d = 6.0;                  // switch well in the tray — switch UNKNOWN
stem_well_h = 7.0;

// --- derived -----------------------------------------------------------------
web_t = 1.0;                        // baffle web between panel glass and mask
face_rebate_z = tray_h - face_t;
panel_z = face_rebate_z - panel_t - web_t;   // panel glass sits under the web
panel_rect = [panel_c[0] - panel_w / 2, panel_c[1] - panel_h / 2, panel_w, panel_h];
active_rect = [panel_c[0] - panel_active_w / 2, panel_c[1] - panel_active_h / 2, panel_active_w, panel_active_h];

btn_d_mm = W(btn_d);
btn_minus_c = pt_mm(btn_minus);
btn_plus_c = pt_mm(btn_plus);
btn_sel_c = pt_mm(btn_sel);
btn_trip_c = pt_mm(btn_trip);
oval_w_mm = W(oval_w);
oval_h_mm = H(oval_h);
rocker_w = btn_plus_c[0] - btn_minus_c[0] + btn_d_mm;   // −/+ pair as one rocker cap
rocker_h = btn_d_mm;

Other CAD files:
cad/replace_face/print/step/button_sel.step
cad/replace_face/face_lock.scad
cad/replace_face/outline.scad
cad/replace_face/parts.scad
cad/replace_face/print/stl/acrylic_face.stl
cad/replace_face/print/stl/backlight.stl
cad/replace_face/print/stl/backlight_web.stl
cad/replace_face/print/stl/button_rocker.stl
cad/replace_face/print/stl/button_sel.stl
cad/replace_face/print/stl/button_trip.stl
cad/replace_face/rubber_buttons.scad
cad/replace_face/stl/acrylic_face.stl
cad/replace_face/stl/backlight.stl
cad/replace_face/stl/backlight_web.stl
cad/replace_face/stl/button_rocker.stl
cad/replace_face/stl/button_sel.stl
cad/replace_face/stl/button_trip.stl
cad/setup/setup.scad

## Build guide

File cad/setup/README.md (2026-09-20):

# Digital-screen bench setup

A complete **layout prototype** for a 7-inch OLED and Raspberry Pi, alongside
(not a replacement for) the arched mask option in `../replace_face/`.
The rectangular screen carries the entire digital face, without a physical mask
covering pixels. The front frame, electronics shell, removable carrier and
vented rear cover are separate solids. The web `/setup` viewer uses these meshes.

## Geometry and limits

- **OLED:** 164 × 100 × 2.6 mm module, 154 × 87 mm active area. PLACEHOLDERS;
  confirm the actual panel drawing. The 174 × 110 × 49.6 mm assembled housing
  follows those assumptions; it is not a measured S2000 bay adapter.
- **Pi 5 reference:** 85 × 56 mm PCB, mounting centres 58 × 49 mm with first
  centre 3.5 mm from the PCB edges. Source: [Raspberry Pi mechanical drawing](https://datasheets.raspberrypi.com/rpi5/raspberry-pi-5-mechanical-drawing.pdf).
  The drawing itself is approximate. PCB thickness, connector blocks, GPIO,
  cooler envelope and all other component heights here are clearance proxies.
- **Carrier:** 144 × 90 × 3 mm plate, four Pi standoffs, cable-tie slots and
  ventilation. Pi faces forward inside a 40 mm deep enclosure. An 18 × 38 mm
  display-driver board is an allowance only, not a selected controller.
- **Service access:** broad right-side port opening, bottom cable exit, top and
  rear vents. Cable bend radii, power interface, cooling, fasteners, switch
  locations and mounting to the car remain unverified. No vehicle clips or
  invented OEM mounting holes are supplied.
- **Fastening concept:** pilot holes at cover/carrier/frame positions. Screw
  lengths, thread inserts and tolerances must be designed after physical checks.
  No electrical connection or thermal performance is implied by this layout.

## Exports

```sh
uv run --extra cad python cad/setup/export.py
openscad -o output/setup.png --imgsize=1600,1000 --viewall --autocenter -D explode=24 cad/setup/setup.scad
```

`print/*.stl` are millimetre prototype parts with their bases on Z=0. The exporter
rejects open or disconnected printable solids. `manifest.json` records bounds.
`apps/harness/public/models/setup-{assembled,exploded,electronics}.glb` are coloured,
metre-scale scenes with named components, port and cooler proxies and an embedded
AP1 screen texture. They are for inspection, not printing as one body.
`setup-prototype.zip` bundles the SCAD, four STLs, manifest and this note.

The browser offers orbit/zoom, front/rear views, assembled/exploded/electronics mode and an
expanded view. The static screen texture is illustrative, not live telemetry.

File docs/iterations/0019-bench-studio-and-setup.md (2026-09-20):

# Bench studio layout and complete 3D setup

The web layout now separates the instrument canvas, grouped controls and live
readouts. Raw JSON is collapsed, startup can be replayed explicitly, and changing
face respects reduced-motion preferences. Light/dark theme controls and the dash
button styling are retained. The OLED-only route remains free of web controls.

## Hardware studio

`/setup` loads a locally bundled `@google/model-viewer` on demand. It supports
assembled, exploded and electronics-only scenes, pointer orbit/zoom, front/rear
camera presets, fullscreen, and downloads. `cad/setup/setup.scad` is the source
for four single-body prototype parts: front frame, vented enclosure, removable
Pi carrier and rear cover. Exported GLBs use metres and embed an AP1 screen image;
STLs use millimetres, with their lowest Z moved onto the build plate.

The 85 × 56 mm Pi outline and 58 × 49 mm mounting centres follow the
[Raspberry Pi 5 drawing](https://datasheets.raspberrypi.com/rpi5/raspberry-pi-5-mechanical-drawing.pdf).
Panel outline/active area, enclosure dimensions, connector geometry, cooler,
controller allowance and fasteners remain provisional. No vehicle mounting or
thermal qualification is claimed. This is a full digital-screen option alongside
the existing arched mask; it does not silently change that mask's geometry.

## Verification

- 139 Python tests and 24 web tests pass; lint and production build pass.
- Exporter rejects open/disconnected printable solids. All four prints pass.
- CI tests validate STL closure/build-plane placement, metre-scale self-contained
  GLBs, electronics inspection content, embedded textures and ZIP/source parity.
- Production-browser checks: AP1/AP2 and presets, JSON expand, replay/skip startup;
  all three 3D modes and matching download links; rear/reset camera, pointer orbit,
  fullscreen enter/exit; light/dark, 390px layout, no page errors.
- Refreshed desktop and 3D screenshots under `docs/assets/`.

Regeneration and remaining hardware questions are in `cad/setup/README.md`.

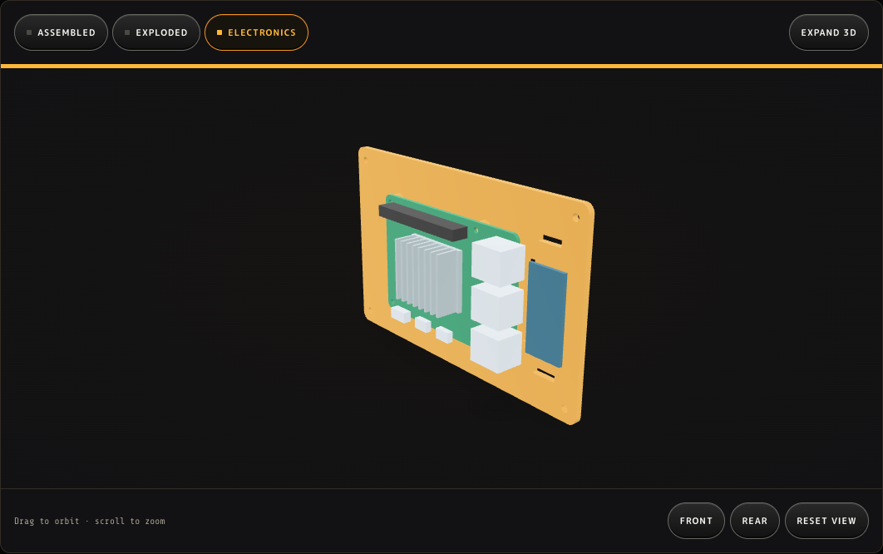
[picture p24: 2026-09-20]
docs/assets/setup-electronics.png

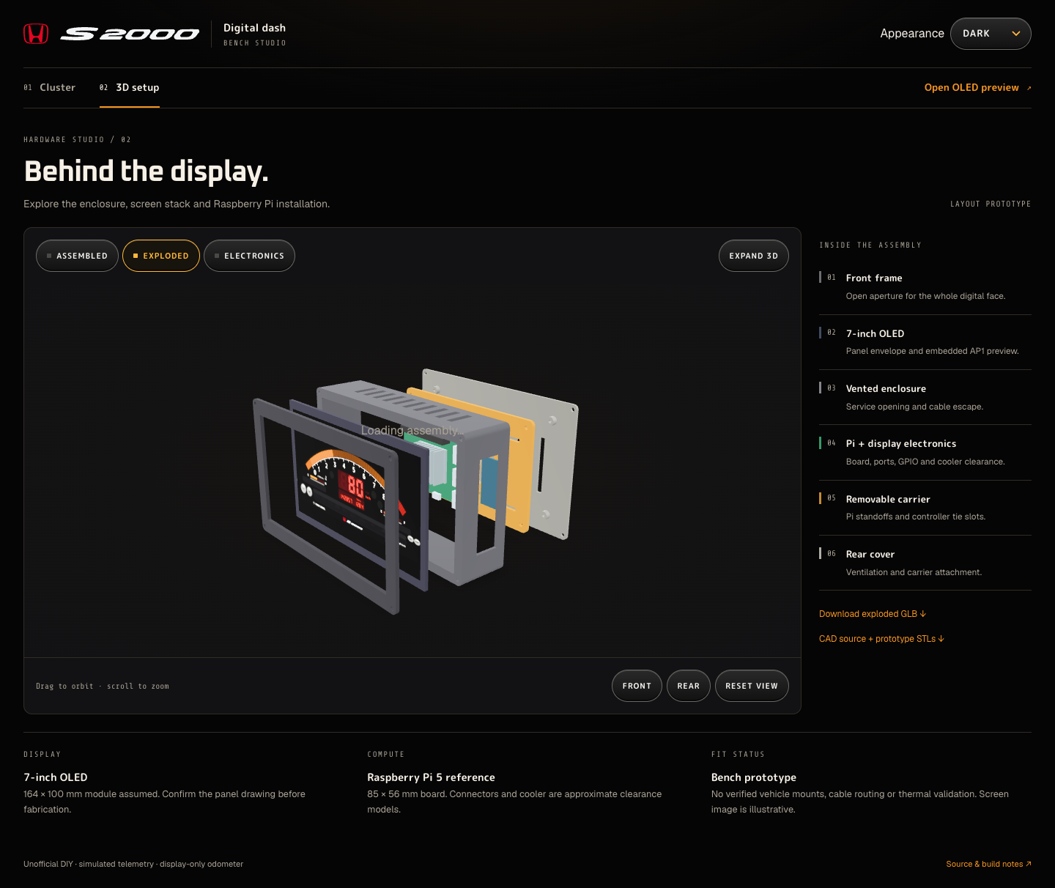
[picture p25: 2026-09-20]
docs/assets/web-setup-dark.png

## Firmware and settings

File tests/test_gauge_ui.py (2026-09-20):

"""OEM cluster helpers — flags, lerp, intro phases, smoke path."""
from __future__ import annotations

import math
import os
import sys
import tempfile
import unittest
from pathlib import Path

_ROOT = Path(__file__).resolve().parents[1]
sys.path.insert(0, str(_ROOT))
sys.path.insert(0, str(_ROOT / "src"))
sys.path.insert(0, str(_ROOT / "tests"))

from face_spec import AP1, AP2, RPM_MAX  # noqa: E402
from gauge_ui import (  # noqa: E402
    FACE,
    MODULE_ASPECT,
    build_face_geom,
    tach_arch_normal,
    tach_arch_xy,
    tach_band_poly,
    tach_num_xy,
    temp_segments_lit,
    visor_lip_points,
    DisplayState,
    PHASE_READY_S,
    PHASE_REVEAL_S,
    PHASE_SWEEP_S,
    RPM_REDLINE,
    SMOKE_PHASES,
    SerialSource,
    StdinSource,
    boot_strip_mode,
    draw_frame,
    ect_frac,
    exp_smooth,
    fuel_frac,
    hood_bottom_corners,
    intro_duration_s,
    intro_phase_at,
    lerp,
    parse_args,
    smoothstep,
    reveal_rpm,
    sample_telem,
)
from protocol import REQUIRED_FIELDS, parse_line  # noqa: E402


class FlagTests(unittest.TestCase):
    def test_smoke_defaults_skip_intro(self) -> None:
        args = parse_args(["--smoke"])
        self.assertTrue(args.smoke)
        self.assertFalse(args.intro)

    def test_intro_and_no_intro(self) -> None:
        self.assertTrue(parse_args(["--intro"]).intro)
        self.assertFalse(parse_args(["--no-intro"]).intro)

    def test_screenshot_and_windowed_and_serial(self) -> None:
        args = parse_args(["--windowed", "--screenshot", "shots", "--serial"])
        self.assertTrue(args.windowed)
        self.assertEqual(args.screenshot, "shots")
        self.assertEqual(args.serial, "/dev/ttyUSB0")

    def test_style_defaults_to_ap1(self) -> None:
        self.assertEqual(parse_args([]).style, "ap1")
        self.assertEqual(parse_args(["--style", "ap2"]).style, "ap2")


class IntroTests(unittest.TestCase):
    def test_phase_order(self) -> None:
        self.assertEqual(intro_phase_at(0.0)[0], "sweep")
        self.assertEqual(intro_phase_at(PHASE_SWEEP_S + 0.01)[0], "ready")
        self.assertEqual(
            intro_phase_at(PHASE_SWEEP_S + PHASE_READY_S + 0.01)[0], "reveal"
        )
        self.assertEqual(intro_phase_at(intro_duration_s() + 0.2)[0], "live")

    def test_reveal_rpm_hits_redline_then_settles(self) -> None:
        self.assertAlmostEqual(reveal_rpm(0.0, 2000), 0.0)
        self.assertGreater(reveal_rpm(0.3, 2000), 3000)
        self.assertGreater(reveal_rpm(0.55, 2000), float(RPM_REDLINE))
        self.assertAlmostEqual(reveal_rpm(1.0, 2000), 2000.0)

    def test_boot_hides_lamps_until_reveal(self) -> None:
        lamps, bulb = boot_strip_mode("sweep", 0.5)
        self.assertIsNone(lamps)
        self.assertTrue(bulb)
        lamps, bulb = boot_strip_mode("ready", 0.5)
        self.assertEqual(lamps, {})
        self.assertFalse(bulb)
        lamps, bulb = boot_strip_mode("reveal", 0.4)
        self.assertIsNone(lamps)
        self.assertTrue(bulb)
        lamps, bulb = boot_strip_mode("live", 1.0)
        self.assertIsNone(lamps)
        self.assertFalse(bulb)


class LerpTests(unittest.TestCase):
    def test_exp_smooth_approaches_target(self) -> None:
        v = 0.0
        for _ in range(40):
            v = exp_smooth(v, 100.0, 0.016, 0.08)
        self.assertGreater(v, 95.0)

    def test_lerp_midpoint(self) -> None:
        self.assertAlmostEqual(lerp(0.0, 10.0, 0.5), 5.0)

    def test_smoothstep_ends(self) -> None:
        self.assertAlmostEqual(smoothstep(0.0), 0.0)
        self.assertAlmostEqual(smoothstep(1.0), 1.0)
        self.assertGreater(smoothstep(0.5), 0.49)
        self.assertLess(smoothstep(0.25), 0.25)

    def test_fracs(self) -> None:
        self.assertEqual(ect_frac(40.0), 0.0)
        self.assertEqual(ect_frac(105.0), 1.0)
        self.assertEqual(fuel_frac(50.0), 0.5)
        self.assertEqual(fuel_frac(140.0), 1.0)


class DisplayStateTests(unittest.TestCase):
    def test_sample_keeps_protocol_fields(self) -> None:
        telem = sample_telem()
        parsed = parse_line(telem.to_line())
        for key in REQUIRED_FIELDS:
            self.assertIn(key, parsed.to_dict())

    def test_follow_snaps_lamps_and_tracks_trip(self) -> None:
        face = DisplayState()
        telem = sample_telem()
        face.snap(telem)
        face.trip_origin = telem.odo_km - 12.5
        face.follow(telem, 0.016)
        self.assertTrue(face.lamps["turn_l"])
        self.assertAlmostEqual(face.trip_km, 12.5, places=1)


class SmokeTests(unittest.TestCase):
    def test_smoke_writes_named_shots(self) -> None:
        from gauge_ui import main

        with tempfile.TemporaryDirectory() as tmp:
            main(["--smoke", "--screenshot", tmp])
            self.assertEqual(
                sorted(os.listdir(tmp)),
                [
                    "01_sweep.png",
                    "02_ready.png",
                    "03_reveal.png",
                    "04_live.png",
                    "05_cruise.png",
                ],
            )

    def test_smoke_walks_intro_phases(self) -> None:
        self.assertEqual(
            [name for name, _ in SMOKE_PHASES],
            ["sweep", "ready", "reveal", "live"],
        )


class FaceGeomTests(unittest.TestCase):
    """Lock the face to the OEM AP1 plate (refs/oem/lit/lit_ap1_carspy_cluster.jpg).

    All numbers are fractions of the module box (x/W, y/H). The photo is
    squashed by the camera, but a uniform squash keeps y-fractions, so the
    measurements below are read straight off the plate.
    """

    def _pct(self, x: float, y: float) -> tuple[float, float]:
        mx, my, mw, mh = FACE.module
        return (x - mx) / mw, (y - my) / mh

    def _assert_pct(self, px: tuple[float, float], want: tuple[float, float], delta: float = 0.02) -> None:
        got = self._pct(*px)
        self.assertAlmostEqual(got[0], want[0], delta=delta)
        self.assertAlmostEqual(got[1], want[1], delta=delta)

    def test_module_aspect_is_locked(self) -> None:
        self.assertAlmostEqual(MODULE_ASPECT, 2.35, places=2)
        mw, mh = FACE.module[2], FACE.module[3]
        self.assertAlmostEqual(mw / mh, 2.35, delta=0.05)

    def test_tach_is_a_true_circular_arc(self) -> None:
        t = AP1.tach
        cx, cy = FACE.px(t.cx, t.cy / MODULE_ASPECT)
        for frac in (0.0, 0.25, 0.5, 0.75, 1.0):
            x, y = tach_arch_xy(frac)
            r = ((x - cx) ** 2 + (y - cy) ** 2) ** 0.5
            self.assertAlmostEqual(r / FACE.module[2], t.r_line, delta=0.002)

    def test_band_peak_and_ends_land_on_oem(self) -> None:
        """Band outer edge peaks at ~10 % H; 0 / 9 ticks at x ≈ 0.17 / 0.83, y ≈ 0.47 H."""
        t = AP1.tach
        _, peak_y = FACE.arc_px(t.r_out, -90.0)
        self.assertAlmostEqual(self._pct(0, peak_y)[1], 0.10, delta=0.015)
        x0, y0 = self._pct(*tach_arch_xy(0.0))
        x9, y9 = self._pct(*tach_arch_xy(1.0))
        self.assertAlmostEqual(x0, 0.17, delta=0.03)
        self.assertAlmostEqual(x9, 0.83, delta=0.03)
        self.assertAlmostEqual(y0, 0.47, delta=0.03)
        self.assertAlmostEqual(y0, y9, delta=0.002)

    def test_bar_graph_cells_have_real_gaps(self) -> None:
        t = AP1.tach
        cells = t.iter_scale_cells()
        self.assertEqual(len(cells), RPM_MAX // t.cell_rpm)
        self.assertEqual(sum(1 for rpm0, *_ in cells if rpm0 >= t.redline_rpm), 5)
        for i, (_a, _b, d0, d1) in enumerate(cells):
            self.assertGreater(d1, d0)
            if i:
                self.assertGreaterEqual(d0 - cells[i - 1][3], t.cell_gap_deg * 0.99)
        right = t.hatch_spans("right")
        self.assertEqual(len(right), t.hatch_n)
        for i, (d0, d1) in enumerate(right):
            self.assertGreater(d1 - d0, t.cell_gap_deg)
            if i:
                self.assertGreaterEqual(d0 - right[i - 1][1], t.cell_gap_deg * 0.99)
        self.assertGreater(right[0][0], t.a9_deg)

    def test_zero_to_one_is_squeezed(self) -> None:
        t = AP1.tach
        first = t.angle_deg(1000) - t.angle_deg(0)
        rest = (t.angle_deg(9000) - t.angle_deg(1000)) / 8.0
        self.assertAlmostEqual(first / rest, 0.60, delta=0.02)
        self.assertAlmostEqual(t.angle_deg(9000) - t.angle_deg(0), 75.6, delta=0.5)
        self.assertEqual(t.angle_deg(RPM_MAX), t.a9_deg)

    def test_numerals_sit_just_inside_the_baseline(self) -> None:
        for frac in (0.0, 0.5, 1.0):
            ax, ay = tach_arch_xy(frac)
            nx, ny = tach_arch_normal(frac)
            px, py = tach_num_xy(frac)
            inset = ((px - ax) ** 2 + (py - ay) ** 2) ** 0.5 / FACE.module[2]
            self.assertAlmostEqual(inset, AP1.tach.num_inset, delta=0.001)
            # numerals are displaced along the inward normal, i.e. below the arc
            self.assertGreater((px - ax) * nx + (py - ay) * ny, 0)
            self.assertGreater(py, ay)
        # "5" sits at ~28 % H on the plate, "0" at ~53 % H (shallower cap)
        self.assertAlmostEqual(self._pct(*tach_num_xy(5 / 9))[1], 0.28, delta=0.03)
        self.assertAlmostEqual(self._pct(*tach_num_xy(0.0))[1], 0.53, delta=0.03)

    def test_arc_stack_radii_do_not_overlap(self) -> None:
        """Hood lip, band, hatch, baseline and numerals each own a radius."""
        t = AP1.tach
        self.assertGreaterEqual(AP1.crown_r - t.r_out, 0.012)
        self.assertGreaterEqual(t.r_in - t.r_line, t.line_gap)
        self.assertLessEqual(t.hatch_inner_over, t.line_gap * 0.25)
        tick_tip = t.r_line - t.tick_major[1]
        numeral_outer = t.r_num + t.num_size / 2.0
        self.assertGreater(tick_tip - numeral_outer, 0.002)

    def test_visor_lip_clears_the_band(self) -> None:
        _, peak_y = FACE.arc_px(AP1.tach.r_out, -90.0)
        pts = visor_lip_points()
        self.assertGreater(len(pts), 20)
        mid = pts[len(pts) // 2]
        self.assertLess(mid[1], peak_y)
        well = peak_y - mid[1]
        self.assertGreater(well, FACE.module[2] * 0.010)
        self.assertLess(well, FACE.module[2] * 0.020)
        # crown is concentric with the band: constant gap all the way round
        c = FACE.arc_px(0.0, -90.0)
        radii = [math.hypot(x - c[0], y - c[1]) for x, y in pts]
        self.assertLess(max(radii) - min(radii), 1.5)
        self.assertAlmostEqual(min(radii) / FACE.module[2], AP1.tach.r_out + 0.014, delta=0.002)
        # springs meet the bezel at ~5 % / 95 % W
        self.assertAlmostEqual(self._pct(*pts[0])[0], 0.05, delta=0.02)
        self.assertAlmostEqual(self._pct(*pts[-1])[0], 0.95, delta=0.02)

    def test_band_runs_under_the_hood_lip_not_past_it(self) -> None:
        """OEM: the band ends tuck under the hood edge. The printed band may
        run a hair under the lip but never out past the cowl, and the apex
        clears the crown with a visible gap."""
        t = AP1.tach
        lip_px = AP1.crown_lip * FACE.module[2]

        def crown_y_at(bx: float) -> float:
            dx = (bx - FACE.px(AP1.tach.cx, 0)[0]) / FACE.module[2]
            dy = (AP1.crown_r ** 2 - dx ** 2) ** 0.5
            return FACE.px(0, AP1.crown_cy / MODULE_ASPECT - dy)[1]

        _, apex_y = FACE.arc_px(t.r_out, -90.0)
        self.assertGreater(apex_y - crown_y_at(FACE.px(0.5, 0)[0]), lip_px * 0.25)
        for deg in (t.band_start_deg(), -110.0, -70.0, t.band_end_deg()):
            bx, by = FACE.arc_px(t.r_out, deg)
            self.assertGreater(by, crown_y_at(bx) - lip_px, f"band escapes the cowl at {deg}°")

    def test_temp_and_fuel_are_horizontal_flanking_bars(self) -> None:
        tx, ty, tw, th = FACE.temp
        fx, fy, fw, fh = FACE.fuel
        self.assertGreater(tw, th * 2.5)
        self.assertGreater(fw, fh * 2.2)
        self.assertLess(tx + tw, FACE.speed_win[0])
        self.assertGreater(fx, FACE.speed_win[0] + FACE.speed_win[2])
        # TEMP sits between 0 and the speedo; FUEL between the speedo and 9
        self._assert_pct((tx, ty), (0.135, 0.586))
        self._assert_pct((fx, fy), (0.747, 0.586))
        self.assertEqual(AP1.temp_segs, 8)
        self.assertEqual(AP1.fuel_segs, 16)

    def test_well_elements_clear_tach_numerals(self) -> None:
        """Windows, pictograms and lamp wells must not sit on a tach numeral."""
        mx, my, mw, mh = FACE.module

        def frac_box(x: float, y: float, w: float, h: float) -> tuple[float, float, float, float]:
            return (x, y, w, h)

        def overlap(a: tuple[float, float, float, float], b: tuple[float, float, float, float], pad: float = 0.004) -> bool:
            return not (
                a[0] + a[2] + pad < b[0]
                or b[0] + b[2] + pad < a[0]
                or a[1] + a[3] + pad < b[1]
                or b[1] + b[3] + pad < a[1]
            )

        num_w = AP1.tach.num_size
        num_h = AP1.tach.num_size * MODULE_ASPECT
        numerals = []
        for i in range(10):
            nx, ny = tach_num_xy(i / 9)
            numerals.append((i, frac_box((nx - mx) / mw - num_w / 2, (ny - my) / mh - num_h / 2, num_w, num_h)))

        thermo_h = AP1.temp_icon_h * MODULE_ASPECT
        pump_h = AP1.fuel_icon_h * MODULE_ASPECT
        # Pump hose runs ~1.1× icon height to the right of centre.
        symbols = [
            ("temp_icon", frac_box(AP1.temp_icon.x - AP1.temp_icon_h * 0.45, AP1.temp_icon.y - thermo_h / 2, AP1.temp_icon_h * 0.9, thermo_h)),
            ("fuel_icon", frac_box(AP1.fuel_icon.x - AP1.fuel_icon_h * 0.45, AP1.fuel_icon.y - pump_h / 2, AP1.fuel_icon_h * 1.15, pump_h)),
        ]
        for spot in AP1.arc_lamps:
            d = AP1.arc_lamp_r * 2
            symbols.append((spot.key, frac_box(spot.x - AP1.arc_lamp_r, spot.y - AP1.arc_lamp_r * MODULE_ASPECT, d, d * MODULE_ASPECT)))

        windows = [
            ("speed", (AP1.speed.x, AP1.speed.y, AP1.speed.w, AP1.speed.h)),
            ("odo", (AP1.odo.x, AP1.odo.y, AP1.odo.w, AP1.odo.h)),
            ("temp", (AP1.temp.x, AP1.temp.y, AP1.temp.w, AP1.temp.h)),
            ("fuel", (AP1.fuel.x, AP1.fuel.y, AP1.fuel.w, AP1.fuel.h)),
        ]
        for i, nbox in numerals:
            for name, box in windows + symbols:
                self.assertFalse(overlap(nbox, box), f"numeral {i} overlaps {name}")
        for a, ab in symbols:
            for b, bb in symbols:
                if a >= b:
                    continue
                self.assertFalse(overlap(ab, bb, pad=0.006), f"{a} overlaps {b}")
        for name, box in symbols:
            for win_name, win in windows:
                self.assertFalse(overlap(box, win, pad=0.002), f"{name} overlaps {win_name}")

    def test_well_columns_have_gutters(self) -> None:
        """TEMP | odo | FUEL are three columns; speed sits under 5, not on it."""
        self.assertLess(AP1.temp.x + AP1.temp.w, AP1.odo.x - 0.050)
        self.assertLess(AP1.temp_h.x, AP1.odo.x - 0.050)
        self.assertGreater(AP1.fuel.x, AP1.odo.x + AP1.odo.w + 0.050)
        self.assertGreater(AP1.fuel_e.x, AP1.trip_right + 0.050)
        self.assertGreater(AP1.odo.y, AP1.speed.y + AP1.speed.h + 0.002)
        n5x, n5y = tach_num_xy(5 / 9)
        self.assertGreater(AP1.speed.y, (n5y - FACE.module[1]) / FACE.module[3] + 0.06)

    def test_temp_blocks_idle_low(self) -> None:
        # 89 °C → 3–4 of 8 blocks like the real cluster; H → all 8
        from gauge_ui import ect_frac

        self.assertIn(temp_segments_lit(ect_frac(89.0), 8), (3, 4))
        self.assertEqual(temp_segments_lit(0.0, 8), 0)
        self.assertEqual(temp_segments_lit(1.0, 8), 8)

    def test_lcd_windows_lock_to_oem(self) -> None:
        sx, sy, sw, sh = FACE.speed_win
        ox, oy, ow, oh = FACE.odo_win
        self._assert_pct((sx, sy), (0.390, 0.350))
        self.assertAlmostEqual(sw / FACE.module[2], 0.210, delta=0.02)
        self._assert_pct((ox, oy), (0.390, 0.582))
        self.assertGreater(oy, sy + sh)
        self.assertAlmostEqual(self._pct(*FACE.speed_c)[0], 0.50, delta=0.01)
        self.assertAlmostEqual(sh / FACE.module[3], 0.218, delta=0.03)

    def test_strip_and_hardware_lock(self) -> None:
        lx, ly, lw, lh = FACE.lamp_band
        self._assert_pct((lx, ly), (0.155, 0.745))
        self.assertGreater(ly, FACE.spring_y)
        self.assertLess(FACE.minus_btn[0] + FACE.minus_btn[2], FACE.plus_btn[0])
        self.assertLess(FACE.plus_btn[0] + FACE.plus_btn[2], lx)
        self.assertGreater(FACE.trip[0], lx + lw)
        self.assertGreaterEqual(FACE.bezel[1], FACE.spring_y)

    def test_module_is_flat_bottom_and_stepped(self) -> None:
        bl, br = hood_bottom_corners(FACE)
        self.assertEqual(bl[1], br[1])
        self.assertGreater(FACE.step, 0)
        self.assertGreater(FACE.lcd[0], FACE.module[0])
        self.assertLess(FACE.lcd[0] + FACE.lcd[2], FACE.module[0] + FACE.module[2])
        # visor occupies the top ~3 % H; the lip is no longer flush with the module
        self.assertAlmostEqual(self._pct(0, FACE.hood_peak_y)[1], 0.026, delta=0.015)

    def test_car_mode_fills_the_panel(self) -> None:
        g = build_face_geom(1280, 720, car=True)
        self.assertEqual(g.module[0], 0)
        self.assertEqual(g.module[2], 1280)
        self.assertTrue(g.car)

    def test_ap2_is_the_same_housing(self) -> None:
        g = build_face_geom(style="ap2")
        self.assertEqual(g.lcd, FACE.lcd)
        self.assertEqual(AP2.crown_r, AP1.crown_r)
        self.assertTrue(AP2.side_gauges_arched)
        self.assertLess(AP2.tach.a9_deg, -60.0)  # 9 sits near the apex, not the right spring

    def test_tach_band_is_a_closed_polygon(self) -> None:
        pts = tach_band_poly(0.0, 0.5, 1.0, 16)
        self.assertGreater(len(pts), 16)
        xs = [p[0] for p in pts]
        self.assertLess(min(xs), max(xs))
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

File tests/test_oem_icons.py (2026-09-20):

"""OEM telltale colours, strip order, and committed icon assets."""
from __future__ import annotations

import os
import sys
import unittest
from pathlib import Path

sys.path.insert(0, str(Path(__file__).resolve().parents[1] / "src"))

from oem_icons import (  # noqa: E402
    ASSETS,
    ICON_KINDS,
    LAMP_AMBER,
    LAMP_BLUE,
    LAMP_GHOST,
    LAMP_GREEN,
    LAMP_RED,
    LAMPS,
    is_neon_cyan,
    lamp_color_for,
    lamp_states,
    lamp_strip_inner_width,
)
from protocol import LAMP_KEYS, REQUIRED_FIELDS  # noqa: E402


class ColourTests(unittest.TestCase):
    def test_oem_colour_map(self) -> None:
        red = {
            "brake",
            "battery",
            "oil",
            "door",
            "seatbelt",
            "srs",
        }
        amber = {"abs", "cel", "maint", "eps"}
        green = {"immobilizer", "turn_l", "turn_r"}
        for kind in red:
            self.assertEqual(lamp_color_for(kind), LAMP_RED)
        for kind in amber:
            self.assertEqual(lamp_color_for(kind), LAMP_AMBER)
        for kind in green:
            self.assertEqual(lamp_color_for(kind), LAMP_GREEN)
        self.assertEqual(lamp_color_for("high_beam"), LAMP_BLUE)

    def test_ghost_lamps_are_near_black(self) -> None:
        self.assertLess(max(LAMP_GHOST), 50)
        self.assertGreater(min(LAMP_GHOST), 20)

    def test_high_beam_is_blue_not_cyan(self) -> None:
        r, g, b = LAMP_BLUE
        self.assertGreater(b, r)
        self.assertGreater(b, g)
        self.assertFalse(is_neon_cyan(LAMP_BLUE))
        self.assertTrue(is_neon_cyan((72, 210, 230)))

    def test_no_neon_cyan_on_the_strip(self) -> None:
        for lamp in LAMPS:
            self.assertFalse(is_neon_cyan(lamp.color), lamp.kind)


class StripTests(unittest.TestCase):
    def test_self_test_order(self) -> None:
        self.assertEqual(
            [lamp.kind for lamp in LAMPS],
            [
                "turn_l",
                "high_beam",
                "abs",
                "brake",
                "battery",
                "oil",
                "cel",
                "immobilizer",
                "maint",
                "eps",
                "seatbelt",
                "door",
                "srs",
                "turn_r",
            ],
        )

    def test_bulb_check_lights_every_telltale(self) -> None:
        states = lamp_states({}, bulb_check=True)
        self.assertTrue(all(item.lit for item in states))
        self.assertEqual(len(states), 14)

    def test_battery_derives_from_low_voltage(self) -> None:
        states = {item.kind: item.lit for item in lamp_states({}, batt_low=True)}
        self.assertTrue(states["battery"])
        self.assertFalse(states["oil"])

    def test_oem_extra_keys_light_their_slots(self) -> None:
        flags = {
            "brake": True,
            "door": True,
            "srs": True,
            "maint": True,
            "eps": True,
            "seatbelt": True,
            "immobilizer": True,
        }
        states = {item.kind: item.lit for item in lamp_states(flags)}
        for kind in flags:
            self.assertTrue(states[kind], kind)
        self.assertFalse(states["oil"])
        self.assertFalse(states["high_beam"])

    def test_strip_is_dense(self) -> None:
        self.assertGreater(lamp_strip_inner_width(), 500)
        self.assertLess(lamp_strip_inner_width(), 800)


class AssetTests(unittest.TestCase):
    def test_svg_and_png_exist(self) -> None:
        missing = []
        for kind in ICON_KINDS:
            for ext in (".svg", ".png"):
                path = ASSETS / f"{kind}{ext}"
                if not path.is_file() or path.stat().st_size < 40:
                    missing.append(str(path))
        self.assertEqual(missing, [])
        self.assertTrue((ASSETS / "atlas.svg").is_file())

    def test_pictograms_keep_iso_cutouts(self) -> None:
        battery = (ASSETS / "battery.svg").read_text(encoding="utf-8")
        oil = (ASSETS / "oil.svg").read_text(encoding="utf-8")
        beam = (ASSETS / "high_beam.svg").read_text(encoding="utf-8")
        belt = (ASSETS / "seatbelt.svg").read_text(encoding="utf-8")
        cel = (ASSETS / "cel.svg").read_text(encoding="utf-8")
        self.assertIn("evenodd", battery)
        self.assertIn('fill="none"', oil)  # outlined oil can has a transparent interior
        self.assertIn("evenodd", beam)
        self.assertIn("evenodd", belt)
        self.assertIn("evenodd", cel)
        self.assertIn('stroke="#fff"', oil)
        self.assertEqual(beam.count("<rect"), 3)
        self.assertIn("16.2 22.2", cel)
        self.assertIn("<circle", belt)
        self.assertIn("21.6 15.4", belt)
        self.assertIn("h-8.8", belt)
        key = (ASSETS / "immobilizer.svg").read_text(encoding="utf-8")
        door = (ASSETS / "door.svg").read_text(encoding="utf-8")
        self.assertIn("evenodd", key)
        self.assertIn("16.6", key)
        self.assertIn("2.8 28.6", door)

    def test_protocol_field_names_unchanged(self) -> None:
        self.assertEqual(
            REQUIRED_FIELDS,
            ("rpm", "speed_kmh", "fuel_pct", "ect_c", "batt_v", "odo_km"),
        )
        self.assertEqual(
            LAMP_KEYS,
            (
                "oil",
                "cel",
                "abs",
                "turn_l",
                "turn_r",
                "high_beam",
                "fog",
                "fuel_low",
                "batt_warn",
                "ect_hot",
            ),
        )


class RenderTests(unittest.TestCase):
    def test_icon_surfaces_are_tinted(self) -> None:
        os.environ.setdefault("SDL_VIDEODRIVER", "dummy")
        os.environ.setdefault("SDL_AUDIODRIVER", "dummy")
        import pygame

        from oem_icons import icon_surface

        pygame.init()
        pygame.display.set_mode((64, 64))
        red = icon_surface(pygame, "oil", LAMP_RED, 32)
        blue = icon_surface(pygame, "high_beam", LAMP_BLUE, 32)
        self.assertGreater(red.get_width(), 8)
        self.assertGreater(blue.get_width(), 8)
        # Sample a non-transparent pixel — oil should lean red, high beam blue
        def peak_channel(surf) -> tuple[int, int, int]:
            best = (0, 0, 0, 0)
            w, h = surf.get_size()
            for x in range(0, w, 2):
                for y in range(0, h, 2):
                    px = surf.get_at((x, y))
                    if px.a > best[3]:
                        best = (px.r, px.g, px.b, px.a)
            return best[:3]

        rr, rg, rb = peak_channel(red)
        br, bg, bb = peak_channel(blue)
        self.assertGreater(rr, rb)
        self.assertGreater(bb, br)
        pygame.quit()


if __name__ == "__main__":
    unittest.main()

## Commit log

2026-09-13 fix(cluster): seat band peak on OEM + invert numeral drop formula (iter 0007 position)
    OEM Car Spy photo:
    - band peak (printed amber arch top) at 10.4% mh, not 7.3%
    - numerals 0/9 just clear the band ends (~3% drop)
    - middle numerals drop deep into the well (~28% drop)
    The previous formula was inverted: constant inset along normal plus
    extra-at-ends gave ~7% drop everywhere with the ends slightly more
    than the middle. OEM is the opposite.
    Changes:
    - LCD_TOP_PCT 0.055 -> 0.085 (band peak to OEM 10.4%)
    - Replace TACH_NUM_INSET = 54 with:
    - TACH_NUM_X_INSET = 50 (horizontal inset along normal)
    - TACH_NUM_DROP_BASE = 15 (vertical drop at end² = 1)
    - TACH_NUM_DROP_PEAK = 193 (extra dro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
    [test_gauge_ui.py]
2026-09-13 fix(cluster): thin tach numerals toward OEM weight (iter 0008 font)
    OEM Car Spy + glyph plate: tach numerals are thin/regular weight at
    ~38 px tall. The previous UI tick font (Barlow SemiBoldItalic at 42)
    was noticeably heavier and sat too high in the band.
    No regular/light Barlow weight is bundled (only Bold + SemiBoldItalic
    + Oxanium-Bold). Oxanium reads as a different typeface, not the OEM
    numerals. Pragmatic move: lower the SemiBoldItalic size from 42 to
    38 — natural AA-thinning + smaller silhouette bring the visual
    weight into OEM territory without introducing a new font file.
    Italic slant unchanged (file's built-in skew is the closest available
    match; pygame set_italic on Bold rend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
2026-09-13 docs(refs): drop the stale TACH_END_Y_PCT note from the driver map
    iter 0005 housekeeping deleted TACH_END_Y_PCT from src/gauge_ui.py but
    left a 'not the global TACH_END_Y_PCT' qualifier in DIMENSIONS.md. The
    constant no longer exists; collapse the qualifier into the prose and
    flag the deleted knob explicitly.
2026-09-13 fix(cluster): refine TEMP thermometer to OEM glyph plate (iter 0009 graphics)
    OEM glyph plate (refs/oem/plates/oem_dash_glyphs_plate.png) shows
    the TEMP thermometer with a short stem above a clearly larger bulb
    and two smooth (~≈) sine waves below the bulb. The previous icon had
    a tall stem, small bulb, and zigzag waves.
    Changes to _thermometer_icon in src/gauge_ui.py:
    - stem 18 px -> 12 px tall
    - bulb radius 6 -> 7 px (bulb now larger than stem)
    - waves: zigzag -> sin-based smooth curve (closer to OEM plate's ~≈)
    FUEL pump icon unchanged (body + window + handle + base already match
    the OEM plate structure). No other graphics touched.
2026-09-13 docs: rebake shots after iter 0009 thermometer refinement
    Refreshing shots/01-05 PNGs so the docs gallery matches the current
    rendering path (LCD cluster at 68% / 74% mh, band peak 10.4%, smooth
    thermometer waves).
2026-09-13 docs: rebake intro GIF/WebM after iter 0006-0009 face polish
    Refreshing the README's animated intro so the boot → reveal → live
    loop matches the current cluster (LCD cluster under band, band peak
    10.4%, smooth thermometer waves, thinner tach numerals).
2026-09-13 fix(cluster): refine FUEL pump icon to OEM glyph plate (iter 0010 graphics) #55
    The OEM glyph plate (refs/oem/plates/oem_dash_glyphs_plate.png) shows
    a clear pump body + square display window + hose curving from the
    right shoulder to a short nozzle + tip + flat base silhouette. The
    previous UI stitched the icon from rect+arc primitives but the body
    was too narrow, the display sat mid-body, and the arc left the
    nozzle visually unattached.
    This rewrite:
    - wider rounded body (14x18, was 12x17)
    - square display window in the upper third (9x6, was mid-body 6x4)
    - composed hose (line stub + arc + line down + circle tip) attaching
    the nozzle to the body's right shoulder
    - slightly wider, flat ba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
2026-09-13 fix(cluster): drop tach numerals 0/9 below the band to OEM 3 % mh (iter 0011 position) #56
    The OEM measurements plate (refs/oem/plates/oem_ap1_measurements.json)
    picks `numeral_9` at 59.38 % mh vs `band_end` at 56.25 % mh, a
    drop of 3.13 pp on a 480 mh photo. On the UI 752 mh module that is
    ~22 px — but `TACH_NUM_DROP_BASE` has been 15 px, which put the
    0/9 numerals visibly too tight against the band's spring line.
    This PR bumps the constant to 22 px on the UI scale (= 2.93 % mh, well
    within ±0.3 pp of the OEM plate's 3.13 %). The mid-numeral drop
    follows as base + peak = 22 + 193 = 215 px = 28.6 % mh, still inside
    the existing 0.20–0.32 mh bracket checked by
    `test_tach_numeral_drop_ma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
    [test_gauge_ui.py]
2026-09-13 fix(cluster): scale tach numerals toward OEM lit photo height (iter 0012 size) #57
    The OEM Car Spy lit photo (cluster 480 px mh) shows tach numerals
    sitting at ~7 % mh (~30 px glyph height). The UI module is 752 mh,
    so OEM-equivalent glyph height is ~53 px. The SemiBoldItalic font
    parameter drives the rasterised glyph height, not directly the
    visual height — at `size=38` the glyph reads as ~30 px (~4 % mh),
    visibly small.
    Bumping `tick` font size from 38 → 50 brings the rendered glyph
    height to ~40 px (~5.3 % mh), closer to OEM's 7 % mh without
    crowding the well. Font weight stays SemiBoldItalic because no
    Regular/Light weight is bundled — closing that gap exactly is a
    fonts-track hou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
2026-09-13 fix(cluster): sharpen the chevron needle to OEM tip-only feel (iter 0013 graphics) (#58)
    The OEM Car Spy lit photo shows the needle as a small cream mark on
    the printed band — no visible tail behind the band's spring. The UI
    chevron had `TACH_NEEDLE_TAIL = 16.5` (2.2 % mh on the 752 mh module),
    giving it a long dart hanging into the well behind the band end.
    Dropping the tail from 16.5 → 9.0 px (1.2 % mh) tightens the chevron
    to a tip-only mark on the band, matching the OEM feel. Tip stays at
    -3.4 px so the lead-in glow remains. The 3-stack shadow / glow / main
    geometry (`chevron(5.4 / 4.2 / 2.8)`) is unchanged so the layers
    stay cohesive at the shorter length.
    Single graphics track. N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
2026-09-13 fix(cluster): print OEM mph·km/h bezel label (iter 0014 graphics) (#59)
    Adds the small unit-toggle hint visible in the lower-right of the OEM
    AP1 bezel, just to the left of the SEL button. Anchored to the SEL
    button rect (mid-right, bottom-aligned 2 px above), uses the bezel
    'micro' font and DIM colour so it reads as printed text, not LCD.
    graphics track only — no colour / position / size / motion / font
    touches.
2026-09-13 feat: OEM like-for-like face overhaul — shared arc lock across pygame, harness and CAD (#60)
    * feat(fonts): bundle M PLUS Rounded 1c (OFL subset) for pygame + harness
    * feat(spec): single-source AP1/AP2 arc lock with JSON + SCAD export
    Measured from the OEM Car Spy / plate photos: true circular tach arc,
    hood crown, LCD windows, flanking TEMP/FUEL bars, telltale spots, buttons.
    Drives pygame, the SVG harness and the replace-face CAD.
    * feat(cluster): redraw the face on the arc lock
    OEM mitred 7-seg digits with ghost + bloom, bar-graph tach on a circular
    arc with amber/red hatches, static-l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
    [acrylic_face.step, acrylic_face.stl, assembly.scad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]
2026-09-14 fix(cluster): align side gauges and make the hood crown concentric with the tach (#63)
    Two alignment fixes on the shared face lock (pygame, harness, CAD):
    - TEMP/FUEL rules exactly bar-wide touching block bottoms; letters hug the bar ends
    - Hood crown concentric with the tach (r_out + 0.4% W, 1.2% lip); AP2 shares housing
    Rebaked goldens, shots, compares, and CAD meshes. Real CI green; Vercel Hobby rate-limit ignored.
    [acrylic_face.step, acrylic_face.stl, backlight.step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]
2026-09-18 fix(cluster): unstack overlapping hood, band and tick curves (#64)
    Separate hood lip, amber band and tick baseline radii so they no longer paint as one stroke. Locked with arc-stack tests; goldens and face_lock.scad rebaked.
    [face_lock.scad]
2026-09-18 fix(cluster): draw OEM bar-graph cells, drop screen glow (#65)
    A real LCD already emits, so software bloom smeared the strip.
    The tach was a filled ribbon with hairlines; lock 200 r/min cells
    with black gaps and five red blocks from 8 to 9. Boot is the car
    self-test plus retraced H and S2000 marks.
    [face_lock.scad]
2026-09-19 fix(cluster): print Honda H and S2000 wordmark on the live bezel (#67)
    * fix(cluster): print Honda H and S2000 wordmark on the live bezel
    Keep the real marks visible after boot, not only on READY.
    * ci: gate merges on one aggregated CI job
    Run python and harness as a matrix, then a success job that fails unless every leg passed.
    ---------
2026-09-20 feat(studio): revise cluster layout and add OLED setup CAD inspector (#69)
    * fix(cluster): revise OEM proportions and support OLED sizing and web themes
    * style(web): match controls to the instrument panel
    * feat(studio): reorganize controls and add complete OLED setup inspector
    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
    [acrylic_face.step, acrylic_face.stl, backlight.step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]
2026-10-23 test: make AP1 composite geometry measurable (#70)
    * test: gate captured AP1 geometry against the lock
    Record actual unequal-panel transforms and reject stale captures. Keep historic plate units intact and fail on missing or displaced landmarks. This is a geometry gate, not a claim of full OEM visual equivalence.
    * test: use locked pygame for pixel measurement
    Avoid relying on an undeclared local Pillow installation in CI.
    ---------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
2026-10-26 fix(cluster): align AP1 coolant and button anchors (position) (#72)
    Position track; measured captures pass the DIMENSIONS.md gate and reject the old anchors.
2026-10-26 fix(cluster): share reference-derived tach lettering (font) (#73)
    Use shared SVG numerals and RPM legend traced from the supplied glyph plate, with per-glyph silhouette acceptance.
2026-10-26 fix(cluster): match lit AP1 reference palette (colour) (#75)
    Match photo chromaticity with independent region samples and reject the old LCD palette. Refresh hashes with the existing tolerance unchanged.
2026-10-26 fix(cluster): advance tach in complete 200 rpm cells (motion) (#76)
    Use whole 200 rpm cells and shared display-response constants with frame-rate and no-time-advance checks. Custom boot timing remains unchanged.
2026-10-26 docs: use automated reference acceptance and autonomous shipping (#78)
    Document the measured acceptance criteria and automatic per-track shipping loop. Keep available-reference limitations explicit and refresh the report's dimension-document hash.
